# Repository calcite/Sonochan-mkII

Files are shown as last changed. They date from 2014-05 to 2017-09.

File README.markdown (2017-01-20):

# ==<| Sonochan mkII |>==
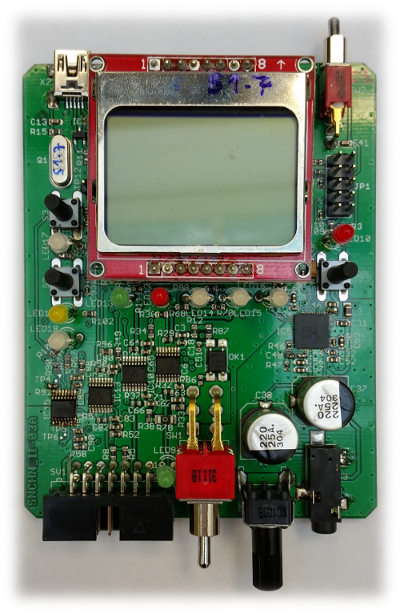
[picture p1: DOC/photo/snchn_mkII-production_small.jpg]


## Description
 * Polymorph usb soundcard (USB <--> [I2S/DSP/LJF/RJF]) based on "SDR Widget"
   project
 * On board is already codec which can sniff I2S/DSP/RJF/LJF bus
  (RX or TX data)
 * For normal operation no extra drivers needed. Using standard drivers
   included in nearly all operating systems
 * Development is also possible at Windows and Linux
 * Updating FW is possible directly through USB interface (drivers are part of
   programmer SW). No external tool needed.

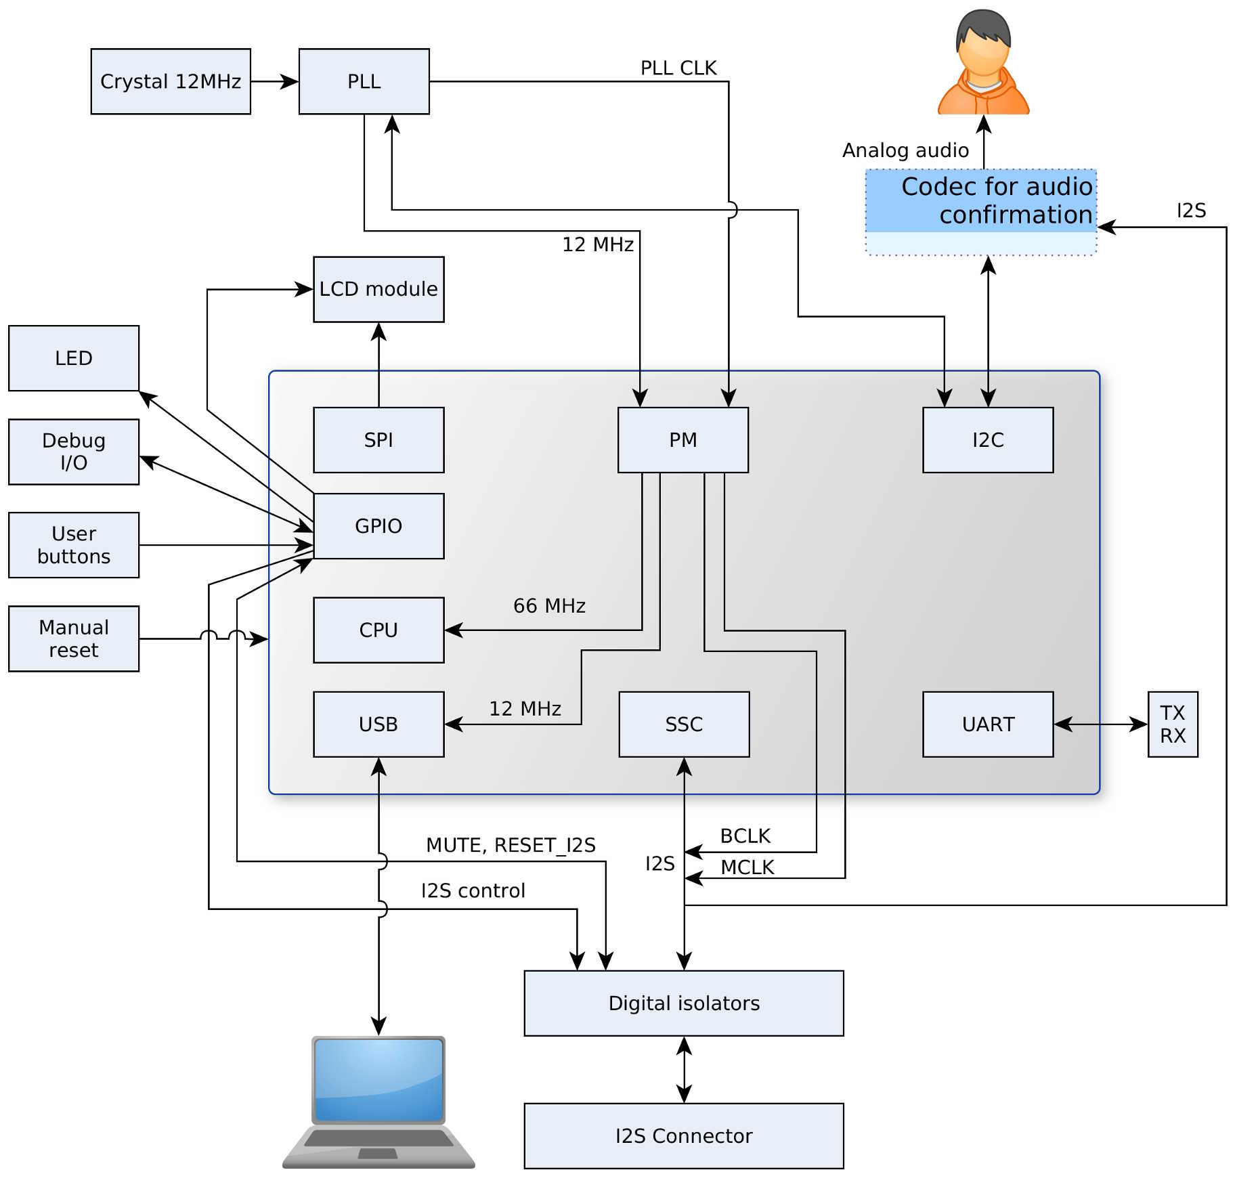
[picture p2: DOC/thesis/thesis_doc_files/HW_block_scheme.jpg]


## Parameters
 * CPU: AVR32 UC3A3256
 * As clock source generator is used CS2200
 * On board is DAC TLV320AIC33 
 * Supported sampling frequencies: 8000, 11025, 16000, 22050, 24000, 32000,
   44100 and 48000 Hz
 * Supported digital audio interfaces: I2S, DSP, Left justified,
   Right justified
 * Bit precision: up to 24 bit
 * Control thru USB HID (HW bridge uniprot)
 * Device is highly configurable (master/slave, BCLK oversampling, MCLK
   oversampling, MCLK offset, word offset, word precision...)
 * Debug messages can be sent through UART interface (115200-8-N-1). This pin
   is wired out to 2.54 pin header -> easy to connect

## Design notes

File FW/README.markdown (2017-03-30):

# Preamble
 * IF YOU WANT MODIFY FW, PLEASE READ THIS PARAGRAPH !!!
 * Please, please and once more please DO NOT USE "TABS"! I spend on this
   project more than 2 years and tabs do only problems. Just use SPACES
   instead (2 SPACES for offsets).
 * Why spaces instead of tabs? Because tab interpretation can be at every
   editor different. So when somebody change code and someone other want
   to read it, it can be very hard to read. And because tab length is not
   strictly defined, line length could be over 80 characters. Maybe you do not
   realize, but even nowadays 80 characters length have meaning (specially if
   you develop on laptop/netbook, which have small display).
 * Please also try to keep line length UP TO 80 CHARACTERS. Keep compassion
   with those they do not have large display.
 * When you use spaces, wide is strictly defined and it displays to all users
   same. No doubt about it. Also in Python is recommended to use spaces instead
   of tabs, so it is good habit for Pythonists.
 * Bottom line: USE SPACES (2 for offset) and DO NOT WRITE MORE THAN 80
   CHARACTERS AT ONE LINE.
 * Thanks                         Martin Stejskal

# Compilation

## Compilation under Linux
 * As first make sure, that you have installed `make` (Try type `make`to
   console). If appears something like `command not found`, then you
   need to install `make` (please use uncle Google)
 * Open file `compile_on_linux.sh` and edit line begun with
   `PATH=${AVR32BIN:=` . Just change path to `avr32-bin` command. Example:
`PATH=${AVR32BIN:=/opt/non-portage/avr32-tools/bin}:$PATH`
 * Make sure, that heareds were copied to `avr32-tools/avr32/include/`
   else compilation will fail.
 * If needed `chmod 755 compile_on_linux.sh` (script will be executable)
 * run `./compile_on_linux.sh` 

## Compilation under Windows
 Basicly project need only `make` (and basic programs like `rm`, `cp` and so
 on), `objcopy`, `avr32gcc` and standard AVR32 libraries.
 So easiest way is install Atmel Studio 6 and just set correct paths in file
 `compile_on_windows.bat`. Or you can install just basic programs
 (MinGW, avr32-gnu-toolchain) and set correct paths. It is up to you.

### With AVR Studio 6
 * Prepare yourself few coffees, get ready and install AVR Studio 6
 * If you using old WinXP, install Service Pack 3 first. It is required anyway
 * To make your journey easy, install it to default location
   (`C:\Program files\`)
 * Check paths in `compile_on_windows.bat`. Probably with new versions it will
   be changed. So for example if you use old Atmel Studio 6.0, you will need
   to change paths for sure.
 * Run `compile_on_windows.bat` in console. If fails, then open this file and
   edit variables `PATH_TO_MAKE` (where is `make.exe`) and `PATH_TO_GCC`
   (`avr32-gcc.exe`).
 
### MinGW and avr32-gnu-toolchain
 * Open `compile_on_windows.bat` in your favorite text editor
 * Edit variables `PATH_TO_MAKE` (where is `make.exe`), `PATH_TO_GCC`
   (`avr32-gcc.exe`) and `PATH_TO_OBJCOPY` (`objcopy.exe`)
 * Run `compile_on_windows.bat` in console

# Updating firmware
 * This process delete all user settings! So please backup your device settings
   if you need it.
 * Because this device is still under development and probably for a long time
   will be, it is good to know how to update firmware.

## Updating under Linux
 * Because avrdude does not support AVR32 (yet), it is not possible to update
   firmware through JTAG. However AVR32 chips are usually sold with
   bootloader, so you can update firmware without need HW AVR programmer.
   It is more safe and faster.
   
### Updating by DFU programmer
 * You will probably need `dfu-programmer`. It is usually part of package
   system, so there should not be problem. At Ubuntu like system just type:
   `sudo apt-get install dfu-programmer`
   If you really like compiling source codes and you are using Gentoo, then:
   `sudo emerge -v dfu-programmer`
 * Be sure, that dfu-programmer version is at least `0.7.2`! Old versions have
   some issues with programming user flash and unfortunately this function is
   needed.
 * Connect device to PC.
 * Then hold `DAI Reset` (`I2S Reset` at old versions) button and press for
   brief moment `Reset` button.
 * Release `DAI Reset` button. Screen back light should be off and your PC
   should recognize new device. This you can verify by using `lsusb` command.
   You should see something like this:
   `03eb:2ff1 Atmel Corp.`
   This indicate that bootloader is ready. 
 * Run script `./update_fw_linux.sh`
   Script should do everything automatically. If there is some problem,
   script will tell you (and then please check log).

## Updating under Windows
 * There are 2 options: JTAG and DFU. JTAG allow debug and do awesome stuff,
   but sometimes stepping cause side effects, so debugging is useless. Also
   some AVR programmer is needed. If you use DFU option, you just need usb
   cable, but debugging is quite hell. However for updating firmware it is
   enough.
 * And one more IMPORTANT thing about debugging: bootloader HAVE TO be ERASED!
   So in Atmel Studio you will need to erase whole chip before starting
   debugging. Keep this in mind.

### Updating by Flip
 * The "less evil way" is to get Flip application (hopefully still on Atmel
   site).
 * Now connect device through USB cable to PC.
 * Then hold `DAI Reset` (`I2S Reset` at old versions) button and press for
   brief moment `Reset` button.
 * Release `DAI Reset` button. Screen back light should be off and your PC
   should recognize new device.
 * Windows probably does not know device, so you have to install drivers
   manually. Luckily developers at Atmel think about this. Drivers are part of
   Flip application (usb folder).
 * Check path variable in `update_fw_windows.bat` file.
   Now you can run script `update_fw_windows.bat`. Script should do all
   annoying routines.

### Updating by DFU programmer
 * This tool is usually also available for Windows. Just use Google and be sure
   you are downloaded at least version `0.7.2`.
 * It is recommended to unpack DFU programmer to
   `C:\Program Files\dfu-programmer-win\`
   So you can use default script without modifying it. Anyway if you put it to
   different folder, just be sure you changed path in
   `update_fw_windows_dfu-programmer.bat`
 * Connect device to PC.
 * Then hold `DAI Reset` (`I2S Reset` at old versions) button and press for
   brief moment `Reset` button.
 * Release `DAI Reset` button. Screen back light should be off and your PC
   should recognize new device. 
 * For the first time Windows probably did not recognize bootloader. So you
   have to manually point to drivers. But do not be afraid. Drivers are part
   of DFU programmer package. So install these drivers if it is necessary.
 * Then just run `update_fw_windows_dfu-programmer.bat` script and if necessary
   change paths.

### Using JTAG programmer
 * Allow easy debugging, but reprogramming by JTAG can cause erasing whole
   flash memory (include bootloader!!!). In FW/Release there are .bat scripts
   for some most famous Atmel programmers, so you can use/modify them.
 * Anyway, this method is NOT RECOMMENDED for non-developers.
      
# Restoring bootloader
 * As mentioned above, if you use JTAG programmer, bootloader can be eased.
   Of course Atmel provide many documents about this, but they are very old
   and refer to old tools, which are not available. Furthermore their
   bootloader image files did not worked for me (for unknown reason).
   Long story short: there is prepared script which recover bootloader.
   Surprisingly it is located in "bootloader" folder.
 * So far is tested only AVR dragon, but feel free to modify script for other
   programmers. It is not so difficult :)
 * Just be sure, that paths in `dragon_upload_bootloader.bat` are correct.
 * Run `dragon_upload_bootloader.bat`

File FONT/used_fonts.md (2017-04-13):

# Used fonts
 * For desingning case stickers were used following fonts:
  `AGENCYB.TTF AGENCYR.TTF FuturaCE-BoldOblique.otf`

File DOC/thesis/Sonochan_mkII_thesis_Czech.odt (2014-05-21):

VYSOKÉ UČENÍ TECHNICKÉ V BRNĚ

BRNO UNIVERSITY OF TECHNOLOGY

FAKULTA ELEKTROTECHNIKY A KOMUNIKAČNÍCH TECHNOLOGIÍ

#### ÚSTAV RADIOELEKTRONIKY

FACULTY OF ELECTRICAL ENGINEERING AND COMMUNICATION

#### DEPARTMENT OF RADIO ELECTRONICS

POLYMORFNÍ USB – I²S ROZHRANÍ

POLYMORPHIC USB – I²S INTERFACE

DIPLOMOVÁ práce

MASTER´S thesis

AUTOR PRÁCE Bc. Martin stejskal

AUTHOR

VEDOUCÍ PRÁCE ing. Martin friedl

SUPERVISOR

BRNO 2014

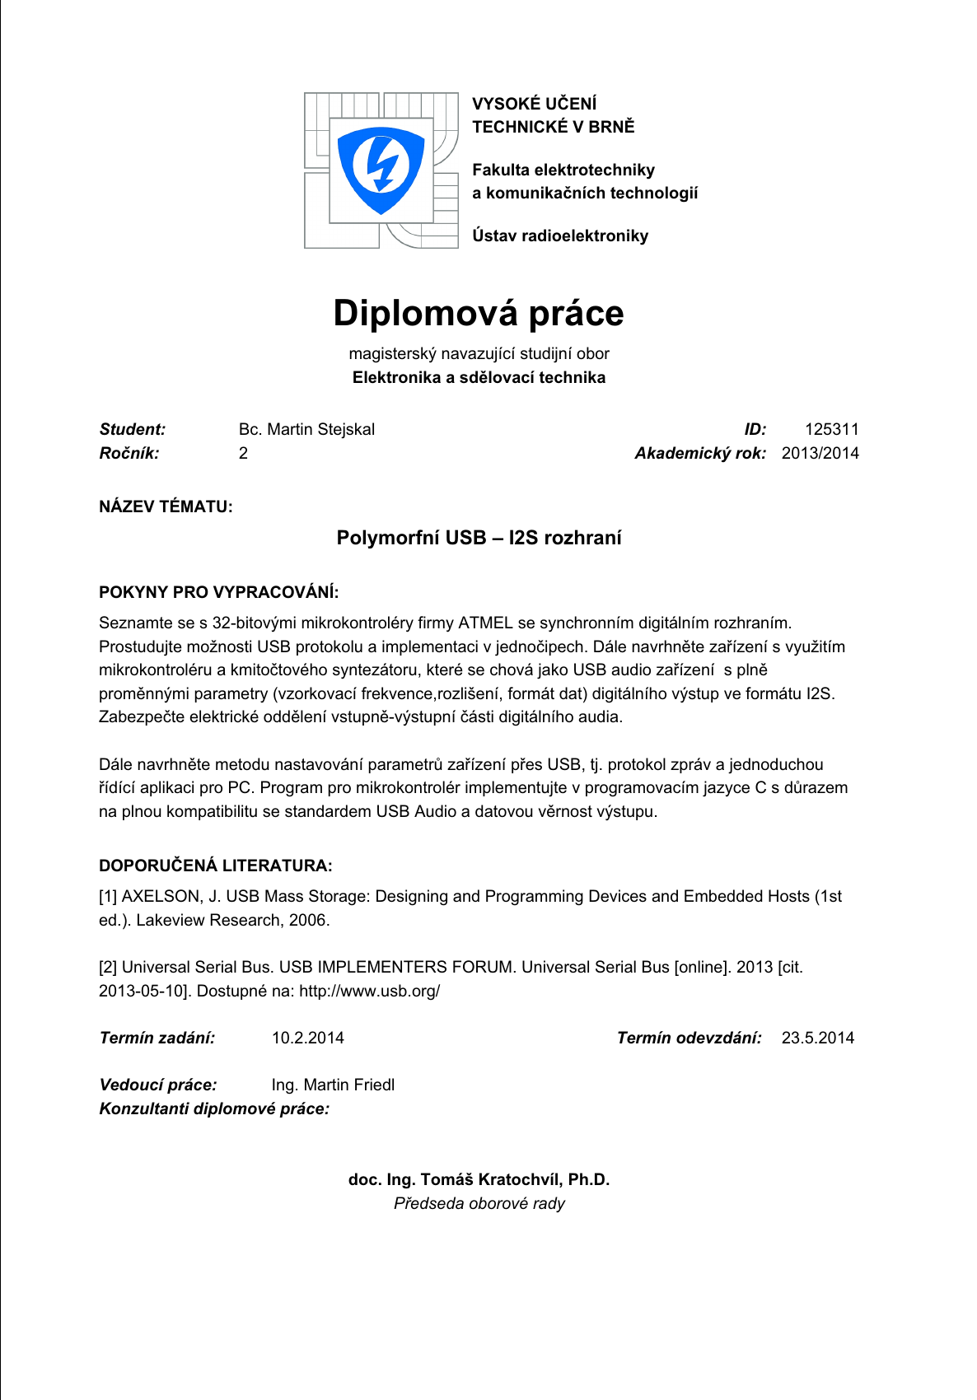
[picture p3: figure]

Abstrakt

Cílem práce bylo seznámit se s 32bitovými MCU od firmy ATMEL, synchronním digitálním rozhraním a implementaci USB protokolu v MCU. Na základě těchto poznatků navrhnout zařízení které se chová jako USB audio s plně proměnnými parametry s digitálním výstupem ve formátu I²S.

Klíčová slova

AVR32, UC3, USB, I²S, zpracování dat

Abstrakt

The thesis goal was introduce with 32-bit microcontrollers produced by ATMEL, synchronous digital interface and implementation USB protocol in MCU. On base of this informations design device which have behaviour as USB audio with fully variable parameters and digital output in I²S format.

Keywords

AVR32, UC3, USB, I²S, data processing

STEJSKAL, M. Polymorfní USB – I²S rozhraní. Brno: Vysoké učení technické v Brně, Fakulta elektrotechniky a komunikačních technologií, 2014. 81 s. Vedoucí diplomové práce: Ing. Martin Friedl.

Prohlášení

Prohlašuji, že svou diplomovou práci na téma Polymorfní USB – I²S rozhraní jsem vypracoval samostatně pod vedením vedoucího diplomové práce a s použitím odborné literatury a dalších informačních zdrojů, které jsou všechny citovány v práci a uvedeny v seznamu literatury na konci práce.

Jako autor uvedené diplomové práce dále prohlašuji, že v souvislosti s vytvořením této diplomové práce jsem neporušil autorská práva třetích osob, zejména jsem nezasáhl nedovoleným způsobem do cizích autorských práv osobnostních a nebo majetkových a jsem si plně vědom následků porušení ustanovení § 11 a následujících zákona č. 121/2000 Sb., o právu autorském, o právech souvisejících s právem autorským a o změně některých zákonů (autorský zákon), ve znění pozdějších předpisů, včetně možných trestněprávních důsledků vyplývajících z ustanovení části druhé, hlavy VI. díl 4 Trestního zákoníku č. 40/2009 Sb.

V Brně dne .............................. ....................................

(podpis autora)

Poděkování

Děkuji vedoucímu práce Ing. Martinu Friedlovi a Ing. Josefovi Nevrlému za účinnou metodickou, pedagogickou a odbornou pomoc a další cenné rady při zpracování mé diplomové práce.

V Brně dne .............................. ....................................

(podpis autora)

# Seznam obrázků

Obr. 1: Časový diagram I²S protokolu (převzato z [2]) 4

Obr. 2: Zjednodušené schéma USB protokolu 6

Obr. 3: Blokové schéma USB rozhraní (převzato z [1]) 7

Obr. 4: Doporučené zapojení USB modulu (převzato z [1]) 8

Obr. 5: Použitý algoritmus pro synchronizaci audio streamu 11

Obr. 6: Blokové schéma s externím PLL 12

Obr. 7: Blokové schéma SSC jednotky (převzato z [1]) 14

Obr. 8: SSC v zapojení pro kodek (převzato z [1]) 15

Obr. 9: Blokové schéma periferie pro přerušení (převzato z [1]) 16

Obr. 10: Blokový diagram PM (převzato z [1]) 18

Obr. 11: Blokový diagram ADC (převzato z [1]) 20

Obr. 12: Blokové schéma hardwarového návrhu 22

Obr. 13: Rozmístění uživatelských periferií na desce 24

Obr. 14: Nastavení vzorkovací frekvence 31

Obr. 15: Zjednodušený diagram pro výstupní audio stream 31

Obr. 16: Řešení synchronizace pro vstupní audio stream 32

Obr. 17: Řešení synchronizace pro výstupní audio stream 33

Obr. 18: Diagram pro přenos USB HID dat 36

Obr. 19: Vývojový diagram funkce device_generic_hid_task() 37

Obr. 20: Systém komunikace jednotlivých vrstev 38

Obr. 21: Úspěšný přenos dat 43

Obr. 22: Řešení poškození dat 43

Obr. 23: Resetování ovladačů a "universal protokolu" 44

Obr. 24: Signalizace přetečení vstupního bufferu 44

Obr. 25: Data paket 45

Obr. 26: Příkazový paket 45

Obr. 27: Formát příkazu "get setting" 47

Obr. 28: Formát odpovědi na "get setting" 47

Obr. 29: Get setting - vše v pořádku 47

Obr. 30: Get setting - neplatné CMD ID 48

Obr. 31: Get setting - neplatné DID 48

Obr. 32: Formát příkazu "set setting" 49

Obr. 33: Formát odpovědi na "set setting" 49

Obr. 34: Set setting - vše v pořádku 49

Obr. 35: Formát příkazu "get metadata" 49

Obr. 36: Formát odpovědi na "get metadata" 49

Obr. 37: Get metadata - vše v pořádku 50

Obr. 38: Formát příkazu "get number of devices" 50

Obr. 39: Formát odpovědi na "get number of devices" 50

Obr. 40: Get number of devices - průběh komunikace 50

Obr. 41: Rozvrstvení aplikace pro počítač 52

Obr. 42: Schématické zapojení pro ověřování funkčnosti 55

Obr. 43: Schématické zapojení pro měření vlastností sluchátkového výstupu 55

Obr. 44: Schématické propojení testovacího zařízení a Codec Kitu 56

# Seznam tabulek

Tab. 1: Možnosti nastavení endpointů (převzato z [1]) 9

Tab. 2: Přehled možností časování mezi hostem a zařízením (převzato z [22]) 9

Tab. 3: Přehled synchronizačních metod v třídě USB audio (převzato z [10]) 10

Tab. 4: Popis vybraných parametrů kodeku (převzato z [2]) 26

Tab. 5: Přehled pinů na LCD modulu (převzato z [9]) 28

Tab. 6: Stručný přehled deskriptorů zařízení 30

Tab. 7: Popis jednotlivých interface 30

Tab. 8: Možnosti nastavení směru signálů a jejich vlastnosti 34

Tab. 9: Přehled datových typů používaných "generic driverem" 40

Tab. 10: Seznam příkazových symbolů 46

Tab. 11: Popis příkazů 46

Tab. 12: Seznam zkratek pro vrstvu „bridge“ 46

Tab. 13: Přehled parametrů při ověřování funkčnosti 55

Tab. 14: Přehled parametrů při měření vlastností sluchátkového výstupu 56

Tab. 15: Naměřené hodnoty na výstupu 56

Tab. 16: Nastavení parametrů při propojení s Codec Kitem 57

# Úvod

Cílem práce je navrhnout a sestrojit zařízení pro testování a měření systémů používajících sériové sběrnice pro digitální audio (I²S, PCM). Typickými příklady použití jsou:

- analýza a záznam datového streamu mezi audio kodekem a mikrokontrolérem s I²S periferií,
- injekce testovacího datového streamu do audio kodeku/digitálního zesilovače,
- simultánní injekce a záznam datového streamu pro test integrovaných obvodů/modulů provádějících audio DSP operace.

V současné době jsou výše zmíněné scénáře plně uskutečnitelné jen pomocí sofistikovaných měřicích systémů, jako jsou audio analyzátory s digitálním modulem, částečně pak s digitálními (MSO) osciloskopy se speciálními dekodéry.

Zařízení má být univerzální, tj. podporující co nejvíce možných nastavení frekvence a formátu dat. Dále má být snadno použitelné s již existujícími PC programy a aplikacemi, tedy chovat se jako běžné USB audio rozhraní, jaké je standardně podporováno všemi běžnými operačními systémy.

U tohoto typu zařízení je vyžadována tzv. bitová věrnost. To znamená, že data na výstupu zařízení musí přesně odpovídat původním zvukovým datům produkovaným audio aplikací běžící na PC. U běžných USB audio rozhraní nastávají problémy v případech, kdy je vzorkovací frekvence záznamu rozdílná s vzorkovací frekvencí převodníku. V takovém případě se běžně aplikuje převzorkování a filtrace signálu. Takovéto transformace dat (změna, odstraňování, přidávání) jsou však z hlediska měření nepřijatelné. Řešením je použití vždy stejné vzorkovací frekvence a dalších parametrů datového audio streamu, jaké jsou nastaveny v použité audio aplikaci na PC. Důležitou částí projektu je proto metoda flexibilního nastavení všech parametrů zařízení přes USB.

Dalším kritickým bodem je schopnost zařízení zabránit „ztrátě“ sebemenšího počtu vzorků kvůli přetečení/podtečení audio bufferu. Vzhledem k charakteru přenosu dat po USB sběrnici je v případě běžných USB audio převodníků podobná ztráta statisticky možná, při malých množstvích vzorků je však různými metodami v digitální i analogové doméně kompenzovatelná. To však opět není akceptovatelné pro případ měřicího zařízení. Problém je řešen adaptivním řízením přenosu audio dat po USB v závislosti na stavu zaplnění bufferu.

Tento dokument je rozdělen do sedmi částí. V následující kapitole je teoretický rozbor I²S a zjednodušený popis implementace USB protokolu v MCU. V další kapitole je blokové schéma zařízení a popis funkcí jednotlivých komponent. Následuje HW a poté SW řešení celého zařízení. V další kapitole je rozebrán komunikační protokol s PC aplikací. Předposlední kapitola pojednává o naměřených hodnotách. V závěru je pak shrnuta dosavadní práce na tomto projektu a nastínění dalších možností.

## Motivace návrhu

Na trhu je dostupných několik typů zařízení, které by zdánlivě mohly splnit daný účel. Avšak u každého z nich existují nevýhody, které nasazení limitují.

### Osciloskop s podporou I²S

Na trhu jsou běžně dostupné osciloskopy, které umožňují analyzovat I²S. U většiny osciloskopů je to pouze otázkou volitelné (většinou za příplatek) funkce firmwaru. Jejich výhodou je, že umožňují velice detailně zobrazovat signálové průběhy. Ale už z principu je zde limit v počtu uložených vzorků (ač osciloskopy mívají až několik desítek MB paměti), a tím i oknu, po které je možné signál analyzovat. Vzorkovací frekvenci 48 kHz s rozlišením 16 bitů odpovídá čistý datový tok 1,536 Mbit/s. Z toho plyne, že lze analyzovat pouze krátké signály. Navíc osciloskopy neumí injektovat I²S stream, a mohou tak sloužit pouze k analýze. Proto je toto řešení nedostačující.

### Audio reference od XMOS

Jako další komerčně dostupný produkt existuje audio reference od firmy XMOS [18]. Zařízení disponuje plně duplexním stereo I²S rozhraním. Připojení k počítači je možné pomocí USB, takže zpracování dat je ponecháno na libovolné PC aplikaci.

Zařízení podporuje nejpoužívanější bitová rozlišení [17]: 16, 24 a 32 bitů. Podporované vzorkovací frekvence jsou: 44.1, 48, 88.2, 96, 176.4, 192, 358.2 a 384 kHz. Bohužel zařízení nepodporuje nižší vzorkovací frekvence. Konkrétně 8 a 16 kHz, které jsou běžně využívány v digitální telefonii. Jelikož z výše uvedených důvodů není akceptovatelné signál převzorkovat, je toto řešení opět nedostačující.

### Audio analyzátor s digitálním modulem

Jedním z méně rozšířených zařízení jsou audio analyzátory. Např. firma Audio Precision nabízí hned několik typů analyzátorů s digitálním modulem [19]. Z hlediska technických parametrů jsou vyhovující (vzorkovací frekvence, bitové rozlišení, bitová věrnost, možnost odposlouchávat a injektovat audio data). Zároveň s hardwarem je dodávána i aplikace pro PC, která umožňuje audio data vyhodnocovat.

Tato zařízení většinou vyžadují instalaci specifického ovladače, takže implementace do jiných aplikací a systémů než těch dodaných výrobcem bývá složitá. Pro množství analytických a dalších funkcí je také obsluha relativně složitá. Největší nevýhodou je však cena pohybující se okolo 20 000 USD za analyzátor s adekvátní konfigurací. Toto řešení je tedy z technického hlediska vyhovující, ale z ekonomického hlediska je problematické (zvláště v případě, kdy je potřeba několik těchto zařízení).

### Vývojový kit EVK1105

Společnost Atmel nabízí vývojový kit EVK1105 a příslušný framework se zdrojovými kódy a schématy [10]. Tento vývojový kit obsahuje MCU AT32UC3A0512, který disponuje USB a sériovým digitálním rozhraním (SSC). Při drobné hardwarové modifikaci umožňuje nastavit MCU tak, aby bylo detekováno jako USB zvuková karta, která dokáže přesně reprodukovat data z aplikace běžící na PC. Zpracování dat se opět provádí na straně PC aplikace.

Původní firmware podporoval vzorkovací frekvence 32, 44.1 a 48 kHz se stereo výstupem a mono vstupem. Protože jsou k dispozici zdrojové kódy a schémata, jevila se tato varianta jako vhodná pro modifikaci. Díky tomu, že byl vývojový kit k dispozici, se usnadnilo první testování aplikace. Rozšíření podpory vzorkovacích frekvencí se ukázalo jako možné a funkčnost byla ověřena.

Problém nastal při úpravě vstupu na stereo kanál. Při vzorkovacích frekvencích 44.1 a 48 kHz byl výstupní signál silně narušen. Problém se tedy zprvu jevil jako nedostatek výpočetního výkonu. Až náročná analýza odhalila, že pro přenos audio dat je zapotřebí, aby vyrovnávací USB audio buffery byly zdvojené. Zdvojenost bufferů je nutná u datových přenosů „Isochronous“ (viz. kapitola 2.2). Právě při vzorkovacích frekvencích 44.1 a 48 kHz bylo posíláno již takové množství dat, že hardwarové USB buffery nestačily, takže jejich obsah byl přepsán. To způsobovalo výpadky vzorků, a tudíž degradaci signálu. Kvůli degradaci signálu se toto řešení ukázalo jako nevhodné.

### Projekt SDR-Widget

Open source projekt SDR-Widget, který je licencován pod GPL-2.0, si dal za cíl vytvořit zvukovou kartu, která bude v mnohém podobná variantě od společnosti Atmel [13], ale s plnou podporou stereo kanálů v obou směrech. Oba projekty používají 32bitovou architekturu Atmel UC3, jsou bitově věrné, nabízí zdrojové kódy a schémata. Rozdíly jsou především v použitých variantách MCU, dalším použitém hardwaru, datové propustnosti (souvisí s USB periferií a její velikostí RAM), ovládacím softwaru a podpoře USB audio class 2 (viz. níže).

Díky tomu, že bylo použito MCU AT32UC3A3256, bylo možné vyřešit problém stereo kanálů i při vyšších vzorkovacích frekvencích. Tato karta může pracovat v několika módech, přičemž nejuniverzálnější je varianta s podporou USB audio class 1, která je kompatibilní s většinou operačních systémů. V této třídě zařízení (resp. firmware) podporuje pouze dvě vzorkovací frekvence: 44.1 a 48 kHz.

Limitující u USB audio class 1 je ve velikosti paketu odesílaného každou milisekundu [20]. Paket může maximálně obsahovat 1024 Bajtů. Například při vzorkovací frekvenci 176 kHz, bitovém rozlišení 24 bitů stereo vychází velikost paketu 1056 B (176*3*2). Velikost tohoto paketu přesahuje maximum a tuto kombinaci nelze v USB audio class 1 implementovat. Proto byla v roce 2009 [20] vydána nová verze (USB audio class 2), která umožňuje přenést větší objemy dat. Zde je problém s operačními systémy Windows. Nativně standard nepodporují ani nejnovější Windows 8.1 [21]. Projekt SDR-Widget podporuje oba standardy.

Vzhledem k zaměření projektu byla preferována univerzálnost USB audio class 1, i za cenu chybějící podpory dalších vzorkovacích frekvencí. Cenová bilance na výrobu jednoho kusu (DPS, součástky a krabička) se pohybuje okolo 220 USD. Při výrobě deseti kusů je cena jednoho kusu pouze 150 USD. Tento projekt byl proto zvolen jako základ, na kterém je vystavěna tato diplomová práce.

# Teoretický rozbor

Jak bylo uvedeno v úvodu, pro co nejvěrnější podání nahrávky je potřeba, aby zařízení mělo proměnné parametry jak časové základny (vzorkovací frekvence), tak bitového rozlišení (délka slova, formát). To však naráží na problém s různým časováním různých periferií. Například pro funkci USB je potřeba takt hodin 48 MHz [1], ale přitom potřebujeme, aby I²S rozhraní běželo na taktu 11,2896 MHz, 12,288 MHz, 8,192 MHz apod. To jsou neceločíselné násobky od 48 MHz, takže obyčejná dělička zde nestačí. Právě MCU UC3A umožňují dvojí hodiny [1], čímž se částečně řeší problém s dvojím taktováním. Takt pro USB je odvozen z 12 MHz krystalu a takt pro I²S rozhraní je řízen PLL, které je nastavováno přes I²C sběrnici.

## Protokol I²S

Přenášet zvuk v digitální formě po synchronní sběrnici jde několika způsoby. V průběhu času se rozšířily především následující standardy [2]:

- Right justified (zarovnání bitů vpravo),
- Left justified (zarovnání bitů vlevo),
- I²S,
- DSP.

Principiálně jsou si jednotlivé možnosti velice podobné, avšak liší se v detailech. Zařízení komunikující s počítačem často využívají právě I²S. Datový tok výstupních dat je synchronní se vstupním tokem dat (digitalizovaného zvuku). Časový diagram pro I²S je na Obr. 1.

Popis jednotlivých signálů:

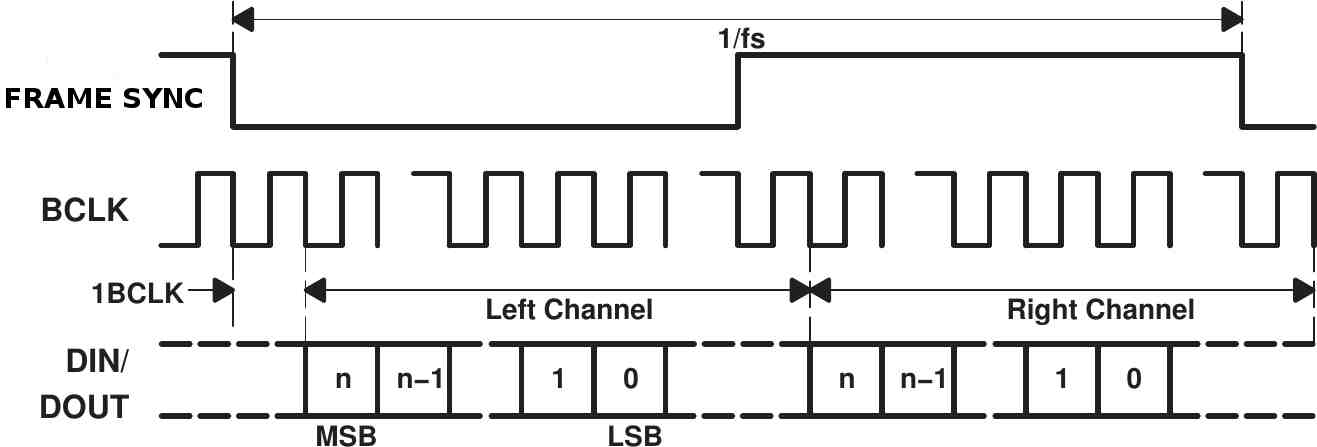
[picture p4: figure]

Obr. 1: Časový diagram I²S protokolu (převzato z [2])

- FRAME SYNC – synchronizace rámce. Také určuje, zda jsou data určena pro levý, nebo pravý kanál
- BCLK – bit clock. Pro synchronizaci jednotlivých datových bitů. Takt bit clocku se dá vypočítat následovně:

f sub BCLK = f sub SAMPLE cdot (sample precision) | (1.1)
kde fSAMPLE je vzorkovací frekvence, sample precision je typicky bitové rozlišení datového slova. Sample precision udává počet bitů (datové + nuly) v jedné periodě signálu FRAME SYNC.

- DIN/DOUT – vstupní/výstupní data (bráno z pohledu tohoto zařízení) – zvuk reprezentovaný ve vzorcích.

Teoreticky by tyto 4 signály stačily na plně duplexní stereo přenos. V praxi je ale často přidáván signál MCLK (master clock), který je určen pro kodek nebo další I²S zařízení. Bývá násobkem BCLK, v praxi jsou nejběžnější násobky 32, 64, 128 a 256 BCLK. Většina kodeků má již integrovanou děličku, takže při změně vzorkovací frekvence není potřeba měnit MCLK. Většinou stačí jen vhodně nastavit kodek. Bývá zvykem, že BCLK, FRAME SYNC a DOUT jsou pro master výstupní signály a DIN je vstupní (z pohledu master). Pokud bude zařízení ve slave módu, pak z jeho pohledu budou BCLK, FRAME SYNC a DIN brány jako vstupní. Naopak DOUT bude brán jako výstupní.

## Základy USB protokolu a jeho implementace v MCU

Protože USB protokol je komplexní a na implementaci náročný, některé mikrokontroléry už jej částečně podporují na hardwarové úrovni. Vzhledem k možnostem USB je nutné nejprve detailně nastavit USB rozhraní a pak provést inicializaci samotné USB sběrnice.

USB zařízení se může chovat jako USB Device, USB Host nebo jako On-The-Go (OTG) [3]. Mód USB Device je pro zařízení, která se připojují do USB sběrnice. Tedy například flash disk, myš, klávesnice apod. Mód USB Host je přesný opak. Jak už název napovídá, jedná se o zařízení, které „má na starost“ jednotlivé USB Device a řídí tok na sběrnici. Z pohledu uživatele se jako „USB Host“ jeví počítač. Poslední mód, „On-The-Go“, je kombinace předchozích dvou. Zařízení se může chovat jako „USB device“, ale i jako „USB Host“. Toho je využíváno například u tiskáren. Pokud je tiskárna připojena k počítači, pak vyžadujeme, aby se tvářila jako „USB device“, ale v případě, že potřebujeme vytisknout nějaký obrázek nebo dokument, například z flash paměti, pak se musí chovat jako „USB Host“. Právě mikrokontroléry UC3 podporují mód „On-The-Go“, takže z hardwarového hlediska není problém používat mikrokontrolér v obou módech. Komponenta zodpovědná za komunikaci v módu „USB Host“ se nazývá host controller, zkráceně host. V textu je použit kratší název: host.[^1].

Protokol USB umožňuje komunikovat v několika módech:

- Control,
- Interrupt,
- Bulk,
- Isochronous.

Mód „Control“ se používá především pro inicializaci. Nic ale nebrání tomu, aby zařízení komunikovalo právě přes tento mód. Velmi jednoduché USB zařízení využívají tento mód. Pro nenáročnou komunikaci se používá „Interrupt“ mód. Tento mód je vhodný pro aplikace, kdy vyžadujeme periodicky posílat malé množství dat. V tomto módu fungují například myši a klávesnice. Pokud je vyžadováno přenášet velké množství dat a kontrolovat při tom, zda všechna data byla úspěšně přenesena, pak je zde „Bulk“ mód. V tomto módu pracují typicky flash disky. Pro případy, kdy je potřeba přenášet data synchronně, ale nevadí větší BER (bitová chybovost), je zde mód „Isochronus“. Ten je často používán pro audio aplikace. Vzhledem k tomu, že u tohoto zařízení je vyžadováno, aby vzorky byly přijaty všechny a spolehlivě, byl by vhodnější „Bulk“ mód. Protože je však požadováno, aby zařízení bylo použitelné na většině operačních systémů bez nutnosti instalaci ovladačů, je nutné používat pro přenos audio dat mód „Isochronus“. Níže bude podrobněji vysvětleno proč.

Pro prvotní komunikaci s USB zařízením je použit mód „Control“. V tomto módu si host obvykle zažádá zařízení o tzv. „Device Descriptor“. Zde je uložena informace VID (Vendor ID) a PID (Product ID). Díky těmto ID je OS schopný nahrát správný driver pro zařízení v případě, že zařízení nepoužívá jeden ze standardních tříd zařízení. Jako další jsou zde „Configuration Descriptors“. Těch může být několik. Každý pak popisuje jednu konfiguraci zařízení. V každé konfiguraci může zařízení vykonávat stejné funkce, ale může se lišit v drobných detailech (např. použitý mód, velikost přenášených dat atd.). V praxi ale zařízení mívá jen jednu konfiguraci, která se nemění. Každá konfigurace obsahuje jeden nebo více interface. Každý interface popisuje, v jakém módu se data budou přenášet, zda se budou data přenášet v některém z předdefinovaných standardů (HID, audio, …), kam se v paměti budou ukládat (do jakého endpointu), jaké množství dat se bude přenášet atd.

Jako příklad si můžeme představit multifunkční tiskárnu, která obsahuje i scanner. Fyzicky se jedná o jedno zařízení s jedním USB portem, ale uživatel v OS vidí dvě zařízení. Tato jednotlivá zařízení OS rozpozná podle deskriptorů interface. Každé toto virtuální zařízení může obsahovat jedno, nebo více interface. Interface určuje svoje endpointy. Do těchto endpointů jsou ukládána surová data, případně se z těchto endpointů načítají data, která mají být odeslána. Endpointy existují jak na straně device (zařízení), tak na straně hosta (počítače). Jednotlivé endpointy jsou „propojeny“ pomocí tzv. „pipes“ (roury), což je abstrakce pro datový kanál. Zjednodušené obecné schéma je na Obr. 2.

Aby uživatel nemusel pro každé USB zařízení instalovat specifický ovladač (typu myš, klávesnice), byly v USB standardu definovány třídy zařízení („device classes“), které definují, jaké má mít interface nastavení, aby se k němu přistupovalo podle předdefinovaných konfigurací. Do těchto tříd spadají klávesnice, myši, flash disky, síťové karty, bluetooth moduly, zvukové karty, HID, tiskárny apod.

Obr. 2: Zjednodušené schéma USB protokolu

Směr všech USB dat je definován z pohledu hosta. To znamená, že pokud data proudí směrem od zařízení k hostu, vždy jsou označena jako vstupní, a to i na straně zařízení! A naopak. Pokud proudí data od hosta směrem k zařízení, jsou vždy označena jako výstupní.

Pro správnou funkci vyžaduje USB modul na UC3A3256 12 MHz zdroj hodin. Ten může být generován pomocí interních PLL (fázových závěsů) a například krystalu (viz. kapitola Power Management - PM). Tento takt je pak použit pro generování 480 MHz (v případě high-speed) bit clocku. Pro obnovu je použit DPLL (není na blokovém schématu). Blokové schéma je na Obr. 3.

Pro napájení USB modulu je zapotřebí pin USB_VBUS připojit na +5V. Pin USB_ID slouží pro identifikaci konektoru, resp. je možné detekovat, jestli se jedná o konektor pro „USB host“, nebo „USB device“. Vzhledem k tomu, že zařízení bude pracovat pouze jako „USB device“, nebude tato funkce rozebírána podrobněji. Diferenční páry pro USB jsou rozděleny na „full-speed“ a „high-speed“, ale podle doporučeného zapojení by měly být propojeny přes externí rezistory. Doporučené zapojení pro USB modul je na Obr. 4.

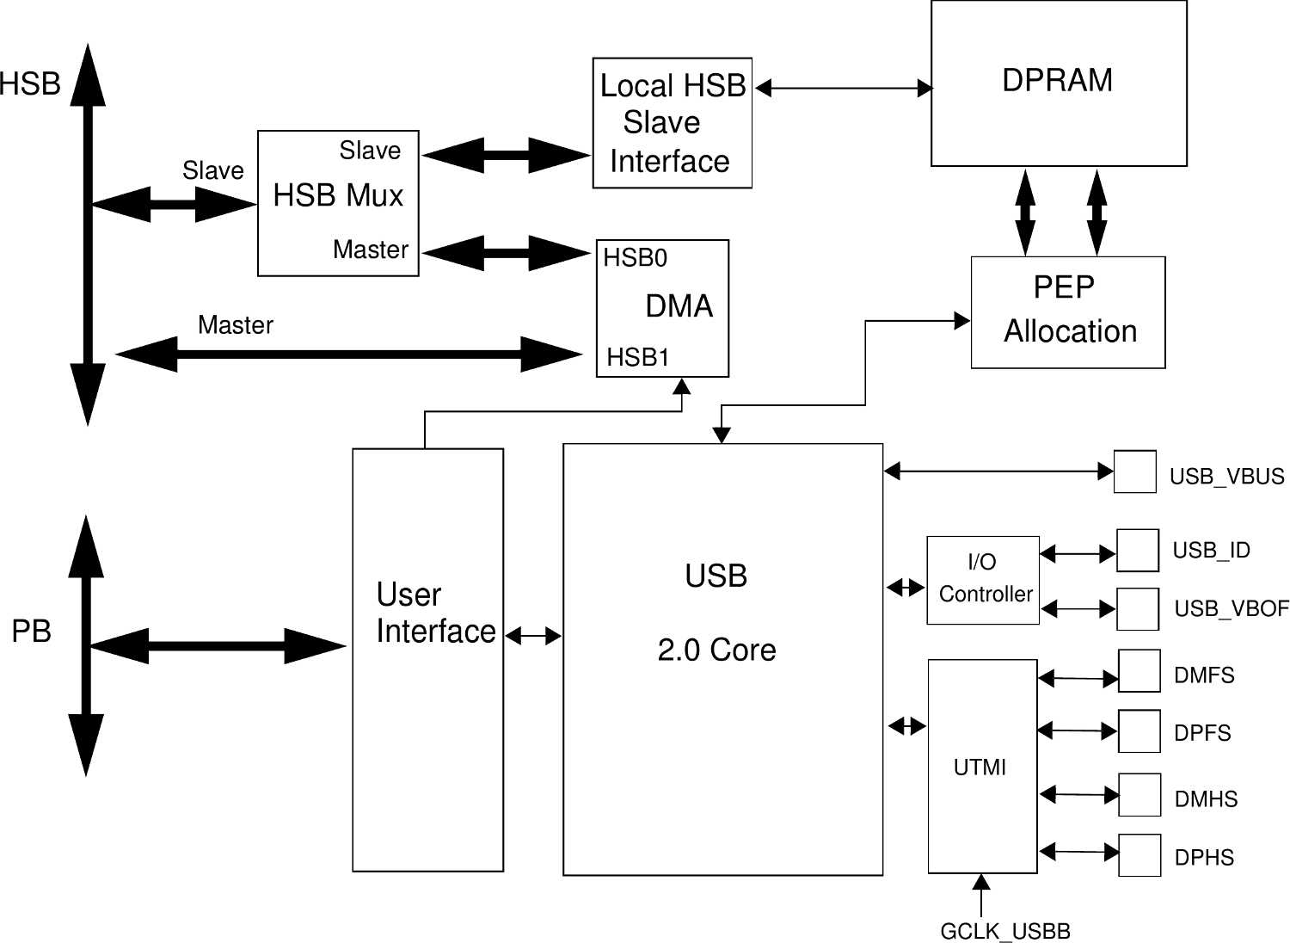
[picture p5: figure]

Obr. 3: Blokové schéma USB rozhraní (převzato z [1])

Celý modul disponuje velkým množstvím možných přerušení a to na několika úrovních. Počínaje přerušením na nejnižší úrovni (zařízení připojeno, odpojeno, počátek rámce, atd.) přes přerušení od pipe (data přijata, data odeslána) až po přerušení od DMA (přímý přístup do paměti).

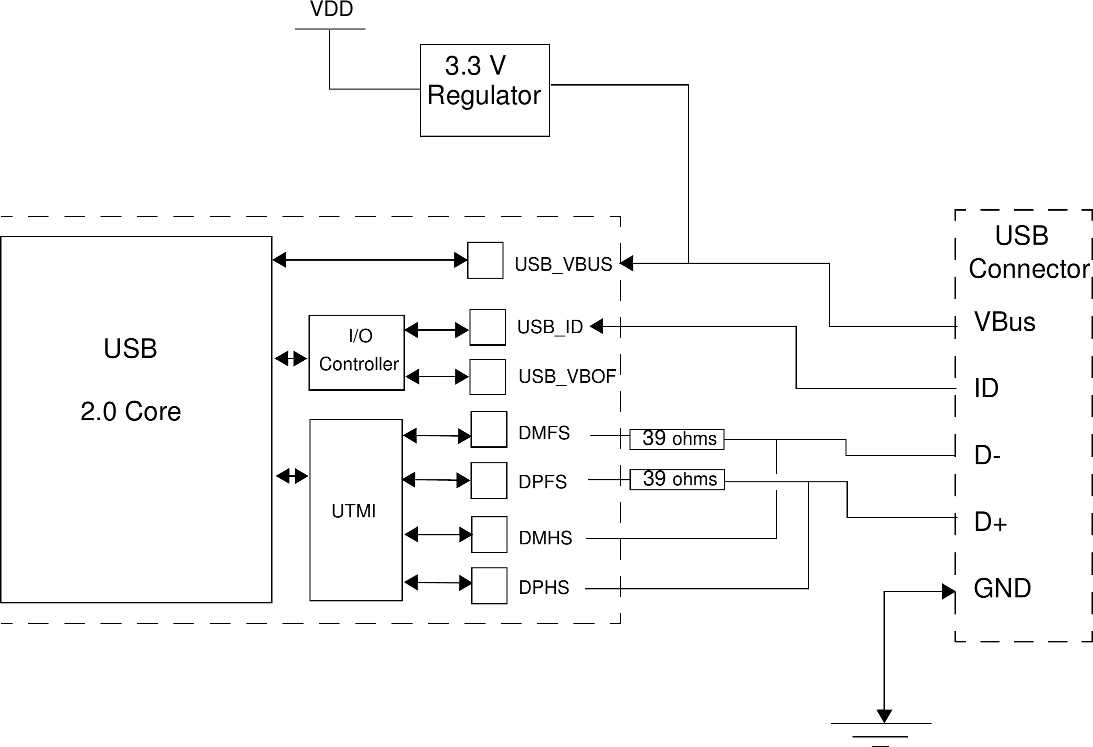
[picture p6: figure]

Obr. 4: Doporučené zapojení USB modulu (převzato z [1])

Dále je na čipu integrovaný obvod „plug-in detection“. Tento obvod sleduje napájecí napětí a napětí na diferenčním páru. Pokud jsou splněny podmínky, pak obvod generuje signál, který informuje vyšší vrstvy o tom, že je USB sběrnice připojena.

Hardwarově je modul připraven až pro 8 endpointů, včetně „control“ endpointu. Pro ukládání zpracovaných dat je zde připravena DPRAM (dvouportová RAM), která umožňuje uložit až 2368 B. Teoreticky však lze nakonfigurovat tak, aby celkový datový tok byl posílán po 3648 B. V takovém případě by obsah DPRAM byl přepsán. Proto je nutné napsat program tak, aby velikost endpointů (EP) nepřekročila danou mez. Ovšem ne každý EP může být konfigurovaný libovolně. Zjednodušený popis parametrů a omezení je v tabulce Tab.1.

Tab. 1: Možnosti nastavení endpointů (převzato z [1])

Endpoint | Podpora DMA | Podporované typy přenosu | Maximální velikost EP [B]
0 | Ne | Control | 64
1 | Ano | Isochronus/Bulk/Interrupt/Control | 512
2 | Ano | Isochronus/Bulk/Interrupt/Control | 512
3 | Ano | Isochronus/Bulk/Interrupt | 512
4 | Ano | Isochronus/Bulk/Interrupt/Control | 512
5 | Ano | Isochronus/Bulk/Interrupt/Control | 512
6 | Ano | Isochronus/Bulk/Interrupt/Control | 512
7 | Ano | Isochronus/Bulk/Interrupt/Control | 512

To, jestli bude USB rozhraní pracovat v tzv. „low-speed“, „full-speed“ nebo „high-speed“ módu, rozhoduje pull-up rezistor připojený na diferenční sběrnici. Tyto módy v podstatě určují maximální možnou přenosovou rychlost dat. Pokud bude pull-up připojen na D-, pak bude zařízení pracovat v „low-speed“ módu. Jestliže bude pull-up připojen na D+, pak bude zařízení pracovat v „full-speed“ módu. Pokud má zařízení pracovat jako „high-speed“, musí se nejprve inicializovat stejně jako „full-speed“ zařízení a poté přepne na vyšší přenosovou rychlost [12]. Tyto pull-up rezistory jsou již integrovány na čipu, takže pro jejich aktivaci stačí jen nastavit dané registry a není nutné osazovat DPS dalšími součástkami.

Jak již bylo naznačeno výše, existuje třída USB audio class 1, která definuje, jaký ovladač má být na straně PC použit. Výhodou tohoto standardu je, že je podporován většinou OS. Pokud bude použita tato třída, odpadá tím řešení ovladače na straně PC. Na druhou stranu odesílání a přijímání audio dat ve třídě USB audio je omezeno na mód „Isochronous“. Ten způsobí, že audio data nebudou zabezpečena (host se nestará o to, zda data byla úspěšně přijata). Výhodnější by tedy bylo použít mód „Bulk“. To by ale obnášelo vytvoření ovladačů pro PC. Vzhledem k časovým možnostem tak byla zvolena varianta, ve které je použita třída USB audio. Samotná třída USB audio class 1 pak nabízí tři možnosti nastavení, které definují časování mezi hostem a zařízením. Od toho se pak odvíjí hardwarové zapojení a možná řešení synchronizace. Stručný přehled poskytuje Tab. 2.

Tab. 2: Přehled možností časování mezi hostem a zařízením (převzato z [22])

Metoda | Popis
Synchonous | Periodu udává host. Zařízení musí být schopno zpracovávat data na periodě udávané hostem. Tato metoda není pro měřící účely příliš vhodná, protože počítače nemají příliš přesný a stabilní zdroj hodin.
Asynchonous | Periodu udává zařízení. Host přizpůsobuje množství dat podle zpětné vazby od zařízení. Ideální pro měřicí a Hi-Fi zařízení. Obecně mají zařízení mnohem stabilnější a přesnější zdroj hodin. Tato metoda je použita v navrhovaném zařízení.
Adaptive | Perioda je dána datovým tokem. Tato metoda není vhodná kvůli nestabilním a nepřesným zdrojům zdrojům hodin v počítačích.

## Řešení synchronizace audio streamu

Hodiny pro USB a SSC (sériové synchronní rozhraní) lze považovat za nezávislé už jen kvůli rozdílným časovým základnám. Lze tedy očekávat mezi jednotlivými časovými základnami drift. Ten musí být kompenzován, jinak se začne buffer pro audio vzorky buďto zaplňovat, nebo vyprazdňovat rychleji, než je potřeba. Aby nedošlo k přetečení nebo podtečení, je potřeba tento drift korigovat. V USB standardu jsou definovány 4 možnosti [10]. Shrnutí jejich výhod a nevýhod je v Tab. 3.

Tab. 3: Přehled synchronizačních metod v třídě USB audio (převzato z [10])

Synchronizační metoda | Výhody | Nevýhody
A) Vkládání/odstraňování vzorků | Velice jednoduché Minimální nároky na HW | Zkreslení signálu v závislosti na rozdílech vzorkovacích frekvencí
B) Použití přesné PLL | Jednoduchá implementace Minimální nároky na HW Bitově přesná kopie 1:1 | Nutnost externí přesné PLL Absolutní hodnota vzorkovací frekvence se mírně mění (v řádech 10 ppm)
C) Adaptivní převzorkování | Menší zkreslení než řešení A | Zkreslení signálu kvůli převzorkování Náročné na HW
D) Použití zpětnovazebního EP | Jednoduchá implementace Bitově přesná kopie 1:1 | Některé starší OS jej nemusí nativně podporovat (např. Windows XP)

U metody B je perioda dána hostem. Metoda B sice nabízí bitově věrný přenos, ale jak bylo vysvětleno v předchozí podkapitole, časování podle hosta není vhodné pro měřící účely. V důsledku přelaďování PLL se absolutní hodnota vzorkovací frekvence mírně mění. Zdroj hodin se pak pro ostatní zařízení jeví jako časově nestabilní (změny v desítkách ppm). Proto je o něco vhodnější metoda D. U metody D udává periodu zařízení, což je mnohem vhodnější. Při přehrávání program sleduje zaplnění výstupních bufferů a podle aktuálního vytížení pošle zpětnovazebním EP informaci o tom, kolik má host (PC) přenést dat. Naopak pokud zařízení odesílá audio data hostu, tak rozhoduje kolik dat pošle v závislosti na tom, kolik dat má k dispozici (jak je zaplněn vstupní buffer). Díky tomu není potřeba měnit frekvenci externího PLL (od které je odvozen MCLK, BCLK a FRAME_SYNC) a výstupní vzorkovací frekvence bude stabilní jako její zdroj.

Protože metoda D nemusí být podporována ve starších OS, zařízení využívá kombinaci metod D a B. Při inicializaci nahlásí OS používanou metodu D. Pokud je vše v pořádku, pak se tato metoda používá po celou dobu komunikace s hostem. V momentě, kdy metoda D není podporována, výstupní buffery se začnou plnit, nebo podtékat. V tento moment program přenastaví externí PLL podle aktuálních potřeb tak, aby nedošlo k podtečení nebo přetečení bufferu a zároveň aby změna byla co nejmenší. Host o této změně není a nemusí být informován a přesto nedojde (za normálních podmínek) k přetečení nebo podtečení bufferů. Protože digitální vstupní a výstupní audio moduly (SSC) jsou synchronní, neměly by přetéct/podtéct ani vstupní buffery. Zjednodušený vývojový diagram na Obr. 5 popisuje, jak funguje algoritmus.

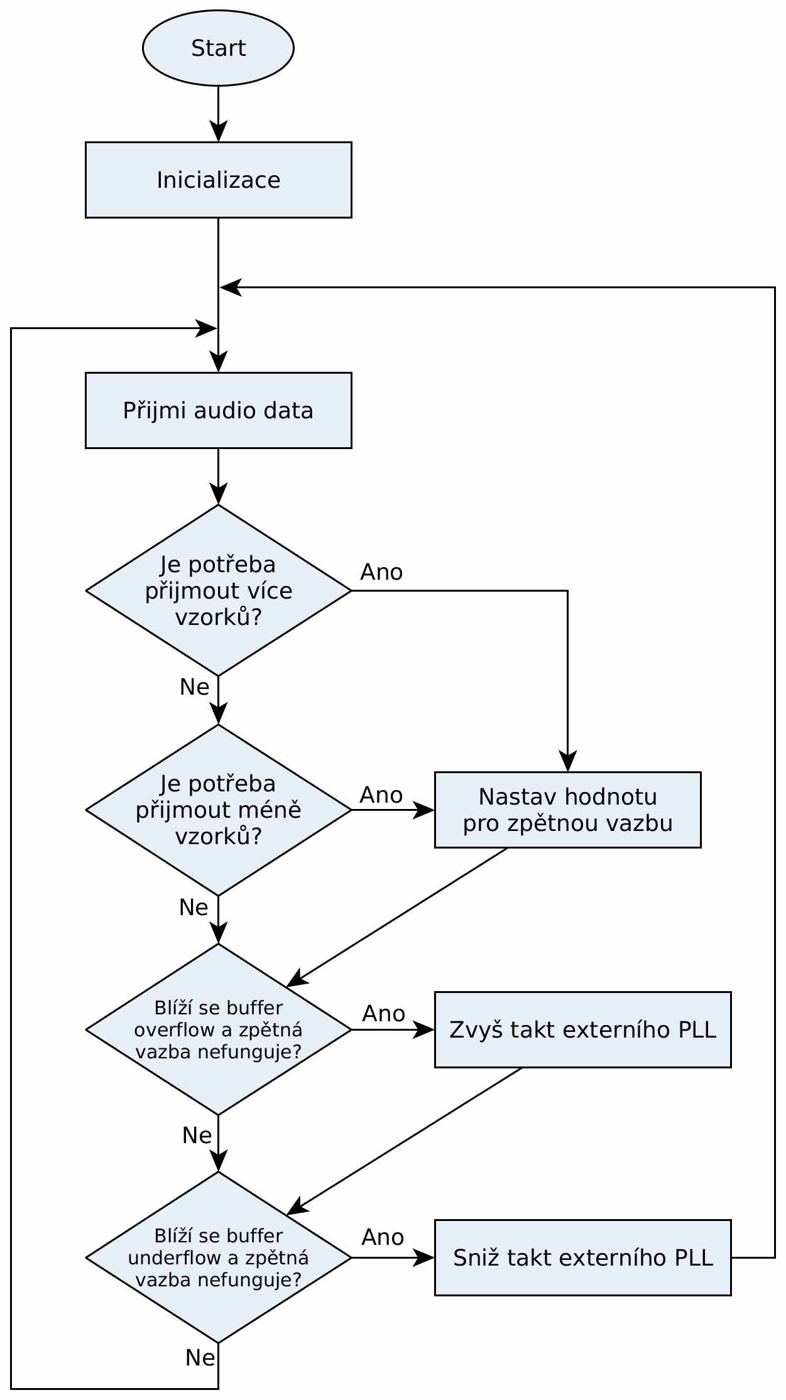
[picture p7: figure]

Obr. 5: Použitý algoritmus pro synchronizaci audio streamu

Do návrhu byl navíc přidán kodek pro kontrolní odposlech I²S sběrnice. Zjednodušené blokové schéma je na Obr. 6. Data z počítače proudípřes USB rozhraní. Jednotlivé vzorky jsou ukládány do RAM. Díky PDCA je možné nakonfigurovat SSC tak, že data z bufferu budou čtena do SSC bez nutnosti použití CPU. To sice musí průběžně nastavovat PDCA periferii, ale celková režie tohoto procesu je mnohem menší, než kdyby mělo CPU kopírovat data do SSC vzorek po vzorku. Data z SSC pak proudí do konektoru a kodeku pro kontrolní poslech. Mezitím CPU jednou za 1 ms zkontroluje stav bufferu a podle algoritmu na Obr. 5 provede potřebné operace. Kvůli jistým omezením externí PLL nemůže generovat hodiny o nižším taktu než 6 MHz, takže hodiny z externího PLL jsou přivedeny do interních děliček GCLK[0] a GCLK[1] (součást PM), kde můžou být podle potřeby poděleny celým číslem. To umožňuje generovat MCLK a BCLK přímo. V takovéto konfiguraci modul SSC pro svůj běh nepotřebuje přímo MCLK, ale stačí mu jen BCLK jako zdroj referenčních hodin. Tím se dá dosáhnout vysoké flexibility při nastavování parametrů.

Obr. 6: Blokové schéma s externím PLL

# Popis použitého mikrokontroléru

## Výběr mikrokontroléru

Jak už bylo naznačeno v úvodu, původní návrh vycházel z řešení přímo od společnosti Atmel. Ten používal MCU AT32UC3A0512. Kvůli hardwarovým omezením bylo nutné použít jiné MCU. Jelikož projekt SDR-Widget využívá MCU, které je už po hardwarové stránce dostačující, bylo pro další verzi použito MCU AT32UC3A3256.

## Základní parametry

UC3A3256 obsahuje 256 kB flash a 64 kB SRAM. Tato velikost je pro požadavky projektu dostatečná. Celé MCU je 32bitové, což je ideální pro přenos audio dat (šířka slova audio vzorku bývá od 16 B do 32 B, ale lze se setkat s 8bitovým rozlišením). Účinnost vykonávání instrukcí je 1,51 DMIPS / MHz [1]. Maximální takt je 84 MHz. Dále obsahuje množství dalších funkčních bloků, které umožní využít hardware na čipu s minimálními nároky na CPU. Dále obsahuje ADC, který je využit pro nastavení hlasitosti kodeku a sledování napětí na straně konektoru s I²S signály. Užitečné jsou i I²C a SPI moduly, které usnadňují implementaci ovladačů pro další komponenty, které jsou externě připojeny k MCU.

## Další funkční bloky na čipu

Softwarová emulace komponent je jednak pomalá a jednak značně zatěžuje CPU. Proto výrobci často implementují na čipu i další hardwarové komponenty, které se pak jen řídí zapsáním správné hodnoty do daného registru. Příkladem může být PWM. Pokud ji chceme implementovat softwarově, bude nutné v určitých časových intervalech přecházet do přerušení, kde se bude nastavovat logická úroveň na výstupu. Pokud ale použijeme již implementovaný PWM modul, pak stačí jednou nahrát požadovanou hodnotu do registru a dále již není nutné generování PWM řídit programem. Nejen že uspoříme výpočetní výkon, ale i program může být jednodušší a menší. Navíc většina komponent umožňuje skočit na vektor přerušení při určité události (například pokud jsou všechna data přenesena, nebo pokud nastane chyba během přenosu atd.). Na druhou stranu kód již není 100% přenositelný, protože je více vázán na hardware, který daný čip nabízí. Tento problém se dá částečně řešit abstrakcí hardware v kódu a využíváním preprocesoru v jazyce C. To ale přináší další negativní jev: kód programu je mnohem větší a především přestává být přehledný a dobře čitelný. Proto je důležité zvolit dobrý kompromis mezi přenositelností kódu a přehledností. Zároveň je vhodné oddělit jednotlivé vrstvy tak, aby nebyly vázány na hardware.

UC3 nabízí spoustu komponent, ale ne všechny bude aplikace vyžadovat. Proto v následujících odstavcích budou popsány pouze periferie, které budou nebo by mohly být v budoucnu použity. USB periferie již zde není uváděna, protože je podrobně probrána v předchozí kapitole.

Poznámka: U většiny blokových schémat je blok, který je nazván PM. Jedná se o Power Manager, který je zodpovědný za hodiny směřující do daného modulu. Zároveň je zodpovědný za správné resetování MCU, uspání MCU a nastavení zdrojů hodin.

### Synchronous Serial (SSC)

Jednotka, která zpracovává tok digitálního audia ve formátu I²S. Zařízení je propojené s PDCA, takže výpočetní náročnost na zpracování dat klesne (viz. kapitola 3.3.2). SSC může pracovat jako master, ale i jako slave, což z něj dělá z pohledu I²S protokolu univerzální zařízení.

Modul má nezávislé RX a TX jednotky. Díky tomu je možné, aby každá pracovala na úplně odlišném taktu a s úplně jiným nastavením. Na druhou stranu by se tím celkové zapojení velice zkomplikovalo, takže v aktuální verzi pracují obě jednotky synchronně. Blokové schéma SSC jednotky je na Obr. 7. Šedě jsou popsány piny korespondující s I²S protokolem.

V této konfiguraci může být zdroj hodin pro každou jednotku pin TX/RX_CLOCK (BCLK) nebo interní hodiny, které mohou být děleny 12bitovou předděličkou. To samé platí pro TX/RX_FRAME_SYNC (FRAME_SYNC). Buď může být použit jako zdroj signálu, nebo může na tento pin signál generovat. Piny TX/RX_CLOCK a TX/RX_FRAME_SYNC jsou záměrně propojeny. V momentě, kdy je RX jednotka nastavena na čistě jako vstupní, změny provedené na TX jednotce se úplně stejně projeví i na RX jednotce. To výrazně zjednodušuje rekonfiguraci na straně driveru. Modul umí mimo jiné „loop mode“, což znamená, že přijímaná data jsou okamžitě vysílána zpět. To je užitečné například při ladění aplikace. Výsledné zapojení je na Obr. 8.

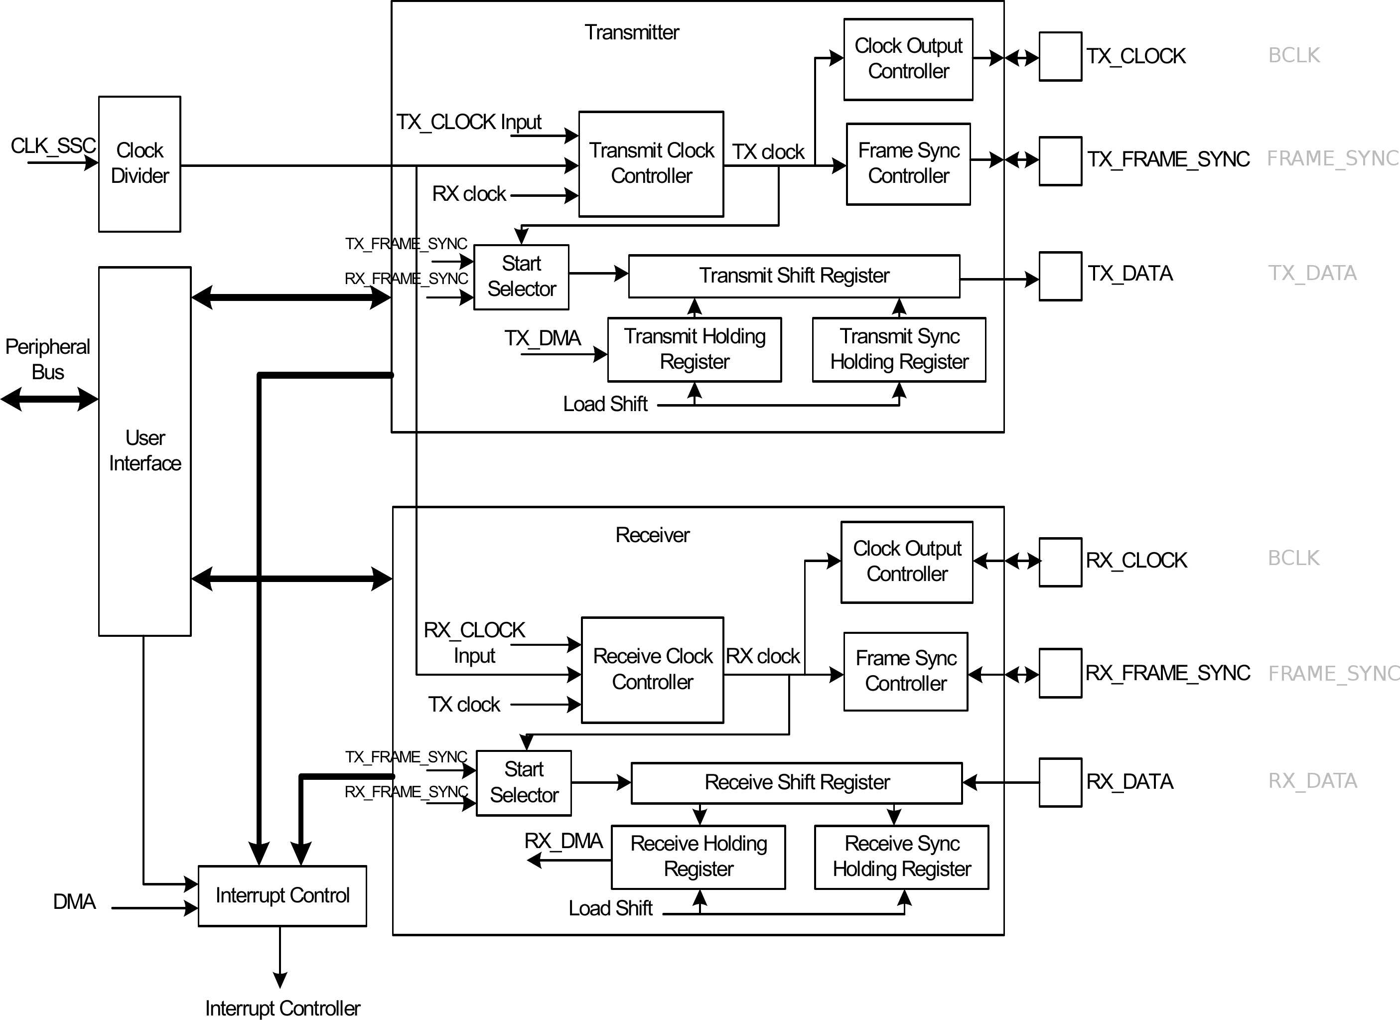
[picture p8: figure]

Obr. 7: Blokové schéma SSC jednotky (převzato z [1])

Pokud bude přenos audio dat bez problémů (podtečení, přetečení bufferů, výpadek synchronizace atd.), pak kvalita analogového signálu závisí pouze na použitém kodeku, který může být až na úplném konci řetězce (i fyzicky). Periferie má opět konfigurační registry, díky kterým je možné jemně nastavit potřebné parametry.

### Peripheral DMA Controller (PDCA)

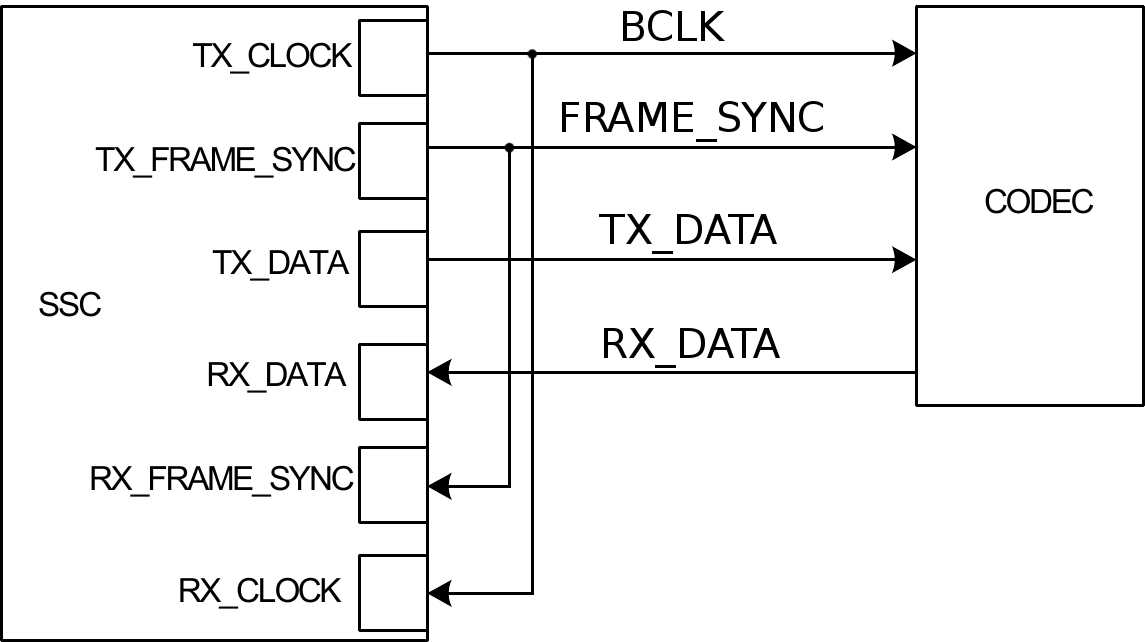
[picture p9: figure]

Obr. 8: SSC v zapojení pro kodek (převzato z [1])

Pro komunikaci s hardwarem je zde PDCA (Peripheral DMA Controller). PDCA umožňuje, aby data z hardwaru byla nahrávána na předem definovaná místa v SRAM. Tím jednak můžeme odlehčit CPU a jednak se tím vyhneme přeskupování dat z jednoho bufferu do druhého. V podstatě je to jen pole ukazatelů, které ukazují na proměnné, do kterých budou data přijatá hardwarem zapsána, případně čtena. Aby se minimalizovalo zpoždění mezi vysíláním/přijímáním dat z periferií, jsou zde tzv. reload ukazatele. Program tedy definuje dva ukazatele. Poté co např. hardware odešle data, načte následující data z reload ukazatele. Mezitím může být spuštěna nějaká rutina v přerušení, která nastaví nové ukazatele. Samozřejmě, že takto je možné přistupovat hned k několika hardwarovým modulům. Pro každý modul je pak možné nastavit individuálně konfigurační registry.

### Periferní sběrnice

Protože ověřit I²S je pomocí klasických měřicích přístrojů vcelku složité, je efektivnější přidat na DPS kodek, který je paralelně připojen na I²S sběrnici. Po správném nastavení kodeku dostaneme na výstupu analogovou formu signálu, která se dá jednoduše změřit, případně si lze signál přímo poslechnout. Lidský sluch je velice citlivý na výpadky a degradaci signálu (vlivem přetečení/podtečení bufferů). Poslechem se tak dá provádět velmi efektivní analýza. Pokud do cesty přidáme přepínač, bude možné poslouchat buď DOUT, nebo DIN a ne pouze jeden směr. Právě pro nastavení kodeku je využívána I²C (nazývaná též TWI) sběrnice.

Nejen kodek, ale i PLL se nastavuje přes I²C sběrnici. Díky vlastnostem I²C lze na jednu sběrnici připojit více zařízení, což usnadňuje celkový návrh. Právě externí PLL je potřeba pro generování dvojích hodin pro MCU a jemné donastavení taktu pro SSC modul. Toto zařízení využívá I²C periferii v master režimu přímo pro ovládání kodeku a externí PLL.

Další, velice rozšířeným rozhraním, je SPI. Často toto rozhraní využívají ADC, DAC, ale i LCD. A právě podpora LCD je v tomto případě klíčová. Celé zařízení totiž obsahuje jednoduchý display, který v konečné verzi informuje uživatele o stavu zařízení. Zároveň během vývoje je možné posílat si na display ladící informace. Modul SPI pracuje také v master módu.

### General-Purpose Input/Output Controller (GPIO)

Tato komponenta má na starost veškerou správu vstupně/výstupních pinů. Na rozdíl od 8bitových MCU, kde po povolení dané komponenty hardware sám přepnul funkci pinu, UC3 jsou více univerzálnější. Například nastavení určitého přerušení může být na 1 z N vstupně/výstupním pinu. Dále je možné, aby dvě různé periferie přistupovaly ke stejným pinům (piny se samozřejmě musí multiplexovat), nastavit na vstupu tzv. glitch filter, který odfiltruje pulzy, které mají délku trvání menší jak jeden hodinový takt. Ale po aplikování filtru mají vstupy zpoždění dva takty a navíc se uplatní pouze pro piny, které jsou využity pro přerušení. Periferie umožňuje pokročilé funkce jako je nastavení pull-up rezistoru nebo výstupu s otevřeným kolektorem..

Přístup k vstupně/výstupním pinům může být prováděn čtyřmi různými způsoby. První je přímý přístup k registrům (paměti). Tento způsob je prakticky stejný, jaký se používá u 8bitových AVR. Další přístup je pomocí „set“. Prakticky to znamená, že je jen nastavována maska, která definuje, které bity budou nastaveny. Jako další je zde „clear“ přístup. Opět se v podstatě jedná o masku, která definuje, které bity budou nastaveny na log. 0. Poslední je „toogle“ přístup. Opět jde o masku, která invertuje jen nastavené bity. Díky těmto metodám je možné efektivněji přistupovat k pinům, protože v praxi je často prováděno maskování softwarově, což stojí čas procesoru, a tím se i snižuje výpočetní výkon.

### Interrupt Controller (INTC)

Periferie, která má na starost přerušení. Zatímco např. u populárních 8bitových AVR mikrokontroléů je vektor přerušení dán hardwarově, UC3 umožňuje si tento vektor nadefinovat. Konkrétně UC3A3256 umožňuje přerušení rozdělit do 64 skupin po 32 přerušeních. Prakticky to znamená, že priority jednotlivých přerušení lze definovat v podstatě libovolně. Tato flexibilita je ale vykoupena větší náročností na nastavení vektoru přerušení. Blokové schéma je na Obr. 9.

Jednotlivé vektory přerušení jsou označeny IREQn, kde „n“ je číslo vektoru. Jednotlivé vektory přerušení jsou vzorkovány do IRR (Interrupt Request register) příslušných skupin. Poté se provede maskování a výsledný signál přerušení jde do CPU jednotky. Té jsou předány nezbytné informace pro provedení přerušení.

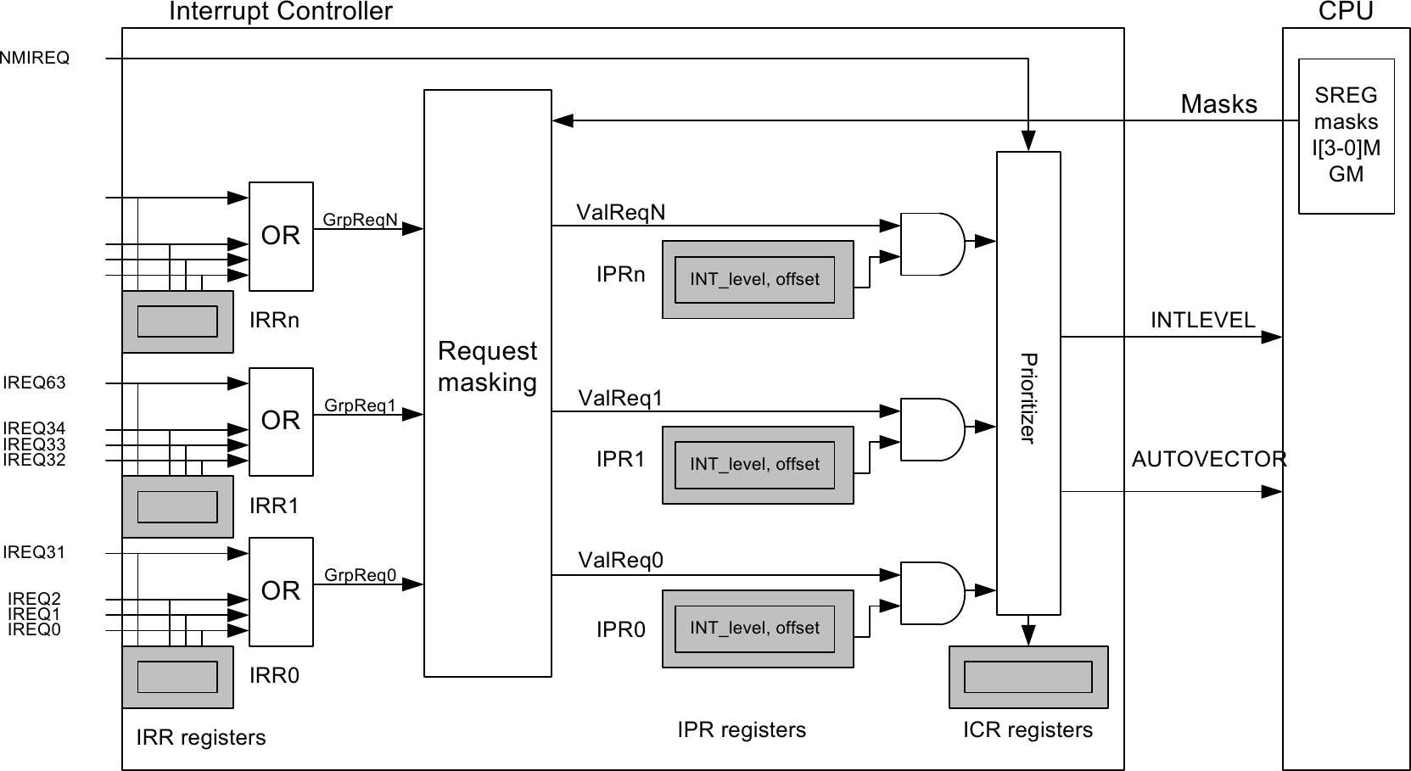
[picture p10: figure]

Obr. 9: Blokové schéma periferie pro přerušení (převzato z [1])

### Power Manager (PM)

Power manager má za úkol nastavovat tzv. sleep režimy, takt jednotlivých sběrnic, obsluhovat wake-up eventy ze zdrojů přerušení a resetovat MCU. Obsahuje mj. i PLL a integrovaný RC oscilátor. Další vlastností je generování tzv. hard a soft reset. Blokový diagram je na Obr. 10.

PM má možnost vyvést hodiny „ven“ pomocí GPIO. To je užitečné, když je zapotřebí mít třístavový výstup. Díky tomu je možné jednoduše nastavovat směr hodin (master/slave).

U 8bitových AVR se zdroj hodin nastavoval pomocí pojistek (fuses), což mohlo při špatné konfiguraci způsobit, že AVR již nebylo možné přeprogramovat (protože nastavený zdroj hodin nebyl k dispozici). Tento problém je elegantně vyřešen u UC3. Ihned po restartu UC3 je použit integrovaný oscilátor. Je pak na aplikačním firmwaru, aby správně přenastavil registry, které definují zdroj hodin. Takže i když bude špatně napsaný firmware, bude stále možné UC3 přeprogramovat, protože při restartu (součást programovacího procesu) bude nastaven jako zdroj hodin integrovaný pomalý RC oscilátor.

Na piny „Oscillator 0“ a „Oscillator 1“ může být připojený externí zdroj hodin nebo krystal. Tento hodinový takt může být pak zvýšen, nebo snížen pomocí integrovaných PLL. V případě, že je zapotřebí tyto piny použít jako vstupně/výstupní, tak je to možné. Samozřejmě tím přijdeme o jeden možný zdroj taktu. Ihned po restartu jsou tyto piny nastaveny jako vstupně/výstupní a až aplikační firmware musí nastavit piny jako zdroj hodin. Aktuální program využívá oba piny pro hodiny.

Obr. 10: Blokový diagram PM (převzato z [1])

Jako další periferie je zde zdroj taktu 32 kHz. Zdroje o této frekvenci se často používají pro aplikace RTC (Real Time Clock). Ihned po zapnutí je periferie vypnutá a její použití je volitelné nastavením registrů. Tento zdroj hodin po zapnutí běží i během resetu (výjimkou je reset, který probíhá při připojení napájení), což je výhodné, pokud je takt vyveden externě z MCU do nějakého dalšího obvodu (hodiny běží stále).

UC3A3256 nabízí hned dvě nezávislé PLL. Díky tomu je možné jako zdroj hodin použít například 12 MHz krystal, a přesto je možné, aby CPU pracovalo například na 66 MHz (12 MHz x11/2). Dále umožňuje, aby CPU spolu s HSB běželo na jiném taktu než PBA a PBB. CPU pak může fungovat na relativně vysokém taktu a přitom vstupně/výstupní piny mohou běžet na mnohem menším taktu. To umožňuje efektivně řídit spotřebu a zároveň je možné v případě potřeby změnit hodiny bez nutnosti pozastavení jakékoliv komponenty.

PM má také na starost tzv. „sleep módy“. Podle toho, jak potřebujeme využívat jednotlivé periferie, je možné nastavit jeden ze sleep módů. Nejméně výrazný sleep mód je „Idle“. Takt do CPU je vypnut, ale veškeré ostatní periferie běží. Naopak nejvíce úsporný sleep mód je „static“, ve kterém jsou veškeré hodiny zastaveny. Jediné možné „probuzení“ je externím přerušením nebo resetem (což je ve své podstatě také externí přerušení).

Jak bylo naznačeno výše, je několik „úrovní“ resetu. Nejvyšší je „Power-on reset“. Ten provede reset všech periferií a pamětí. Další je „External reset“. To je reset, který je proveden pomocí externího pinu. Při tomto resetu se již neresetuje 32 kHz oscilátor, vybrané registry (RTC, kalibrační pro oscilátory). Dále je zde například reset od Watchdogu, BOD atd. Podrobný popis lze vyhledat v datasheetu. Důležité je si uvědomit, že zde existují různé úrovně resetu, a tedy „není reset jako reset“.

### Analog-to-Digital Converter (ADC)

Pro jednodušší ladění I²S sběrnice je na DPS použit kodek. Je vhodné nějakým způsobem umožnit řízení výstupní hlasitosti na kodeku (pro případ, že signál nepůjde na osciloskop, ale do sluchátek). Na to je vhodný obyčejný potenciometr. Jeho analogová hodnota se převádí na číslo a to pak určí hlasitost na kodeku.

Během testování se ukázalo, že je vhodné detekovat, zda je na straně konektoru napájecí napětí (pro kontrolu validity signálů). Detekce je prováděna pomocí optočlenu s fototranzistorem, takže výstup není čistě digitální. Proto je vhodné tento signál měřit pomocí ADC. Navíc lze (s určitou přesností) odhadovat skutečné napětí na straně konektoru.

Na takový nenáročný úkol zcela postačí integrovaný převodník, který je standardem v každém MCU.

ADC na UC3A3256 podporuje 8bitové a 10bitové rozlišení, PDCA, sleep mód, hardwarový a softwarový trigger. Pro správnou funkci je potřeba nejprve piny namapovat pomocí GPIO a pokud chce programátor využít i přerušení, musí nejprve nastavit komponentu INTC. Samotný ADC má integrovanou děličku, takže pokud je potřeba, tak lze snížit spotřebu tak, že bude snížen taktovací kmitočet. Blokový diagram je na Obr. 11.

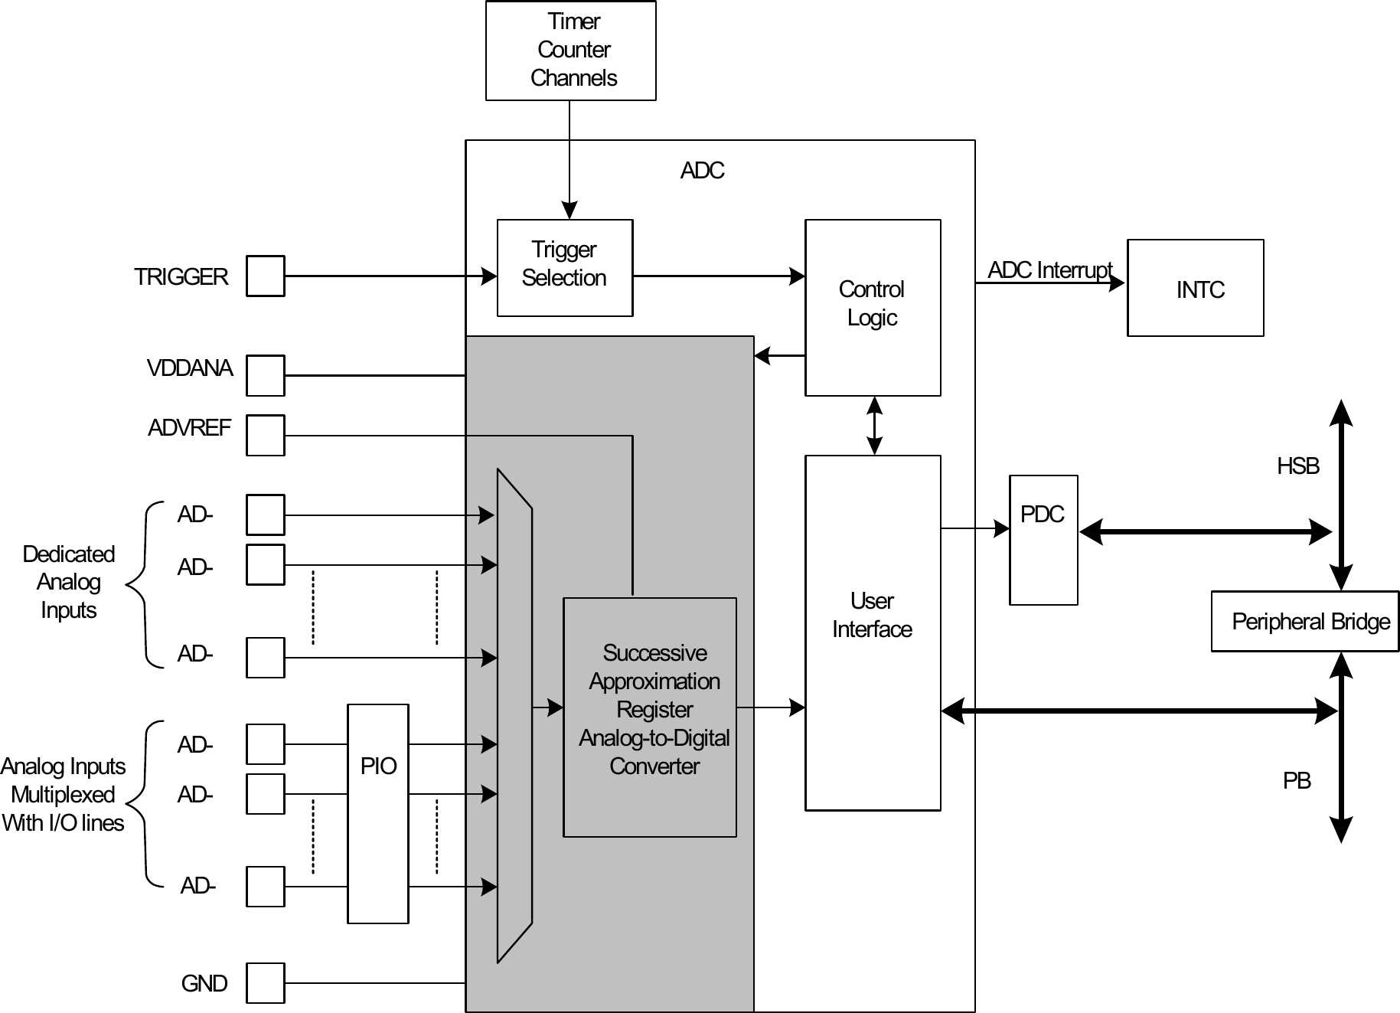
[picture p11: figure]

Obr. 11: Blokový diagram ADC (převzato z [1])

# HW řešení

Základní schéma zapojení vychází z projektu SDR-Widget, který je volně dostupný [13] a implementuje USB audio zařízení na shodném mikrokontroléru, avšak s odlišným cílem. Vyžití již existujícího HW základu bylo motivováno následujícími faktory:

- na trhu existuje jen velmi málo vhodných typů MCU pro daný účel, dostupných pro malosériové ruční prototypování, takže překryv s projektem SDR widget byl prakticky nevyhnutelný,
- existující funkční koncept umožnil rychlejší postup do další fáze implementace.

Z původního zapojení SDR Widget projektu nakonec zbyl v podstatě jen UC3A3256 a čtyři informační LED. Všechny ostatní komponenty byly zaměněny, nebo úplně vynechány.

Celkový odběr zařízení v provozu se pohybuje okolo 230 mA, takže zařízení lze napájet přímo z USB 2.0 sběrnice (limit USB 2.0 je 500 mA). Podle standardu USB je host povinen zařízení dodat proud alespoň 100 mA. Pokud má zařízení větší nároky na napájení, musí hostu tuto skutečnost nahlásit. To umožňuje jeden z deskriptorů, které popisují zařízení jako celek. Vzhledem k relativně malým proudovým odběrům samotných integrovaných obvodů byly při návrhu použity obyčejné lineární stabilizátory. Jejich nevýhodou je sice nižší účinnost než u spínaných zdrojů, ale na druhou stranu jsou mnohem jednodušší, méně náročné na komponenty, a na jejich výstupu je mnohem menší vysokofrekvenční šum, který má negativní dopady na analogové obvody pro kontrolní poslech. Zejména na SNR u kodeku, který je na desce spolu s UC3A3256.

## Blokové schéma hardwaru

Propojení jednotlivých funkčních bloků s MCU je popsáno na Obr. 12.

Externí PLL má dva výstupy. Jeden je fixní a jeho takt je dán přímo zdrojem hodin pro PLL (ve výchozím nastavení). Tento fixní výstup je pak použit jako zdroj hodin pro CPU nebo USB. Druhý výstup je již variabilní (PLL CLK) a takt je dán nastavením registrů v PLL.


Obr. 12: Blokové schéma hardwarového návrhu

SSC potřebuje pro správnou funkci referenční BCLK. Ten může být generován z modulu PM, nebo jako zdroj může posloužit I²S sběrnice. Přepínání zdroje hodin lze provádět pouze softwarově. V případě, že BCLK má být generován, pak v modulu PM musí být nastaven jeho zdroj (PLL CLK), dělící poměr a přiřazen patřičný výstupní pin. Signál je tedy vyveden „ven“ z pouzdra. To umožňuje jednoduše a rychle změřit jeho frekvenci, takže ladění aplikace se stává jednodušším. Pokud má být zdrojem BLCK I²S sběrnice, pak stačí pouze nastavit patřičný pin do Hi-Z. Tím dojde k odpojení od PM bloku. Signál MCLK není pro SSC nijak potřebný. Přesto může být nastaven stejně jako BCLK (tzn. může být vstupní i výstupní). Kodek je pak přímo napojen na I²S sběrnici tak, aby ze sběrnice pouze data přijímal. To znamená že umožňuje sběrnici pouze odposlouchávat.

Zařízení má mít možnost pracovat jako I²S master, i jako I²S slave. Je proto nutné, aby digitální izolátory umožňovaly přenos dat oběma směry. Resp. digitální izolátory umožňují nastavit nezávisle směr pro MCLK, BCLK, FRAME_SYNC, MUTE a RESET_I2S, takže zařízení nemusí být čistě master nebo slave. To je opět výhodné při ladění, nebo použití zařízení v nestandardních situacích. Pro řízení směru toku dat jsou použity piny z GPIO modulu. Samotný I²S konektor obsahuje standardní I²S signály plus další pomocné pro jednodušší řízení celé aplikace (MUTE, RESET_I2S, MCLK, napájení).

Pro korektní funkčnost LCD modulu je zapotřebí nejen SPI signálů, ale jsou použity další piny z GPIO modulu. LCD modul má za úkol informovat uživatele o stavu zařízení a o výskytu případných chyb.

Pro ladění je na desce ještě vyveden UART, který je na výpis ladících informací mnohem vhodnější než LCD display. UART umožňuje posílat ladící informace pomocí převodníku do počítače, kde je na vývojáři, aby si potřebné informace zpracoval či zobrazil. Signály RX a TX jsou vyvedeny na desku, ale nejsou vyvedeny z krabičky. Běžný uživatel je totiž nebude potřebovat.

Signály MUTE, RESET_I2S a NSRST je možné ovládat tlačítky. Signál NSRST je spojen přímo s MCU a kodekem, takže při jeho stisku se okamžitě vyvolá reset na obou zařízeních. Tlačítka pro MUTE a RESET_I2S nejsou zapojena na I²S sběrnici, ale na piny MCU. To je pro případ, že by tyto signály byly nastaveny jako výstupní a v případě stisku tlačítka (které by bylo připojeno přímo) by byl výstup na MCU přetěžován. Aktuální zapojení řeší tento problém. Pokud bude pin na MCU nastaven jako výstupní, pak software bude vzorkovat hodnotu na tlačítku a tuto hodnotu nastaví i na daný signál (MUTE/RESET_I2S). V případě, že signálový pin bude nastaven jako vstupní, pak MCU nebude nastavovat úroveň signálu, ale pouze provede dané operace. To znamená že buď ztiší výstup pro kontrolní poslech, nebo resetuje I²S sběrnici (výchozí nastavení).

Pro rychlý přehled byly na desku přidány signalizační LED, které mají uživateli zpřehlednit aktuální nastavení a stav na některých pinech.

Pro debug byly rezervováno osm vstupně výstupních pinů a 9 LED. Indikační SMD LED nemusí být ve finální podobě osazovány. Jedná se pouze o LED, které mají za úkol usnadnit vývoj (signalizace stavů, přetečení bufferu atd). Vyhrazené vstupně výstupní piny je ale možné v konečné fázi využít libovolně. Například zde budou připojena tlačítka pro uživatele, nebo další signalizační prvky. Rozmístění uživatelských periferií je na Obr. 13.

## MCU AT32UC3A3256

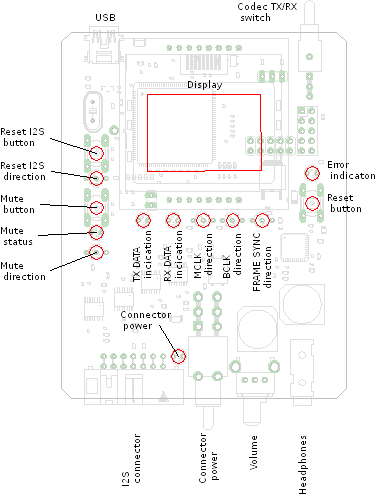
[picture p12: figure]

Obr. 13: Rozmístění uživatelských periferií na desce

Protože vstupně/výstupní piny jsou stavěny na rozmezí 3 až 3,6 V [1], je zapotřebí, aby napětí na VDDIO, VDDIN a VDDANA bylo v tomto rozsahu. Proto bylo zvoleno jako napájecí napětí pro MCU a další komponenty 3,3 V. Většina moderních obvodů je schopna pracovat spolehlivě při takto nízkém napětí. Navíc se sníží i proudový odběr ostatních integrovaných obvodů. Pro napájení jádra MCU a interní PLL je sice zapotřebí 1,8 V, ale MCU již má integrovaný stabilizátor, takže není potřeba dalších komponent (vyjma blokovacích kondenzátorů).

Pro naprogramování MCU je zde JTAG rozhraní. Díky JTAG je teoreticky možné ladit program, sledovat obsah registrů, ale problém nastává při komunikaci s periferiemi, které trvale vyžadují odpověď od MCU. Typicky jde o USB rozhraní v Isochronním módu. Pokud se program zastaví na breakpointu, pak USB má za úkol periodicky odesílat a přijímat data, ale MCU nebude odpovídat, což může vyústit v neočekávané chování programu. To samé platí při použití RTOS, kde je ladění celé aplikace velmi problematické.

U každého tlačítka je již připravený RC článek, který sníží počet zákmitů na tlačítku a zjednoduší se i obslužný software.

Jak bylo uvedeno výše, při debugování skrze JTAG není zcela vyloučeno, že nenastane nějaký nečekaný problém. Proto speciálně pro debug bylo vyhrazeno osm vstupně/výstupních pinů. Na tyto piny mohou být připojené například další LED indikující různé stavy, nebo tlačítka, pomocí kterých bude možné řídit běh programu v reálném čase. Tyto signály jsou na schématu označeny jako GPIO_x, kde „x“ značí číslo signálu. Pro debug zprávy lze využít i UART nebo LCD, ale zde je limit v počtu zobrazených znaků.

U většiny výstupních pinů jsou sériově přidány ochranné odpory. Tyto odpory limitují maximální proud jednotlivých výstupů a tím chrání výstupní obvody při zkratu nebo jiném problému. Zároveň je na nich možné měřit úbytek napětí. Tam kde je vysoký úbytek lze očekávat větší proud a tím pádem i nějaký problém. To opět usnadňuje ladění a zvyšuje robustnost celé aplikace.

## Externí PLL

Kvůli potřebě generovat necelistvé násobky vzorkovacích frekvencí byl vybrán programovatelný obvod CS2200-CP od Cirrus Logic. Tento obvod umožňuje nastavit výstupní frekvenci v rozsahu 6 až 75 MHz. Výstupní frekvence se nastavuje především poměrem ve formátu 12.20b. To znamená, že horních 12 bitů je před desetinnou čárkou a dalších 20 bitů je za desetinnou čárkou. Díky tomuto poměru je možné nastavovat výstup s krokem 10 ppm (bráno ze vstupního zdroje hodin). Vstupní rozsah frekvencí pro krystal je od 8 do 50 MHz.

Protože obvod má dva výstupy (AUX_OUT a CLK_OUT), je vhodné je efektivně využít. Jako zdroj signálu je použit 12 MHz krystal (především kvůli USB periferii – viz. předchozí kapitola). To znamená, že na výstupu AUX_OUT je po přivedení napájení takt o 12 MHz. Tento takt je přiveden přímo do MCU, kde je vynásoben pro USB modul, CPU a další periferie. Druhý výstup (CLK_OUT) je po přivedení napájení ve stavu vysoké impedance a je na MCU, aby tento obvod přes I²C sběrnici správně nakonfigurovalo. Tento výstup je použit pro generování MCLK a BCLK pomocí děliček integrovaných v MCU.

## Galvanické oddělení pro I²S konektor

Galvanické oddělení je možné několika způsoby. Nejčastěji se používají transformátory, optočleny a vazba RF signálem. Transformátory nejsou pro tuto aplikaci vhodné, protože nemohou přenášet stejnosměrnou složku. To je diskvalifikuje pro signál, který nastavuje mute. Velice často se používají optočleny. Jejich nevýhodou je vyšší napájecí napětí (okolo 5 V) a velice špatná dostupnost pro vysoké přenosové rychlosti. Většinou lze sehnat optočleny pracující do 1 MHz, ale vzhledem k tomu, že MCLK se pohybuje kolem 12 MHz je 1 MHz naprosto nevyhovující. Na druhou stranu umožňují přenášet i stejnosměrnou složku. Spíše neobvyklou metodou oddělování jsou tzv. digitální izolátory. V podstatě jde o podobný princip jako u optočlenů, ale rozdíl je ve frekvenci, na které je přenášena informace. U optočlenů je informace přenášena na několika THz. K příjmu je pak použita fotodioda, nebo fototranzistor a signál je dále zpracován (například hradlem). U digitálních izolátorů je namísto světla použito RF pásmo (stovky MHz až jednotky GHz).

Firma Silicon Labs nabízí právě digitální izolátory, které zvládají přenést až 150 Mbit/s při napájecím napětí od 2,7 V do 5,5 V [7]. Jak už název napovídá, obvody jsou určené čistě pro přenos digitální informace (na rozdíl od optočlenů, které umožňují přenášet i analogový signál). Navíc digitální izolátory od Silicon Labs nabízí třístavový výstup, což je vhodné pro signály, u nichž se může měnit směr (např. MCLK). Dostupnost těchto komponent na maloobchodním trhu je o něco horší než u optočlenů, ale jejich parametry jsou pro danou aplikaci ideální.

Kvůli tomu, že jsou použity aktivní součástky pro galvanické oddělení, je zapotřebí napájet zvlášť i stranu s konektorem. Napájení může být přímo na konektoru. Není to však nezbytnost. Pokud totiž není vyžadováno galvanické oddělení, pak je možné stranu s konektorem napájet přímo ze stabilizátoru, který napájí MCU. To je vhodné například při vývoji, kdy veškerá zařízení jsou připojena k jednomu počítači, a tedy není nutné galvanické oddělení.

## Kodek pro kontrolní poslech I²S signálu

Jako kodek byl zvolen obvod TLV320AIC33. Tento obvod je vyráběn v pouzdru 48-QFN, takže jeho rozměry jsou velmi kompaktní (7x7 mm) [2]. Jeho hlavní výhodou je možnost velmi jemného nastavení jak analogové, tak digitální části.

Obvod má integrované analogové vstupy: 2x stereo a 1x mono. Každý může pracovat jako diferenční i jako jednoduchý. Analogové výstupy jsou zde 3x stereo a 1x mono. Opět je možné nastavit, zda bude výstup diferenční, nebo ne. Jeden stereo výstup je navržen pro přímé připojení sluchátek, čili odpadá stavba koncového stupně. Vstupy nebudou použity, takže kvůli úspoře místa na DPS nejsou na vstupy připojeny žádné odpory, díky kterým by šly vstupy v budoucnu použít. Výstup bude použit jeden: sluchátkový. Ostatní výstupy nebudou použity a jejich piny nebudou vyvedeny ven. Opět kvůli úspoře místa na DPS.

Obvod potřebuje ke své funkci tři zdroje napětí. Jeden zdroj pro analogovou část kodeku (3,3 V), další pro digitální jádro (1,8 V) a poslední pro digitální vstupně/výstupní piny (3,3 V). Právě kvůli snížení šumu na analogové části je napájení pro analogovou a digitální část odděleno už samotnými regulátory. Pozice kodeku a regulátoru pro analogové obvody je záměrně zvolena co nejdále od ostatních obvodů, aby bylo zamezeno indukci nechtěného rušení od dalších obvodů a sběrnic.

Kodek umožňuje mixování vstupních signálů s výstupními. Vzhledem k tomu, že v tomto případě bude kodek využit pouze jako výstup, nebudou tyto možnosti dále probírány.

Výběr a popis některých parametrů je v Tab. 4.

Tab. 4: Popis vybraných parametrů kodeku (převzato z [2])

Parametr | Hodnota | Popis
DAC SNR | 100 dB | Pro ověření signálu na I²S sběrnici naprosto dostačující parametr. Vhodné i pro méně náročné měření. Zde již záleží na designu DPS a kvalitě jednotlivých komponent (regulátory, blokovací kondenzátory atd.)
Napájení analogové části | 2,7 V- 3,6 V | Napájecí napětí bylo zvoleno 3,3 V. Jedná se o standard a je to i doporučeno v datasheetu. Přestože pro napájení analogové části je zde zvlášť stabilizátor, byl na desku ke kodeku přidán LC filtr.
Napájení digitálního jádra | 1,65 V – 1,95 V | Toto je jediný pin na desce, který vyžaduje takovéto napětí. Proto je zde další stabilizátor na 1,8 V. Napětí 1,8 V je doporučeno výrobcem.
Napájení digitálních vstupů/výstupů | 1,42 V – 3,6 V | Vzhledem k tomu, že použité napětí pro MCU je 3,3 V, tak je výhodné použít toto napětí i pro napájení vstupů/výstupů kodeku. Tím pádem nejsou potřeba žádné konvertory mezi MCU a digitálním rozhraním kodeku.
Rozsah vzorkovacích frekvencí | 8 kHz, 11.025 kHz, 12 kHz, 16 kHz, 22.05 kHz, 24 kHz, 32 kHz, 44.1 kHz, 48 kHz, 88.2 kHz, 96 kHz | Protože jednotlivé vzorkovací frekvence si navzájem nejsou celými násobky, je nutné nejen správně nastavit kodek, ale zvolit i správný takt pro MCLK, BCLK a FRAME_SYNC. Z toho plyne přímá návaznosti na externí PLL, SSC a děličku v MCU.
Šířka slova | 16,20,24,32 bitů | Nejnižší rozlišení (16 bitů) odpovídá CD standardu [6], Další podporované možnosti jen přidávají kodeku na univerzálnosti a věrnosti původnímu záznamu.
Podporované standardy pro digitální rozhraní | I²S, MSB justified, LSB justified, DSP, TDM | Mimo požadovaný standard I²S podporuje i standardy využívané především DSP procesory. Vhodné pro budoucí rozšíření, kdy výstup MCU nebude jen I²S.
Nastavení rozhraní | I²C, SPI | Samotný kodek je možné nastavovat skrze I²C nebo SPI. Vzhledem k tomu, že I²C kontroluje odeslaná data už na nejnižší úrovni (příjemce musí odpovědět), je jednodušší ovládat kodek právě pomocí I²C.
Analogový výstup | Line out, headphones | Na čipu je již integrovaný zesilovač pro sluchátka. Díky tomu je možné přímo na piny připojit sluchátka (32 Ω) bez dalších obvodů navíc. Kodek umožňuje softwarové ovládání hlasitosti, takže pokud je potřeba, může být původní signál zeslaben v rozsahu od 0 do -78 dB. Dále je zde line out výstup, který ale není v této situaci zapotřebí a není nikam připojen.

## LCD modul

Jako display byl vybrán grafický modul původně určený pro telefony Nokia 5110. Tento produkt je v současnosti populární volbou v prototypových zapojeních kvůli svým parametrům a dostupnosti. Rozlišení je 84x48 px, což je postačující pro zobrazení základních informací. Display v podstatě používá SPI rozhraní rozšířené o signál, který přepíná mezi datovým slovem, příkazem a resetem. Modul dokáže komunikovat až rychlostí 4 Mbit/s [9], což je na display dostačující. Díky popularitě tohoto modulu existuje několik volně dostupných knihoven s předdefinovanými písmy. Experimentálně bylo vyzkoušeno, že modul funguje i při taktu 12 MHz, takže v případě potřeby je možné modul „přetaktovat“ bez větších potíží, a tím urychlit chod programu. Popis pinů je v Tab 5.

Tab. 5: Přehled pinů na LCD modulu (převzato z [9])

Pin | Popis
1 - RST | Reset. Aktivní v nízké úrovni. Nutný před inicializací.
2 - CE | Chip enable. Povoluje SPI rozhraní. To je užitečné v případě, že SPI sběrnici využívá několik zařízení současně.
3 - DC | Data/command. Přepíná mezi surovými daty pro displej a příkazy pro řadič displeje.
4 - DIN | Data in. Sériová reprezentace dat. Data musí být platná při náběžné hraně signálu CLK.
5 - CLK | Clock. Takt pro řadič. Podle datasheetu může dosahovat až 4 MHz.
6 - VCC | Napájení pro modul. Doporučené napětí je 3,3 V.
7 - LIGHT | Podsvětlení. Aktivní v nízké úrovni, takže vhodné spínat NPN tranzisotrem.
8 - GND | Zem

Inicializace a další komunikace s modulem je podrobně popsaná v datasheetu [9], takže zde nebude dále rozebírána.

# SW řešení

Vzhledem k tomu, že hardware vychází z projektu SDR-Widget, je výhodné použít již napsaný a vyzkoušený software jako základ a ten dále rozšiřovat a modifikovat. Protože kromě MCU jsou prakticky všechny komponenty na DPS jiné a architektura UC3 není příliš rozšířená, bylo potřeba napsat ovladač pro každou komponentu (PLL, kodek, řídící piny). Zároveň bylo nutné odstranit z původního kódu vazby na komponenty, které ve skutečnosti nebyly připojeny.

Řešení využívá FreeRTOS. Jedné se o volně dostupnou implementaci „real time operating system“ - RTOS [15]. V praxi to znamená, že na MCU běží zdánlivě paralelně několik vzájemně nezávislých úloh (tasků). Je zvykem, že každý task je napsán jako funkce, která běží v nekonečné smyčce. Uvnitř této smyčky se provádí samotné zpracování dat. Díky použití RTOS je možné nastavit priority jednotlivých tasků, a tím jednodušeji implementovat úkoly, které má MCU plnit. Například task pro zpracování audio dat bude mít vysokou prioritu a bude volán mnohem častěji než task, který má na starost tlačítka, které je potřeba zkontrolovat jednou za několik desítek ms. Na druhou stranu RTOS přináší i některé nevýhody:

- režie při přepínání jednotlivých tasků,
- nutná definice stacku (v některých případech je složité správně odhadnout využití RAM),
- nutná signalizace při používání společného hardwaru (používají se tzv. mutexy),
- nutnost vyhradit alespoň jeden hardwarový časovač pro RTOS.

I přes výčet nevýhod je pro tento projekt zdánlivě paralelní zpracování zvláště vhodné a umožňuje efektivní a přehlednou implementaci v kódu.

## USB Deskriptory

Deskriptory jsou souborem konstant, které popisují jednotlivé vrstvy USB zařízení (zařízení jako celek, jednotlivá interface, endpointy atd.). Díky deskriptorům je host schopný detekovat, o jaké zařízení se jedná, jakým způsobem komunikuje a jaké jsou jeho možnosti. Umožňují definovat povahu přenášené informace (surová data, zpětná vazba, atd.). Zároveň jsou některé deskriptory prezentované jako textová pole, takže i uživatel může snadno zjistit název zařízení, výrobce a nebo sériové číslo. Ve zdrojových kódech jsou deskriptory definovány v souborech, které mají v názvu „usb_descriptors“. Stručný přehled vybraných deskriptorů pro celé zařízení je v Tab. 6.

Tab. 6: Stručný přehled deskriptorů zařízení

Deskriptor | Hodnota | Popis
bcdUSB | 2.00 | Verze USB, kterou zařízení využívá. V tomto případě nepodporuje starší USB 1.1
idVendor | 0x16D0 | Složené audio zařízení [8]
idProduct | 0x0763 | Product ID. Pouze číslo pro odlišení od SDR-Widget, který používá 0x0761 a 0x0762. Nemá vliv na instalaci ovladače v OS.
iManufacturer | ALCZ | Výrobce
iProduct | Sonochan mkII | Jméno produktu
iSerial | 0.0.0.0.0.0.1 | Sériové číslo
bNumConfigurations | 1 | Počet konfigurací
bNumInterfaces | 4 | Počet interface
bmAttributes | 0xC0 | Napájeno z USB
MaxPower | 130 | Maximální proudový odběr v mA podělený dvěma. Zařízení hlásí, že požaduje zdroj, který dodá alespoň 260 mA.

Každý interface pak obsahuje další deskriptory, které jej popisují. Vlastnosti jednotlivých interface jsou shrnuty v Tab. 7. Vzhledem ke komplexnosti USB protokolu jsou shrnuty vlastnosti jen některých deskriptorů.

Tab. 7: Popis jednotlivých interface

Interface 0 | HID – pro konfiguraci zařízení pomocí počítače. Obsahuje dva EP: vstupní a výstupní pro plně duplexní komunikaci. Pakety mají velikost 8 B a mohou být odesílány v intervalu 5 ms (mód „Interrupt“).
Interface 1 | Popisuje ovládací prvky (mute, volume), počet kanálů na interface 2 a 3.
Interface 2 | Výstupní audio stream ve formátu PCM s rozlišením 24 bitů. Mód přenosu: „Isochronous“. Synchronizace: „Asynchonous“. Maximální velikost paketu: 308 B. Podporované vzorkovací frekvence: 8000, 11025, 16000, 22050, 24000, 32000, 44100 a 48000 Hz.
Interface 3 | Vstupní audio stream ve formátu PCM s rozlišením 24 bitů. Mód přenosu: „Isochronous“. Synchronizace pomocí zpětné vazby. Maximální velikost paketu: 308 B. Podporované vzorkovací frekvence: 8000, 11025, 16000, 22050, 24000, 32000, 44100 a 48000 Hz.

## Princip nastavení vzorkovací frekvence

Při USB inicializaci host získá všechny potřebné parametry, včetně seznamu podporovaných frekvencí. Před samotným přehráváním (resp. odesíláním audio dat) odešle host požadavek, ve kterém je zahrnuta informace o vzorkovací frekvenci. V tomto momentě je na zařízení, aby zvolilo platnou konfiguraci. Host poté začne odesílat audio data. Celá komunikace je zjednodušeně znázorněna na Obr. 14.

Funkce audio_set_cur() má za úkol nastavit externí PLL a děličky GCLK[0] a GCLK[1] tak, aby FRAME_SYNC, BCLK a MCLK odpovídaly požadavkům uživatele. V případě ladění aplikace může rozsvítit danou kombinaci LED, poslat zprávu přes UART nebo LCD.

Obr. 14: Nastavení vzorkovací frekvence

## Tok audio dat z počítače do sériového synchronního rozhraní

Už z principu je velikost hardwarových USB bufferů menší než velikost bufferů pro audio stream. Proto je nutné řešit způsob ukládání dat. Na Obr. 15 je znázorněný výstupní audio stream. Diagram pro vstupní audio stream by byl prakticky stejný, ale směr šipek pro audio data by byl opačný. Plné čáry reprezentují audio stream, přerušované pak řídící signály.

Funkce uac1_device_audio_task() běží jako nezávislý proces a v případě příchozích dat z USB modulu kopíruje audio data do patřičných audio bufferů. Zároveň sleduje zaplnění bufferů a provádí patřičné kroky, aby nedošlo k podtečení, nebo přetečení bufferů (problematika synchronizace je probrána podrobněji v kapitole 5.4). Při příjmu dat se vyvolá přerušení (blok INTC) a rutina nastaví PDCA periferii. Ta nastaví virtuální přepínač (switch). Respektive PDCA nastaví ukazatel na audio data, který pak využívá SSC jednotka. Z programátorského pohledu pracují periferie INTC a PDCA na pozadí.

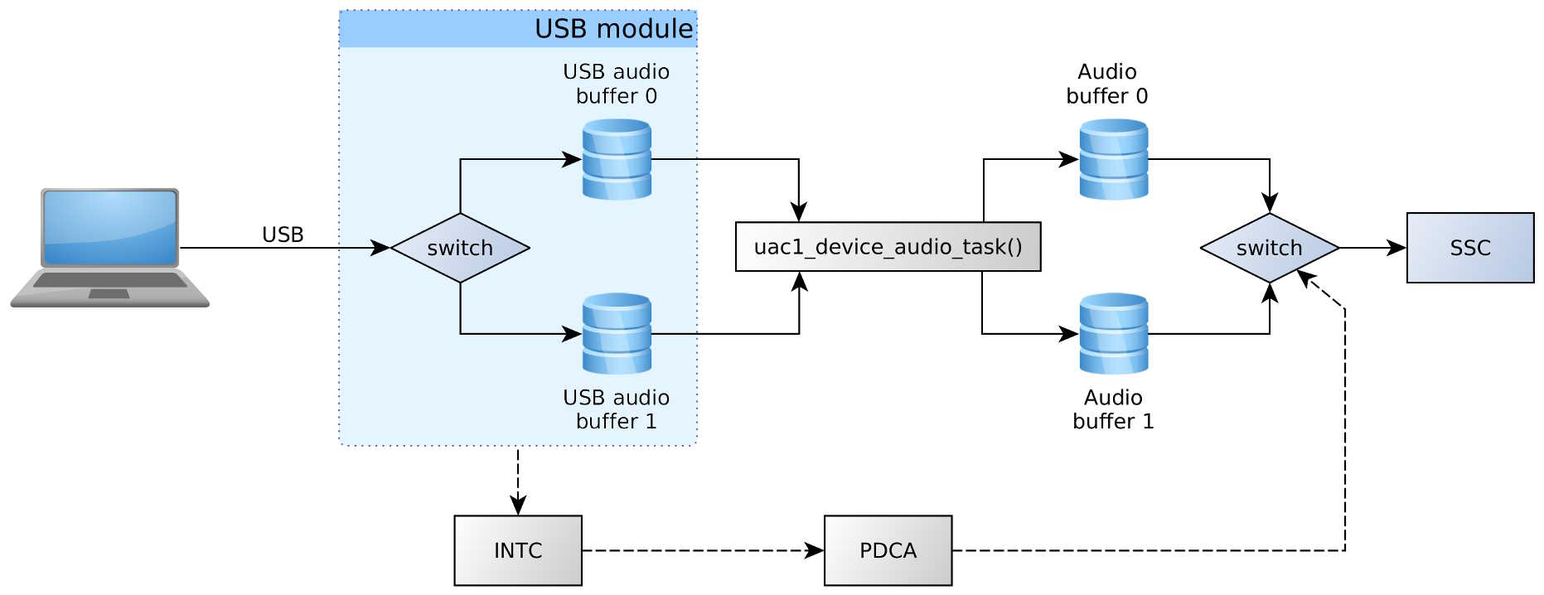
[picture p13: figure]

Obr. 15: Zjednodušený diagram pro výstupní audio stream

## Řešení synchronizace audio dat

Synchronizace audio dat je klíčová vlastnost požadovaného zařízení. Metody synchronizace jsou podrobně popsány v kapitole 2.3. Tato kapitola se zabývá konkrétním softwarovým řešením. Synchronizaci obou audio streamů (jak vstupních, tak výstupních) provádí funkce uac1_devaice_audio_task(). Pro přehlednost jsou zde dva vývojové diagramy: jeden pro vstupní data (Obr. 16) a druhý pro výstupní data (Obr. 17). Princip nastavení vzorkovací frekvence a dalších hodin je popsán v kapitole 5.3.

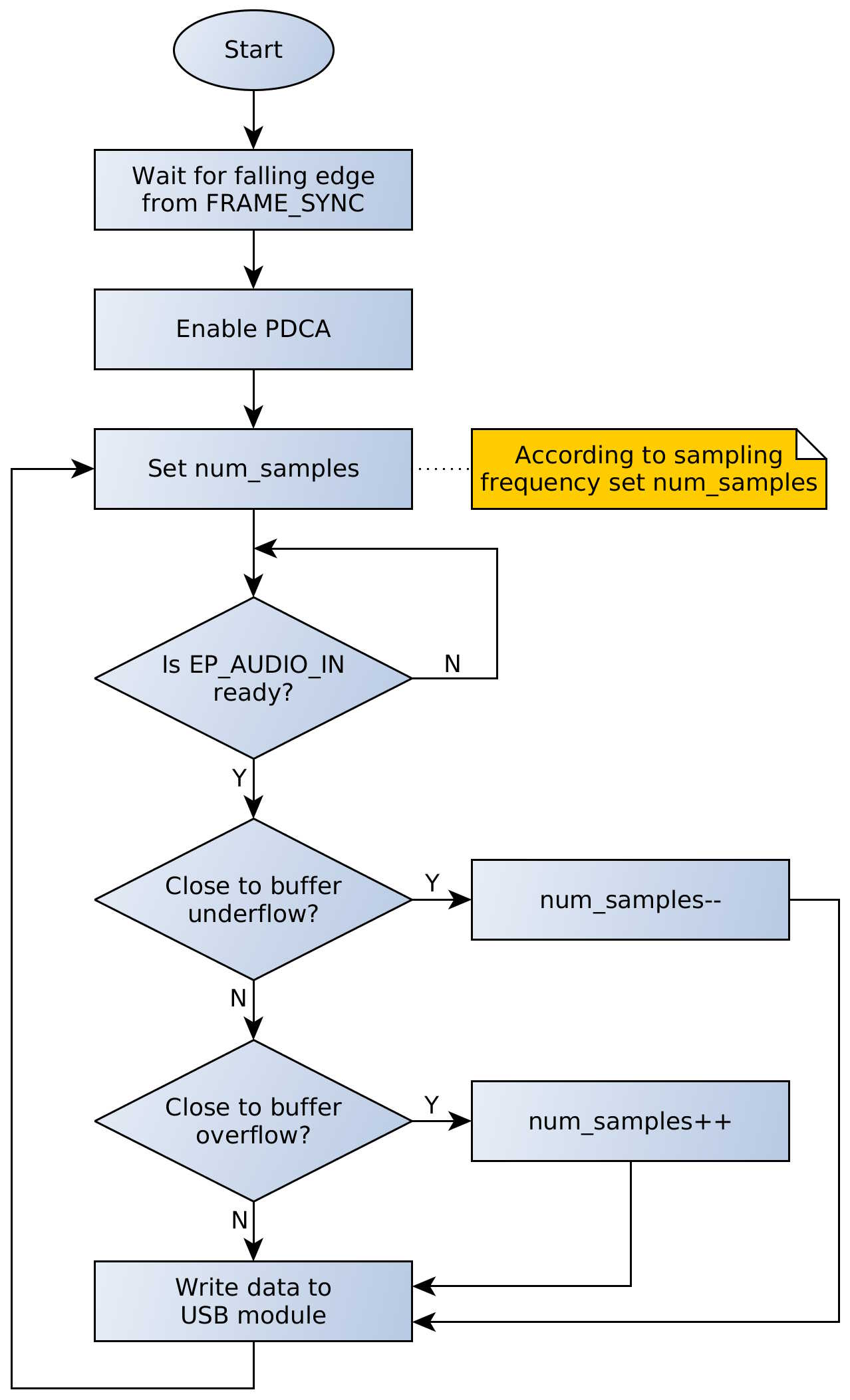
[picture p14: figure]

Obr. 16: Řešení synchronizace pro vstupní audio stream

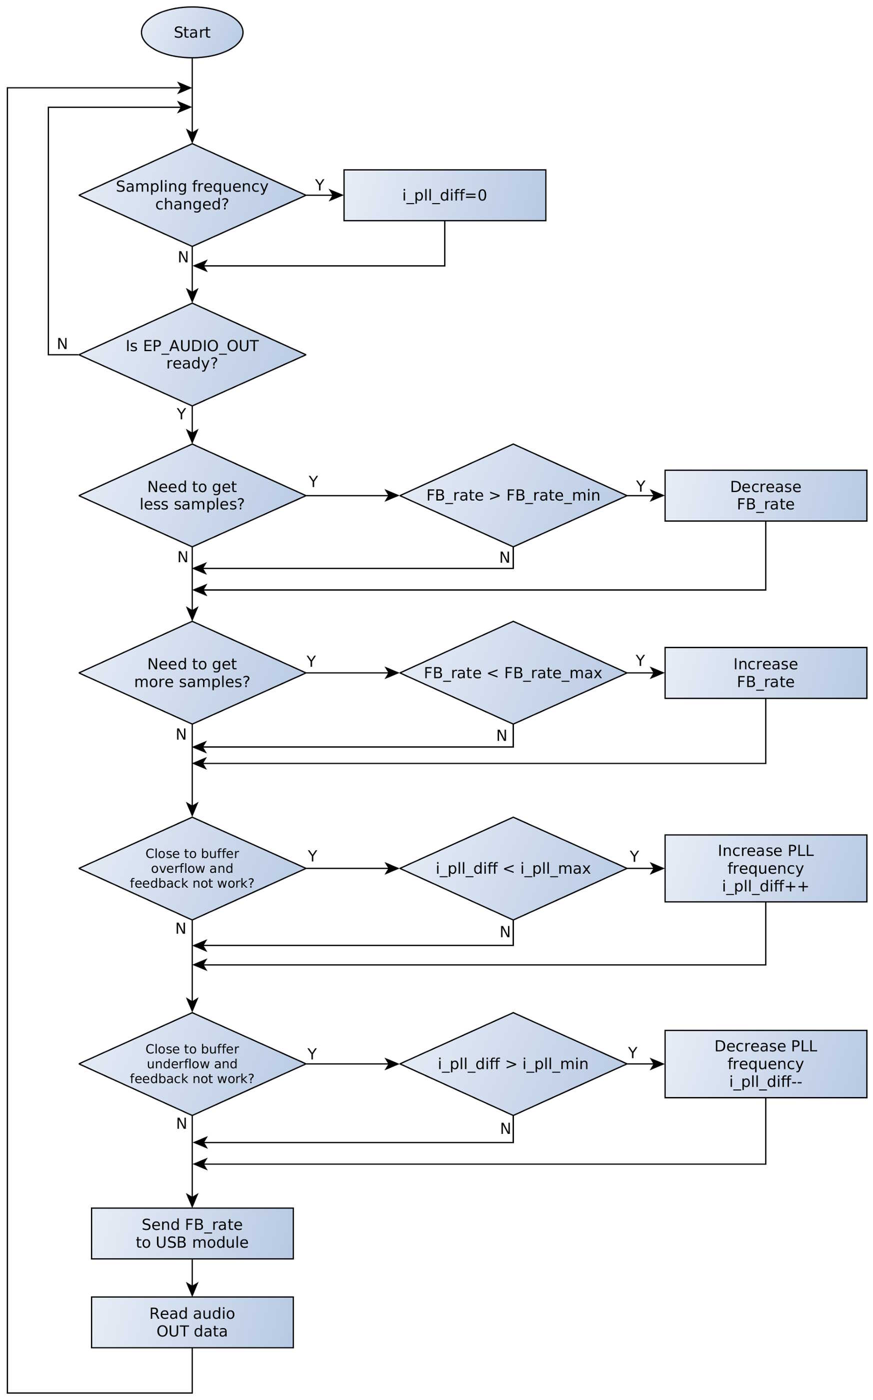
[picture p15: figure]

Obr. 17: Řešení synchronizace pro výstupní audio stream

Synchronizace vstupních dat je jednodušší než u výstupních. Podle aktuální vzorkovací frekvence je nastaven odhad počtu vzorků a čeká se, dokud není endpoint EP_AUDIO_IN připraven. V momentě, kdy je EP připraven, se zkontroluje stav bufferů, zda se neblíží podtečení, nebo přetečení. Pokud ano, pak je upraven počet vzorků, který se bude odesílat. Samozřejmě že program může být rozšířen o sadu podmínek, které mohou počet vzorků měnit více dle potřeby, ale princip zůstává stejný.

Synchronizace výstupních dat byla v rámci vývoje prioritizována, a proto je její implementace komplexnější. Prvně se testuje, zda byla změněna vzorkovací frekvence. Následuje kontrola dostupnosti endpointu EP_AUDIO_OUT. Pokud je EP připraven, pak se testuje zaplnění bufferů a funkčnost zpětné vazby. Pokud zpětná vazba funguje, pak se pouze upraví hodnota, která říká, kolik dat má host příště přenést. Pokud je detekována nefunkčnost zpětné vazby (například kvůli špatné podpoře v OS), pak je v určitých limitech měněna frekvence PLL, od které se odvíjí MCLK, BCLK a FRAME_SYNC. Krok je přibližně 10 ppm.

Modul SSC potřebuje ke své funkci v podstatě jen BCLK. Signál FRAME_SYNC si je schopen generovat podle nastavení v registrech a MCLK nepotřebuje vůbec. Protože SSC jednotka se skládá z RX a TX modulu, bylo zapotřebí některé piny hardwarově spojit. To se týká RX_FRAME_SYNC, TX_FRAME_SYNC (společný FRAME_SYNC) a dvojice RX_CLOCK a TX_CLOCK (společný BCLK). Softwarově je TX modul SSC nastaven tak, že přijímá BCLK. Pokud je v roli master, tak generuje FRAME_SYNC, jinak signál přijímá a odesílá data na pin TX_DATA. Modul RX pouze přijímá BCLK, FRAME_SYNC a RX_DATA. Kvůli flexibilnosti celé aplikace bylo zařízení navrženo tak, že směr (I²S konektor → MCU ; MCU → I²S konektor ; Hi-Z) signálů MCLK, BCLK, FRAME_SYNC, MUTE, RESET_I2S může být nastaven na libovolnou kombinaci. To je opět výhodné pro různé případy, kdy zařízení nepracuje čistě jako master, nebo slave.

Přehled jednotlivých scénářů je v Tab. 8. Pro větší přehlednost byl vstupní směr označen jako „I²S konektor → MCU“ a výstupní pak „MCU → I²S konektor“. Kvůli možné kombinaci jsou v popisu vždy všechny situace, které mohou nastat a případně uvedeny reference na dané signály. Signály MUTE a RESET_I2S slouží především pro ovládání připojených I²S zařízení a jsou volitelné.

Tab. 8: Možnosti nastavení směru signálů a jejich vlastnosti

Signál | Směr | Popis
MCLK | I²S konektor → MCU | Pouze kodek pro kontrolní odposlech vyžaduje korektní MCLK. Pokud MCLK není k dispozici, nebo nebude korektní, pak to neovlivní komunikaci mezi počítačem a zařízením.
| MCU → I²S konektor | Signál je generován pomocí externí PLL a děličky GCLK[0]. V případě, že nefunguje zpětná vazba pro nastavení počtu vzorků pro hosta, je frekvence automaticky měněna.
| Hi-Z | Signál je generován, takže kodek pro kontrolní odposlech funguje, ale na straně I²S konektoru je nastavena vysoká impedance. V případě, že nefunguje zpětná vazba pro nastavení počtu vzorků pro hosta, je frekvence automaticky měněna.
BCLK | I²S konektor → MCU | Signál z konektoru musí mít správnou frekvenci. Pokud je TX modul v SSC nastaven jako master, pak generuje FRAME_SYNC z BCLK. Zařízení je schopné v určitých mezích řešit nepřesnost tohoto signálu. U vstupního audio streamu zařízení provádí korekce tak, že mění počet vzorků, které budou odeslány hostu. Pokud u výstupního streamu nefunguje zpětná vazba, pak jediná možná korekce od zařízení je změna MCLK za předpokladu, že MCLK je nastaven jako výstupní. Pokud MCLK není nastaven jako výstupní a zpětná vazba není funkční, může po určitém časovém intervalu dojít k podtečení, nebo přetečení bufferů.
| MCU → I²S konektor | Signál je generován pomocí externí PLL a děličky GCLK[1]. V případě, že nefunguje zpětná vazba pro nastavení počtu vzorků pro hosta, je frekvence automaticky měněna.
| Hi-Z | Signál je generován, takže kodek pro kontrolní odposlech funguje, ale na straně I²S konektoru je nastavena vysoká impedance. V případě, že nefunguje zpětná vazba pro nastavení počtu vzorků pro hosta, je frekvence automaticky měněna.
FRAME_SYNC | I²S konektor → MCU | Signál z konektoru musí mít správnou frekvenci. Zařízení je schopné v určitých mezích řešit nepřesnost tohoto signálu. U vstupního audio streamu zařízení dle potřeby upraví počet odesílaných vzorků směrem k hostu. Pokud u výstupního streamu nefunguje zpětná vazba, pak jediná možná korekce od zařízení je změna MCLK a BCLK za předpokladu, že MCLK, nebo BCLK je nastaven jako výstupní. Pokud MCLK nebo BCLK není nastaven jako výstupní a zpětná vazba není funkční, může po určitém časovém intervalu dojít k podtečení, nebo přetečení bufferů.
| MCU → I²S konektor | Signál je generován z BCLK.
| Hi-Z | Signál je generován z BCLK, takže kodek pro kontrolní odposlech funguje (za předpokladu že BCLK a MCLK je korektní), ale na straně I²S konektoru je nastavena vysoká impedance.
MUTE | I²S konektor → MCU | Pokud je v nízké úrovni, funkce mute je vypnuta, jinak je funkce mute zapnuta. Čtení z pinu MUTE je aktivní pouze v případě, že I²S konektor je napájen. V případě, že je stisknuto tlačítko MUTE, funkce mute je zapnuta.
| MCU → I²S konektor | Signál je řízen úrovní z tlačítka MUTE.
| Hi-Z | Signál MUTE je na straně I²S konektoru ve vysoké impedanci. V případě, že je stisknuto tlačítko MUTE, funkce mute je zapnuta.
RESET_I2S | I²S konektor → MCU | Pokud je ve vysoké úrovni, provede se restart I²S konektoru (tzn. výchozí nastavení).
| MCU → I²S konektor | Signál je řízen úrovní z tlačítka RESET_I2S.
| Hi-Z | Signál RESET_I2S je na straně I²S konektoru ve vysoké impedanci. V případě, že je dlouze stisknuto tlačítko RESET_I2S, provede se restart I²S konektoru (tzn. výchozí nastavení).

## Tok HID dat

Třída HID je relativně jednoduchá jak na implementaci, tak na obsluhu a zároveň je standardem prakticky ve všech OS. Objemy přenesených dat jsou mnohem menší ve srovnání s audio daty, takže i samotné zpracování může být čistě na softwarové úrovni. Zjednodušený diagram je na Obr. 18.

Samotná funkce device_generic_hid_task() je velmi jednoduchá. Vývojový diagram je uveden na Obr. 19.

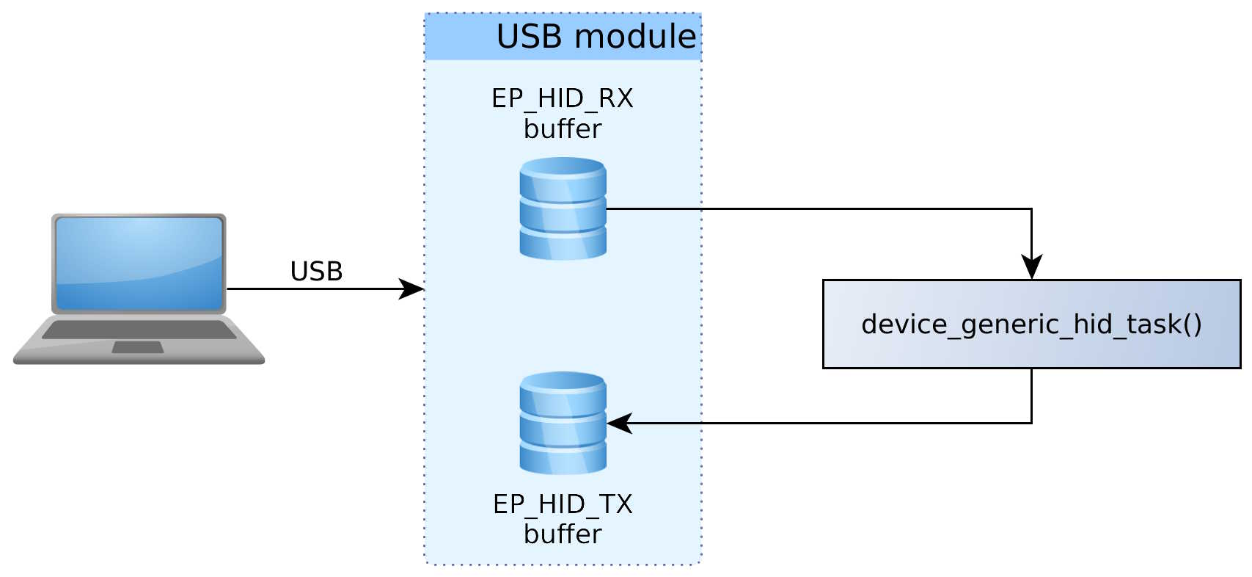
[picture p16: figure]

Obr. 18: Diagram pro přenos USB HID dat

Nejprve se kontroluje, zda je zařízení, resp. USB modul, enumerován. Pokud ano, testuje se, zda nebyla přenesena nějaká data od hosta. Pokud ano, pak jsou vyčteny a předány funkci Uniprot_rx_data(), která data zpracuje. Následuje získání hodnoty i_tx_enable, která poté rozhoduje, zda se budou odesílat data směrem k hostu, nebo ne. Pokud se mají odeslat data, musí se zkontrolovat, zda je EP připraven. Pokud je i tato podmínka splněna, pak je volána funkce Uniprot_tx_data(), které má za úkol připravit data k odeslání. Následně jsou data zapsána do EP. Funkce Uniprot_rx_data() a Uniprot_tx_data() jsou součástí jedné z vrstev komunikačního protokolu, který je popsán v kapitole 6.2.

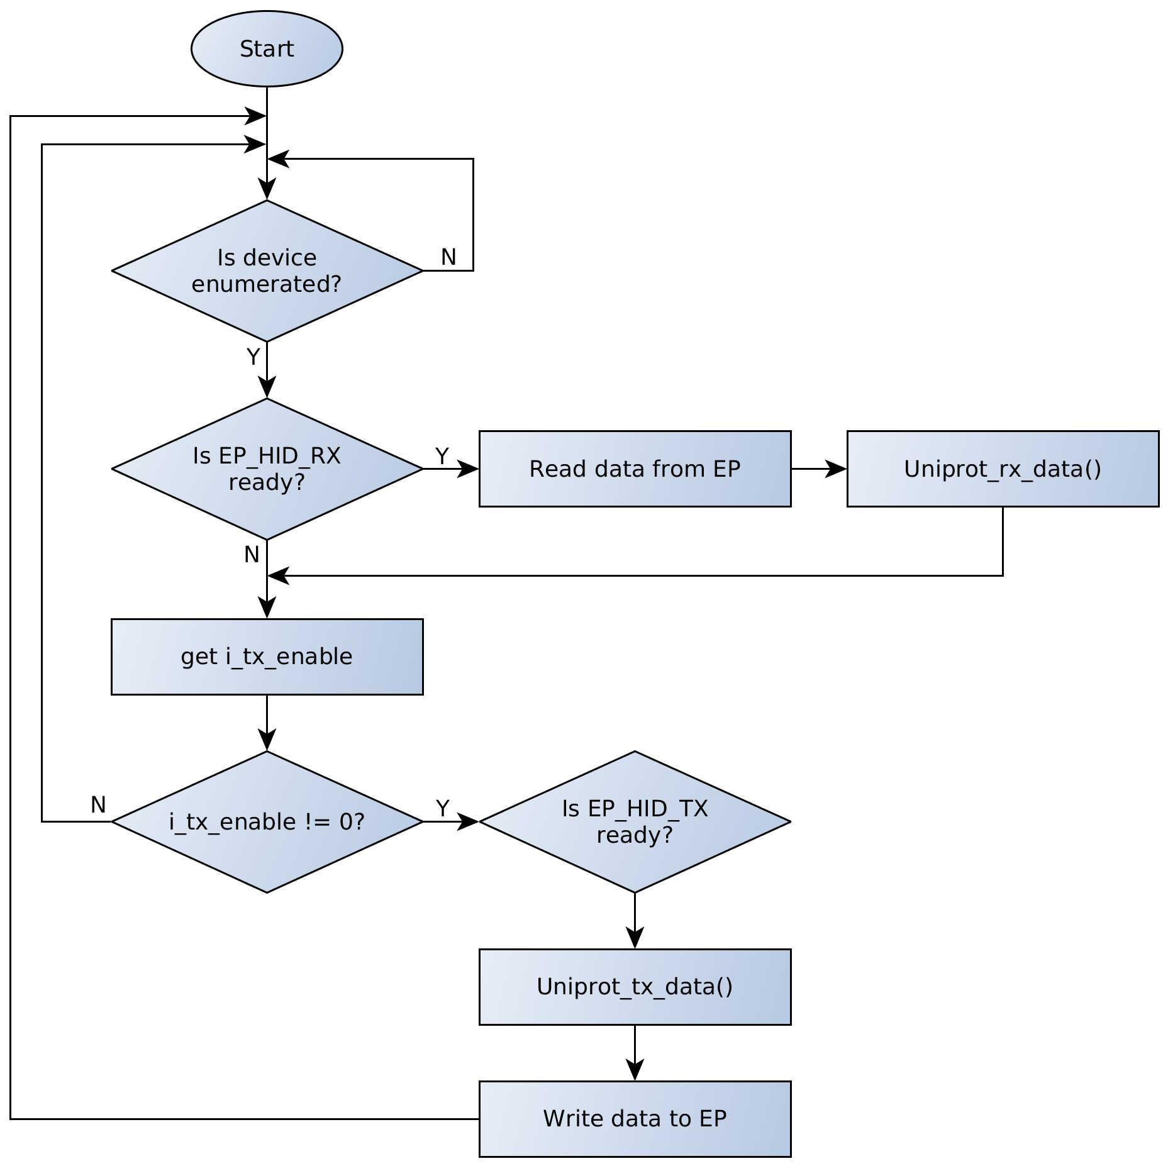
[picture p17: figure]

Obr. 19: Vývojový diagram funkce device_generic_hid_task()

# Vrstvy protokolu pro nastavení zařízení

Řídící a konfigurační protokol pro tento projekt byl navržen a z velké části implementován zcela obecně. Cílem bylo vytvořit opakovatelně použitelný systém, tj. protokol a knihovny pro zařízení s MCU a pro PC aplikaci. Tento systém má sloužit pro nastavování jakýchkoliv zařízení přes běžně používaná rozhraní. Tedy nejenom přes logické spojení v rámci USB HID, ale i např. přes UART apod.

Obecné řešení je inspirováno ISO/OSI komunikačním modelem a realizováno pomocí vrstev. Výsledkem je flexibilní software, který umožňuje velmi rychlé přidávání nových konfiguračních možností do zařízení s MCU, aniž by bylo potřeba jakkoliv modifikovat konfigurační PC aplikaci.

Praktičnost konceptu byla ověřena portací protokolu do jiného projektu mimo rámec této práce, kdy se s minimální námahou podařilo implementovat konfigurační rozhraní pro jiný projekt s jinými parametry a na jiné MCU architektuře. Pro konfiguraci bylo přitom možno používat stejnou PC aplikaci.

Samozřejmě toto řešení má i své nevýhody. Mezi největší nevýhody patří zejména potřeba vyšších výpočetního výkonu. Jak bylo naznačeno v předchozí kapitole, tento problém může efektivně řešit RTOS kvůli vhodnému nastavení priorit. Schématické rozvrstvení celého systému je na Obr. 20.

Nejnižší vrstva jsou ovladače k samotnému hardwaru, který má MCU řídit. Jako příklad jsou zde ovladače k PLL cs2200, kodeku TLV320AIC33 a ovladač pro desku jako takovou (LED, tlačítka atd.). Každý ovladač, který má využívat vrstva „generic driver“, musí tuto vrstvu podporovat.

Obr. 20: Systém komunikace jednotlivých vrstev

Samotná vrstva „generic driver“ umí kvůli metadatům uložených v ovladači poskytnout vyšším vrstvám potřebné informace o funkcích, které ovladač nabízí. Tato vrstva však požaduje jako jeden z argumentů ukazatel na adresu, kde se metadata daného ovladače nacházejí.

To řeší vrstva „HW“, která je jakýsi virtuální správce hardwaru. Tato vrstva zná adresy k metadatům jednotlivých ovladačů a umožňuje vyšším vrstvám přistupovat k jednotlivým ovladačům pomocí indexu. To je výhodné, pokud je zapotřebí využívat více zařízení, která jsou připojena k MCU.

Vrstva „uniprot“ má za úkol bezpečně přijímat a odesílat data. Tato vrstva umožňuje pracovat s několika datovými toky, ale v této aplikaci je využit pouze jeden a to USB HID. V principu je jedno, jestli jsou data přenášena přes USB, UART, I²C nebo SPI. Vrstva „uniprot“ předává vrstvám již celé pakety dat.

Propojení mezi vrstvami „HW“ a „uniprot“ řeší vrstva „bridge“. Tato vrstva udává, jak budou datové pakety vypadat. Je totiž potřeba definovat, jakým způsobem bude identifikován konkrétní požadavek a konkrétní odpověď. Tato vrstva abstrahuje „HW“ a posílá surová data pomocí vrstvy „uniprot“.

Všechny vrstvy byly napsány tak, aby podporovaly jak architekturu AVR8, tak AVR32. Teoreticky by kód měl být funkční i na dalších architekturách, ale z časových důvodů nebylo možné vyzkoušet další architektury.

## Generic driver a HW

Soubor metod, které umožňují přistupovat k libovolnému ovladači (který podporuje „generic driver“) předdefinovaným způsobem. Výhodou je, že ačkoliv ovladač může obsluhovat různá zařízení, přístup k nim je vždy stejný.

Každý ovladač, který má podporovat „generic driver“, musí obsahovat tabulku podporovaných příkazů a metadata k této tabulce. Tabulka podporovaných příkazů je jen pole struktur. Jako příklad je zde část kódu z ovladače pro externí PLL:

const gd_config_struct CS2200_config_table[]

{

{

0, // Command ID

"Initialize CS2200 hardware", // Name

"Initialize I/O and TWI module (if used)", // Descriptor

void_type, // Input data type

{.data_uint32 = 0}, // Minimum input value

{.data_uint32 = 0}, // Maximum input value

void_type, // Output data type

{.data_uint32 = 0}, // Minimum output value

{.data_uint32 = 0}, // Maximum output value

(GD_DATA_VALUE*)&gd_void_value, // Output value

cs2200_init // Function, that should be called

},

{

1,

"Set PLL frequency",

"Frequency format: unsigned 32 bit in Hz",

uint32_type,

{.data_uint32 = 6000000}, // Min 6 MHz

{.data_uint32 = 75000000}, // Max 75 MHz

uint32_type,

{.data_uint32 = 6000000},

{.data_uint32 = 75000000},

(GD_DATA_VALUE*)&s_virtual_reg_img.i_real_freq.i_32bit,

cs2200_set_PLL_freq

},

První položka je číslo příkazu. Ve své podstatě je to zároveň i index v poli, takže se jeho informace může jevit jako redundantní. Pokud je vše v pořádku, pak se jedná skutečně o redundantní informaci. Ale v momentě, kdy je některý ukazatel špatně nastaven, za pomocí této informaci je možné velice rychle najít chybu. Je to obdoba CRC součtu. Jedná se o redundantní informaci, dokud je vše v pořádku.

Následuje název funkce. Jedná se pole znaků, jehož maximální délka je definována v souboru generic_driver.h jako GD_MAX_STRING_SIZE. Jeho hodnotu lze měnit v závislostech na požadavcích aplikace, ale doporučená hodnota je 80. To znamená 79 viditelných znaků a znak null. To je pro většinu případů dostatečná rezerva a zároveň je to dobrý kompromis mezi popisem funkce a náročnosti na RAM MCU.

Třetí položka je popis funkce. Délka popisu je opět definována jako GD_MAX_STRING_SIZE. Zde je vhodné popsat, co funkce dělá, v jakých jednotkách jsou vstupní hodnoty, nebo jakých hodnot může nabývat (např: „0 – input ; 1 – output“).

Jako další v pořadí je datový typ pro vstupní parametr funkce. Přehled datových typů je v Tab. 9.

Tab. 9: Přehled datových typů používaných "generic driverem"

Datový typ | Popis
void_type | Prázdný datový typ. Volaná funkce nezpracovává žádný vstupní argument.
char_type | Jeden 8bitový ASCII znak.
int_type | Znaménkové celé číslo. U většiny architektur definováno jako 32bitové, ale například u AVR8 je 16bitové. Z tohoto důvodu není doporučeno tento datový typ používat. Na straně počítače jej aplikace zpracovává vždy jako 32bitové!
int8_type | Znaménkové 8bitové číslo.
int16_type | Znaménkové 16bitové číslo.
int32_type | Znaménkové 32bitové číslo.
uint_type | Neznaménkové celé číslo. U většiny architektur definováno jako 32bitové, ale opět není podmínkou. Proto není doporučeno tento datový typ používat. Na straně počítače jej aplikace zpracovává vždy jako 32bitové.
uint8_type | Neznaménkové 8bitové číslo.
uint16_type | Neznaménkové 16bitové číslo.
uint32_type | Neznaménkové 32bitové číslo.
float_type | Třiceti dvou bitové číslo s plovoucí desetinnou čárkou.
group_type | Definuje zvláštní příkaz, který je množinou několika funkcí, a uživatel pak vybírá jednou z nich.

Následuje minimální a maximální hodnota pro argument funkce. Pokud funkce nepotřebuje žádný argument, je vhodné nastavit obě hodnoty jako 32bitové nuly.

Jako další je zde datový typ pro výstupní hodnotu. Zde jsou možnosti stejné jako pro argument funkce – viz. Tab. 9.

I výstupní hodnota by měla mít definované své limity, takže další dvě hodnoty udávají minimální a maximální přípustnou hodnotu výstupní proměnné. Pokud funkce neposkytuje žádnou výstupní hodnotu, je vhodné nastavit oba limity jako 32bitové nuly.

Jako předposlední je zde ukazatel (adresa) na proměnnou, kam je uložena výsledná výstupní hodnota funkce. Ukazatel proto, aby celá tabulka mohla být jen výčet konstant, a tím pádem mohla být uložená v paměti programu a ne v RAM, které bývá v MCU nedostatek.

Poslední hodnota je ukazatel na funkci, která má být volána.

Každá tabulka musí mít definovaná metadata, prostřednictvím nich je možné tabulku jednoznačně identifikovat. Metadata nejsou nic jiného než struktura, která obsahuje následující konstanty:

- počet příkazů v tabulce,
- textový popis ovladače (maximální délka definována GD_MAX_STRING_SIZE),
- ukazatel na první prvek tabulky,
- sériové číslo (8bitové).

Díky znalosti celkovému počtu příkazů v tabulce je možné provádět scan zařízení (tzn. získat seznam funkcí, které nabízí). Textový popis je pro uživatele, aby věděl, který ovladač právě používá. Protože struktura tabulky je předem daná a její délka je také známa (je definován celkový počet příkazů), stačí znát adresu prvního prvku v tabulce a další se dají velice jednoduše dopočítat. Sériové číslo je tu například pro rozeznání dvou hardwarově stejných desek, nebo pro odlišení jednotlivých hardwarových revizí. Příklad metadat je na následujících řádcích:

const gd_metadata CS2200_metadata =

{

CS2200_MAX_CMD_ID, // Max CMD ID

"Fractional PLL CS2200-CP v0.7", // Description

(gd_config_struct*)&CS2200_config_table[0], // Pointer to table

0x21 // Serial number (0~255)

};

Samotný „generic driver“ nabízí pouze dvě funkce: gd_get_setting() a gd_set_setting(). Funkce gd_get_setting() zjistí veškeré parametry funkce (datové typy, rozsah hodnot, ukazatel na výstupní hodnotu, ukazatel na funkci) na základě ukazatele na metadata a ID příkazu. Funkce gd_set_setting() zavolá funkci. K tomu potřebuje platný ukazatel na metadata, ID příkazu a hodnotu argumentu.

Jak bylo popsáno výše, vrstva „HW“ je jen abstrakcí vrstvy „generic driver“. Zároveň je jakýmsi virtuálním správcem zařízení, resp. jejich ovladačů. Protože ne každé zařízení musí být nutně přístupné z pohledu konfigurace (některé zařízení je vhodné zpřístupnit např. jen pro debug fázi projektu), je na uživateli, aby v souboru HW.h definoval, které ovladače bude tato vrstva spravovat. Definice je velmi snadná:

/// \brief Board driver

#define DEVICE0 BRD_DRV_metadata

#include "brd_driver_hw_03.h"

/// \brief TLV320AIC33 codec

#include "tlv320aic33.h"

#define DEVICE1 TLV320AIC33_metadata

/// \brief Fractional PLL CS2200

#include "cs2200.h"

#define DEVICE2 CS2200_metadata

Nejprve musí být definováno symbolické jméno pro zařízení. Je nutné, aby symbolické jméno bylo ve formátu „DEVICEx“, kde „x“ je index použitého ovladače, které pak používá tato a všechny vyšší vrstvy. Následuje jméno proměnné, ve které jsou uložena metadata. Pak už jen zbývá přidat include s patřičným souborem.. Analogicky se definují další zařízení. Aktuální verze umožňuje takto „připojit“ až deset zařízení a rozšíření je jen otázkou drobné modifikace v hlavičkovém souboru.

Aby byl celkový koncept dostatečně flexibilní, byla vytvořena funkce, která vrátí index posledního zařízení – hw_get_max_device_index(). To umožní aplikaci na počítači proskenovat všechna zařízení obsažená v „HW“. Protože jednotlivá zařízení jsou rozlišována indexem, je vhodné dát vyšším vrstvám možnost získat metadata. To je možné pomocí funkce hw_get_device_metadata(), která jako argument používá index zařízení. Funkce hw_get_setting() a hw_set_setting() jsou obdobou gd_get_setting() a gd_set_setting(), které jsou vysvětleny výše. Jediný rozdíl je ve vstupních parametrech. Funkce z vrstvy „HW“ používají pro identifikování zařízení indexy, zatímco funkce z „generic driver“ používají přímo metadata.

## Universal protocol

Tato vrstva má za úkol zabezpečit a přenést data pro vyšší vrstvu. Aktuální verze umožňuje, aby „universal protocol“ obsluhoval až 7 nezávislých datových streamů z různých periferií. Rozšíření počtu je jen otázkou několika drobných modifikací v kódu a hlavičkovém souboru. Každý datový stream používá virtuální kanál, který je pak značen PIPE0 až PIPE6 (pro 7 zařízení). V rámci vrstveného modelu tento protokol sám o sobě neobsahuje žádné ovladače k periferiím pro datovou komunikaci, pouze nabízí obslužné funkce. Ostatně ani není cílem, aby podporoval různé periferie nativně, protože tím by se kód stal nepřehledným a zároveň by byl těžko přenositelný. Namísto toho musí být upraven ovladač pro konkrétní periferii, ale modifikace je jednoduchá, takže ve většině případů to neznamená, že by ovladač musel být přepsán od začátku. Níže je naznačen postup s příkladem pro PIPE0 (tzn. je použit pouze jeden kanál):

1. Úprava hlavičkového souboru uniprot.h. Je nutné includovat hlavičkový soubor ovladače.
  #include „device_generic_hid.h“
2. Pokud ovladač nepodporuje „universal protocol“, pak v místě, kde ovladač přijímá data, je potřeba vložit funkci Uniprot_rx_data(), které jsou data předána. V místě, kde dochází k odesílání dat, je situace komplikovanější. Nejprve musí být volána funkce Uniprot_Is_TX_transmission_enable(). Pokud tato funkce vrátí 1, pak je možné zavolat Uniprot_tx_data(), která naplní požadovaný buffer daty. Poté může ovladač začít vysílat.
3. Pokud ovladač podporuje „universal protocol“, tak v jeho hlavičkovém souboru by měly být definovány UNI_PIPE0_FRAME_SIZE (udává kolik Bajtů ovladač přenese najednou), UNI_PIPE0_FUNC_INIT (definuje jméno inicializační funkci pro ovladač) a UNI_PIPE0_FUNC_TASK (definuje jméno tasku pro ovladač). Pokud v jeho hlavičkovém souboru nejsou, pak je možné je dodefinovat v souboru uniprot.h.
  /// Define frame size (number of bytes per one transmission)
  #define UNI_PIPE0_FRAME_SIZE 8
  /// Initialize function which will be called in initialization process
  #define UNI_PIPE0_FUNC_INIT \
  device_generic_HID_init(UAC1_EP_HID_RX, UAC1_EP_HID_TX)
  /// Driver task
  #define UNI_PIPE0_FUNC_TASK \
  device_gneric_hid_task()

V případě čtení vyšší vrstva musí nejprve nakonfigurovat příchozí paket. To se provede pomocí Uniprot_config_RX_packet(). Pak jen čeká až funkce Uniprot_Is_RX_pipe_ready() vrátí 1. V ten moment jsou data v bufferu platná.

Odesílání dat je velice podobné. Nejprve se musí naplnit buffer daty a nakonfigurovat odchozí paket pomocí Uniprot_config_TX_packet(). Pak už jen zbývá čekat, až funkce Uniprot_Is_TX_pipe_ready() vrátí 1.

### Základní scénáře při komunikaci

Za ideálních podmínek by se žádná data neztrácela a celý „universal protokol“ by pouze parsoval data. V reálném prostředí je ale ztráta dat vždy možná. Ať už je to hardwarem (špatný kontakt), nebo na straně OS (přetečení bufferu kvůli pomalému multitaskingu apod. ). Proto se musí řešit různé výjimky, které mohou nastat. Na Obr. 21 je zobrazen přenos dat bez potíží. Veškeré další diagramy platí pro obecné zařízení DEV1 a DEV2. Není tedy pevně dáno, které zařízení je master a které slave. Tato vrstva řeší pouze přenos dat.

DEV1 odešle datový paket (o určité struktuře) a DEV2 přijme data. Proběhne kontrola data (CRC). V tomto případě je vše v pořádku a DEV2 odešle příkaz „ACK“ a informuje vyšší vrstvu o úspěšném přijetí dat. Poté co DEV1 přijme „ACK“ je vyšší vrstva informována o úspěšné přenosu dat.

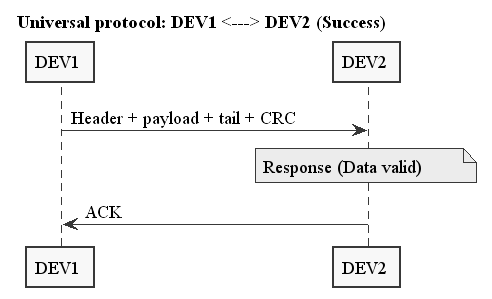
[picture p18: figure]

Obr. 21: Úspěšný přenos dat

Na Obr. 22 je případ, kdy jsou data nějakým způsobem poškozena.

Po příjmu dat bylo pomocí CRC detekováno jejich poškození. DEV2 vyšle příkaz „NACK“. DEV1 přijme příkaz a vyšle stejná data znovu. Podruhé jsou již data v pořádku a DEV1 odesílá „ACK“. Vyšší vrstvy na obou stranách jsou informovány o úspěšné operaci. V případě, že ani podruhé se data nepřenesou v pořádku, opakuje se celý proces, dokud se nedosáhne definovaného počtu pokusů. Tento počet pokusů není pevně nastavený a je na programátorovi, aby zvolil vhodné číslo v závislost na tom, po jaké sběrnici jsou data odesílána. Pokud je tento počet překročen, vyvolá se interní chyba, která způsobí reinicializaci ovladačů a vrstvy „universal protokolu“. Tento proces je na Obr. 23.

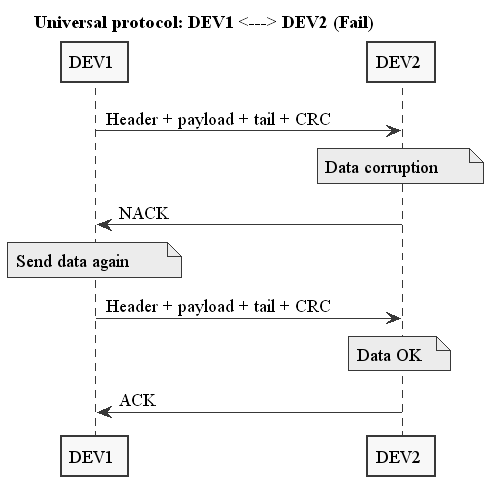
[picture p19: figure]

Obr. 22: Řešení poškození dat

Pokud nastane tato situace, pak to značí, že chybovost přenosového kanálu je vysoká. Jako poslední možnost zotavení se pak jeví reinicializovat ovladače a „universal protokol“ samotný. Pokud je indikována interní chyba, pak zařízení, které chybu detekuje, odešle příkaz „RESET“. Poté se obě zařízení reinicializují. Pokud by příkaz „RESET“ nebyl doručen DEV1, pak by při další komunikaci nastala chyba na straně DEV1 a to by odeslalo příkaz „RESET“ a samo by se reinicializovalo. Poté by měly být obě strany připraveny pro další komunikaci.

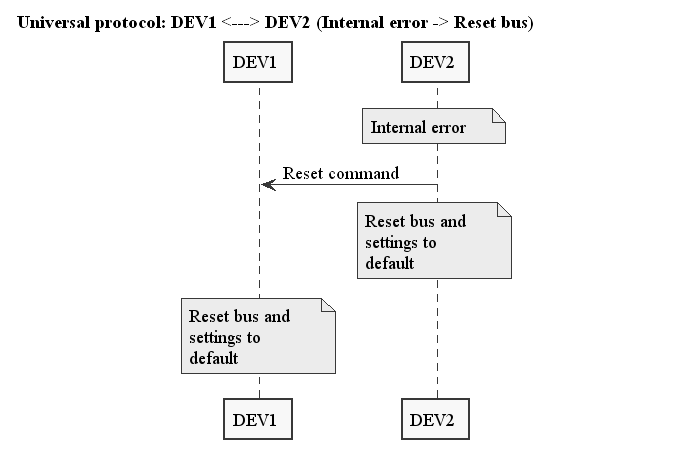
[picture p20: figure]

Obr. 23: Resetování ovladačů a "universal protokolu"

Dále se může objevit problém s příchozími daty. Problém je nastíněn na Obr. 24.

V tomto scénáři poslal DEV1 více dat, než na kolik byl DEV2 připraven. Aby nedošlo k přetečení vstupních bufferů (a přepisu náhodných dat v RAM), jsou veškerá nadbytečná data ihned zahazována. Poté DEV2 odešle odpověď „BUFFER OVERFLOW“. Co se týče protokolu, tak zde žádná chyba není. Chyba je na straně vyšší vrstvy, která buďto špatně nakonfigurovala vstupní paket (DEV2), nebo nerespektuje hardwarová omezení druhé strany (v tom případě je chyba na vyšší vrstvě u DEV1).

Obr. 24: Signalizace přetečení vstupního bufferu

Chyb může v reálné situaci nastat více. Většinu z nich je výhodné řešit na úrovni aplikace pro PC, kde lze pracovat ve vyšším programovacím jazyce a kde se prakticky nemusí řešit nároky na paměť, nebo výpočetní výkon. Zde uvedené případy ale pokrývají drtivou většinu všech v praxi se vyskytujících problémů.
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

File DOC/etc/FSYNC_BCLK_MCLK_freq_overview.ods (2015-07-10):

 | FSYNC frequency [Hz]
BCLK/MCLK Oversampling | 8 000 | 11 025 | 16 000 | 22 050 | 24 000 | 32 000 | 44 100 | 48 000
16 | 128 000 | 176 400 | 256 000 | 352 800 | 384 000 | 512 000 | 705 600 | 768 000
32 | 256 000 | 352 800 | 512 000 | 705 600 | 768 000 | 1 024 000 | 1 411 200 | 1 536 000
64 | 512 000 | 705 600 | 1 024 000 | 1 411 200 | 1 536 000 | 2 048 000 | 2 822 400 | 3 072 000
128 | 1 024 000 | 1 411 200 | 2 048 000 | 2 822 400 | 3 072 000 | 4 096 000 | 5 644 800 | 6 144 000
256 | 2 048 000 | 2 822 400 | 4 096 000 | 5 644 800 | 6 144 000 | 8 192 000 | 11 289 600 | 12 288 000
512 | 4 096 000 | 5 644 800 | 8 192 000 | 11 289 600 | 12 288 000 | 16 384 000 | 22 579 200 | 24 576 000
 | FSYNC frequency [Hz]
BCLK/MCLK Oversampling | 8 000 | 11 025 | 16 000 | 22 050 | 24 000 | 32 000 | 44 100 | 48 000
16 | 128 000 | 176 400 | 256 000 | 352 800 | 384 000 | 512 000 | 705 600 | 768 000
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

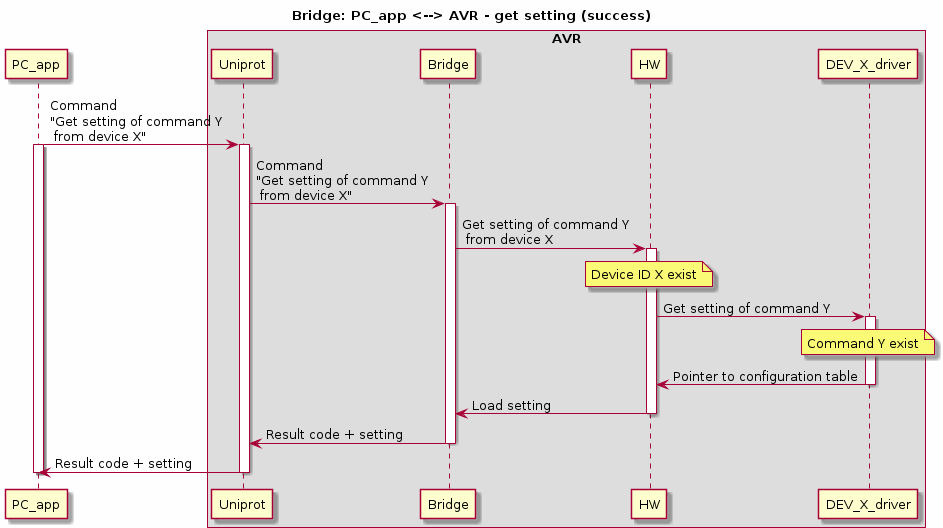
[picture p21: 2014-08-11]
DOC/thesis/thesis_doc_files/bridge_get_setting_all_OK.gif

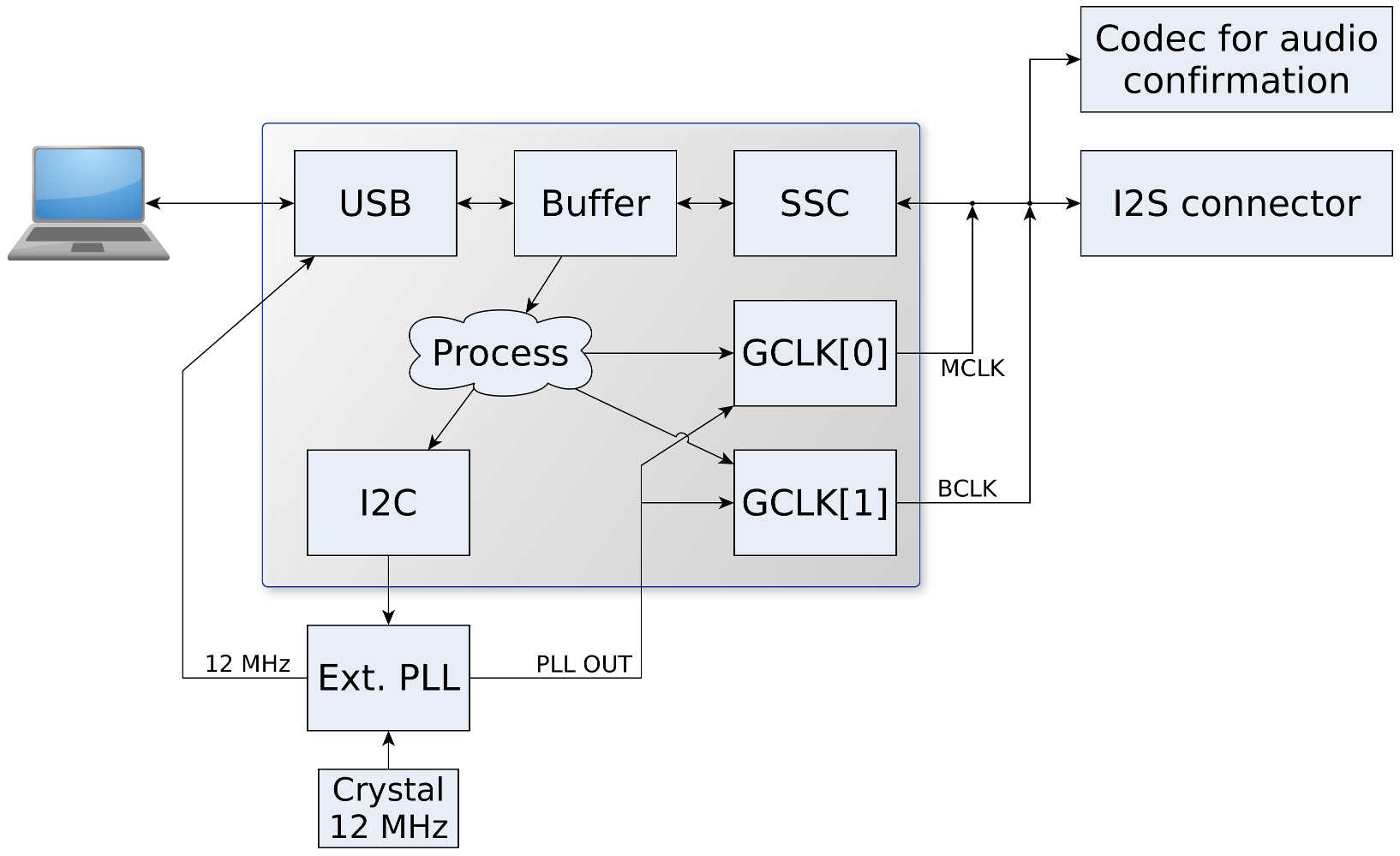
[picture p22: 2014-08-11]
DOC/thesis/thesis_doc_files/external_PLL_block_scheme.jpg

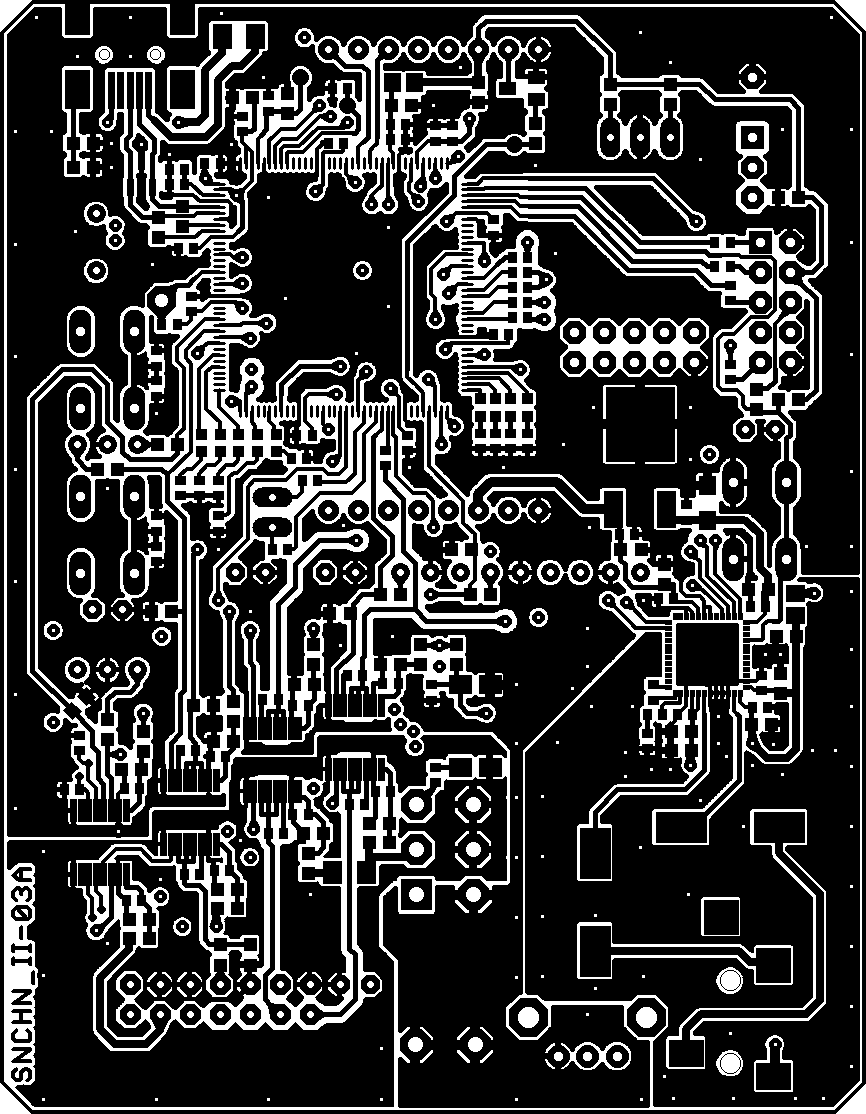
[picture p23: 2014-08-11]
DOC/thesis/thesis_doc_files/SNCHN_II-03A-brd_1_top.png

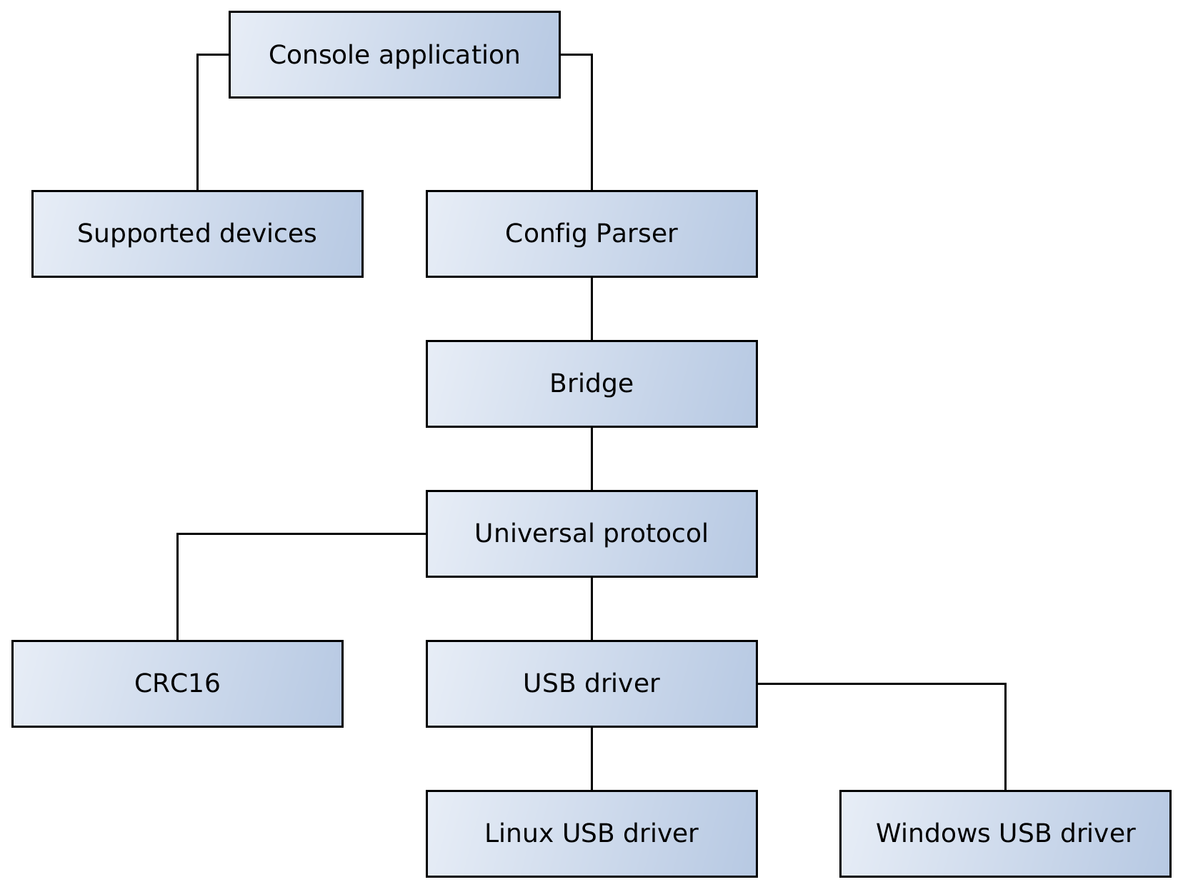
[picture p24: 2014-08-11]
DOC/thesis/thesis_doc_files/pc_application_layers.png

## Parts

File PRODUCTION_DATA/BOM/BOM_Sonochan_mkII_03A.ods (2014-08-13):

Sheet: GME
Objednávka GME |  |  |  |  |  | * Cena bez DPH
Kód | GME Kód | Ks | Cena za 1 ks | Cena za 10 ks | Popis | Cena pro 1 ks | Cena pro 10 ks
Konektor XINYA MLW14A | 800-045 | 1 | 7.3339 | 7.3339 | Konektor pro ploché kabely do DPS 90°, rozteč 2,54mm, 2x7 kontaktů.
Oboustranný kolík XINYA S1G20 2,54mm | 832-017 | 1 | 4.0744 | 4.0774 | Oboustranný kolík přímý, 1 řady, rozteč 2,54mm, 20 pinů.
Oboustranný kolík XINYA S2G20 2,54mm | 832-023 | 1 | 4.44 | 4.44 | Oboustranný kolík přímý, 2 řady, rozteč 2,54mm, 2x10 pinů.
Dutinková lišta XINYA BL25G | 832-074 | 1 | 13.0496 | 13.0496 | Dutinková lišta rovná, 1 řady, rozteč 2,54mm, 25 pinů.
GFA5 | 623-146 | 4 | 2.24 | 2.09 | přístr.nožička samolep. 7,9x2,2 Transparentní
Distanční sloupek plastový M3 M/F KSS KDA6M3X10 W | 623-105 | 3 | 3.7025 | 3.3322 | Distanční sloupek, délka sloupku bez závitu 10mm, délka závitu 6mm, závit M3, na koncích šroub a závit
Suma
Suma

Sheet: Farnell
Farnell |  |  |  |  |  | * Cena bez DPH
Typové označení | Objednací kód | Ks | Cena za 1 kus | Cena za 10 ks | Popis | Cena pro 1 kus | Cena pro 10 ks
7201MD9AV2BE | 9575529 | 1 | 117.03 | 117.03 | C & K COMPONENTS - 7201MD9AV2BE - SWITCH, PCB, DPDT
2AS1T2A1M7RE | 9473165 | 1 | 68.15 | 68.15 | MULTICOMP - 2AS1T2A1M7RE - SWITCH, PCB, SPDT, HORIZ
VOM617A-7X001T | 2251588 | 1 | 4.99 | 4.99 | VISHAY - VOM617A-7X001T - OPTOCOUPLER, TRANS., 80-160%, 5MA, VDE
MCL039PURGW | 1581194 | 5 | 7.71 | 4.71 | MULTICOMP - MCL039PURGW - LED, 3MM, HI-RED/GRN, 30MCD/10MCD
TLHY4401 | 2251300 | 1 | 3.48 | 3.48 | VISHAY - TLHY4401 - LED, 3MM, YELLOW, TINTED DIFFUSED
MC20451 | 1249911 | 2 | 3.24 | 3.24 | MULTICOMP - MC20451 - LED, GREEN, T-1 3/4 (5MM), 20MCD, 565NM
TLHK46Q1R2 | 2251295 | 1 | 3.79 | 3.79 | VISHAY - TLHK46Q1R2 - LED, 3MM, RED, TINTED DIFFUSED
Suma

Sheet: Digikey
Digikey
Produkt | Part number | Počet ks. | Cena pro 1 ks | Cena pro 10 ks | Popis | Cena pro 1 ks | Cena pro 10 ks
LW Q38G-Q1S1-3K6L-1 | 475-2832-1-ND | 9 | 0.28 | 0.229 | LED CHIPLED WHT 8200K 0603 SMD
RMCF0603ZT0R00 | RMCF0603ZT0R00CT-ND | 1 | 0.02 | 0.017 | RES 0.0 OHM 1/10W JUMP 0603
RMCF1206ZT0R00 | RMCF1206ZT0R00CT-ND | 2 | 0.05 | 0.034 | RES 0.0 OHM 1/4W JUMP 1206
C1S 1 | 507-1186-1-ND | 1 | 0.35 | 0.329 | FUSE 1A 63V 1206 SLOW C1S
RMCF0603JT1M00 | RMCF0603JT1M00CT-ND | 1 | 0.02 | 0.017 | RES 1M OHM 1/10W 5% 0603
RMCF0603JT1K00 | RMCF0603JT1K00CT-ND | 1 | 0.02 | 0.017 | RES 1K OHM 1/10W 5% 0603
ECH-U1C102JX5 | PCF1471CT-ND | 1 | 0.61 | 0.513 | CAP FILM 1000PF 16VDC 0603
C0402C121J5GACTU | 399-7769-1-ND | 3 | 0.1 | 0.0216 | CAP CER 120PF 50V 5% NP0 0402
CL10F105ZP8NNNC | 1276-1041-1-ND | 30 | 0.0288 | 0.0152 | CAP CER 1UF 10V Y5V 0603
RMCF0402FT2K20 | RMCF0402FT2K20CT-ND | 1 | 0.04 | 0.025 | RES 2.2K OHM 1/16W 1% 0402
T491A475M010AT | 399-3698-1-ND | 4 | 0.34 | 0.294 | CAP TANT 4.7UF 10V 20% 1206
RMCF0603JT4K70 | RMCF0603JT4K70CT-ND | 2 | 0.02 | 0.017 | RES 4.7K OHM 1/10W 5% 0603
RMCF0402JT6K80 | RMCF0402JT6K80CT-ND | 1 | 0.02 | 0.017 | RES 6.8K OHM 1/16W 5% 0402
MCR03ERTF10R0 | RHM10.0CFCT-ND | 16 | 0.011 | 0.0047 | RES 10 OHM 1/10W 1% 0603 SMD
RMCF0402JT10K0 | MCF0402JT10K0CT-ND | 6 | 0.02 | 0.0092 | RES 10K OHM 1/16W 5% 0402
RMCF0603JT10K0 | RMCF0603JT10K0CT-ND | 3 | 0.02 | 0.017 | RES 10K OHM 1/10W 5% 0603
CC0402KRX7R9BB102 | 311-1036-1-ND | 3 | 0.1 | 0.0088 | CAP CER 1000PF 50V 10% X7R 0402
C0603C102K5RACTU | 399-1082-1-ND | 3 | 0.1 | 0.0172 | CAP CER 1000PF 50V 10% X7R 0603
C0402C100J5GACTU | 399-1011-1-ND | 1 | 0.1 | 0.027 | CAP CER 10PF 50V 5% NP0 0402
9B-12.000MEEJ-B | 887-1238-ND | 1 | 0.48 | 0.4 | CRYSTAL 12MHZ 18PF THRU
RMCF0603JT22R0 | RMCF0603JT22R0CT-ND | 1 | 0.02 | 0.017 | RES 22 OHM 1/10W 5% 0603
C1608C0G1H220J080AA | 445-1273-1-ND | 2 | 0.1 | 0.03 | CAP CER 22PF 50V 5% NP0 0603
RC0402JR-0733RL | 311-33JRCT-ND | 23 | 0.013 | 0.0053 | RES 33 OHM 1/16W 5% 0402 SMD
RMCF0603FT33R0 | RMCF0603FT33R0CT-ND | 2 | 0.04 | 0.025 | RES 33 OHM 1/10W 1% 0603
MLZ2012M330WT000 | 445-6399-1-ND | 4 | 0.14 | 0.125 | INDUCTOR MULTILAYER 33UH 0805
RMCF0603JT39R0 | RMCF0603JT39R0CT-ND | 2 | 0.02 | 0.017 | RES 39 OHM 1/10W 5% 0603
RMCF0402JT47R0 | RMCF0402JT47R0CT-ND | 4 | 0.02 | 0.017 | RES 47 OHM 1/16W 5% 0402
RMCF0603JT47R0 | RMCF0603JT47R0CT-ND | 1 | 0.02 | 0.017 | RES 47 OHM 1/10W 5% 0603
RMCF0402FT47K0 | RMCF0402FT47K0CT-ND | 5 | 0.04 | 0.0138 | RES 47K OHM 1/16W 1% 0402
MCR03ERTJ473 | RHM47KCGCT-ND | 12 | 0.01 | 0.0042 | RES 47K OHM 1/10W 5% 0603 SMD
RMCF0402JT100R | RMCF0402JT100RCT-ND | 2 | 0.02 | 0.017 | RES 100 OHM 1/16W 5% 0402
CL05A104MP5NNNC | 1276-1443-1-ND | 46 | 0.0084 | 0.00452 | CAP CER 0.1UF 10V 20% X5R 0402
RMCF0603JT220R | RMCF0603JT220RCT-ND | 1 | 0.02 | 0.017 | RES 220 OHM 1/10W 5% 0603
CL05F224ZO5NNNC | 1276-1060-1-ND | 2 | 0.1 | 0.041 | CAP CER 0.22UF 16V Y5V 0402
UUQ1E221MCL1GS | 493-3204-1-ND | 2 | 1.54 | 1.262 | CAP ALUM 220UF 25V 20% SMD
RMCF0603JT270R | RMCF0603JT270RCT-ND | 6 | 0.02 | 0.0092 | RES 270 OHM 1/10W 5% 0603
RMCF0603FT330R | RMCF0603FT330RCT-ND | 6 | 0.04 | 0.025 | RES 330 OHM 1/10W 1% 0603
RMCF0603JT390R | RMCF0603JT390RCT-ND | 2 | 0.02 | 0.017 | RES 390 OHM 1/10W 5% 0603
RC0402JR-07470RL | 311-470JRCT-ND | 10 | 0.013 | 0.0053 | RES 470 OHM 1/16W 5% 0402 SMD
AT32UC3A3256-ALUT | AT32UC3A3256-ALUT-ND | 1 | 16.5 | 15.002 | IC MCU 32BIT 256KB FLASH 144LQFP
CS2200CP-CZZ | 598-1752-ND | 1 | 6.46 | 5.771 | IC CLK MULT FRACTIONAL N 10MSOP
LD39300DT18-R | 497-6873-1-ND | 1 | 1.57 | 1.388 | IC REG LDO 1.8V 3A DPAK
LF33ABDT-TR | 497-5225-1-ND | 2 | 0.95 | 0.83 | IC REG LDO 3.3V 0.5A DPAK
LTV-816S | 160-1361-5-ND | 1 | 0.39 | 0.278 | OPTOISOLATR 5KV TRANSISTOR 4-SMD
690-005-299-043 | 151-1206-1-ND | 1 | 0.41 | 0.385 | CONN MINI USB RCPT RA TYPE B SMD
SI8642BA-B-IU | 336-2091-5-ND | 6 | 2.41 | 2.3168 | IC ISOLATOR 4CH 1KV 16QSOP
SI8645BA-B-IU | 336-2096-5-ND | 2 | 2.41 | 2.41 | IC ISOLATOR 4CH 1KV 16QSOP
TLV320AIC33IRGZR | 296-19789-1-ND | 1 | 8.01 | 7.204 | IC STEREO AUDIO CODEC 48-VQFN
TPD2E009DBZR | 296-24657-1-ND | 1 | 0.63 | 0.527 | TVS DIODE 5.5VWM 8VC SOT23-3
SJ-3523-SMT-TR | CP-3523SJCT-ND | 1 | 1.34 | 1.043 | CONN AUDIO JACK 3.5MM STEREO SMD

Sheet: ebay
 |  |  | Měna | USD
Item | Cena za 1 ks | Cena za 10 ks
Nokia 5110 LCD | 3 | 30
Tact switch | 2 | 2

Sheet: SUM
 |  | kč/€ | kč/USD
 | Kurz | 24.63 | 20
 |  | Cena pro 1 kus |  |  | Cena pro 10 kusů
 | kč | € | USD | kč | € | USD
GME
Farnell
Digikey
ebay
ALPS pot. | 40 |  |  | 400
PCB | 2000 |  |  | 10000
Case | 300 |  |  | 3000
SUMA

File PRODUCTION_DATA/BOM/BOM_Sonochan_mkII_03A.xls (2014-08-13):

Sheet: GME
Objednávka GME |  |  |  |  |  | * Cena bez DPH
Kód | GME Kód | Ks | Cena za 1 ks | Cena za 10 ks | Popis | Cena pro 1 ks | Cena pro 10 ks
Konektor XINYA MLW14A | 800-045 | 1 | 7.3339 | 7.3339 | Konektor pro ploché kabely do DPS 90°, rozteč 2,54mm, 2x7 kontaktů. | 7.3339 | 73.339
Oboustranný kolík XINYA S1G20 2,54mm | 832-017 | 1 | 4.0744 | 4.0774 | Oboustranný kolík přímý, 1 řady, rozteč 2,54mm, 20 pinů. | 4.0744 | 40.774
Oboustranný kolík XINYA S2G20 2,54mm | 832-023 | 1 | 4.44 | 4.44 | Oboustranný kolík přímý, 2 řady, rozteč 2,54mm, 2x10 pinů. | 4.44 | 44.4
Dutinková lišta XINYA BL25G | 832-074 | 1 | 13.0496 | 13.0496 | Dutinková lišta rovná, 1 řady, rozteč 2,54mm, 25 pinů. | 13.0496 | 130.496
GFA5 | 623-146 | 4 | 2.24 | 2.09 | přístr.nožička samolep. 7,9x2,2 Transparentní | 8.96 | 83.6
Distanční sloupek plastový M3 M/F KSS KDA6M3X10 W | 623-105 | 3 | 3.7025 | 3.3322 | Distanční sloupek, délka sloupku bez závitu 10mm, délka závitu 6mm, závit M3, na koncích šroub a závit | 11.1075 | 99.966
 |  |  |  |  |  | 0 | 0
 |  |  |  |  |  | 0 | 0
 |  |  |  |  |  | 0 | 0
 |  |  |  |  |  | 0 | 0
 |  |  |  |  |  | 0 | 0
 |  |  |  |  |  | 0 | 0
 |  |  |  |  |  | 0 | 0
 |  |  |  |  |  | 0 | 0
 |  |  |  |  |  | 0 | 0
 |  |  |  |  |  | 0 | 0
 |  |  |  |  |  | 0 | 0
 |  |  |  |  |  | 0 | 0
 |  |  |  |  |  | 0 | 0
 |  |  |  |  |  | 0 | 0
 |  |  |  |  |  | 0 | 0
 |  |  |  |  |  | 0 | 0
 |  |  |  |  |  | 0 | 0
 |  |  |  |  |  | 0 | 0
 |  |  |  |  |  | 0 | 0
Suma |  |  |  |  |  | 48.97 Kč | 472.58 Kč
Suma |  |  |  |  | 0.00 Kč

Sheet: Farnell
Farnell |  |  |  |  |  | * Cena bez DPH
Typové označení | Objednací kód | Ks | Cena za 1 kus | Cena za 10 ks | Popis | Cena pro 1 kus | Cena pro 10 ks
7201MD9AV2BE | 9575529 | 1 | 117.03 | 117.03 | C & K COMPONENTS - 7201MD9AV2BE - SWITCH, PCB, DPDT | 117.03 | 1170.3
2AS1T2A1M7RE | 9473165 | 1 | 68.15 | 68.15 | MULTICOMP - 2AS1T2A1M7RE - SWITCH, PCB, SPDT, HORIZ | 68.15 | 681.5
VOM617A-7X001T | 2251588 | 1 | 4.99 | 4.99 | VISHAY - VOM617A-7X001T - OPTOCOUPLER, TRANS., 80-160%, 5MA, VDE | 4.99 | 49.9
MCL039PURGW | 1581194 | 5 | 7.71 | 4.71 | MULTICOMP - MCL039PURGW - LED, 3MM, HI-RED/GRN, 30MCD/10MCD | 38.55 | 385.5
TLHY4401 | 2251300 | 1 | 3.48 | 3.48 | VISHAY - TLHY4401 - LED, 3MM, YELLOW, TINTED DIFFUSED | 3.48 | 34.8
MC20451 | 1249911 | 2 | 3.24 | 3.24 | MULTICOMP - MC20451 - LED, GREEN, T-1 3/4 (5MM), 20MCD, 565NM | 6.48 | 64.8
TLHK46Q1R2 | 2251295 | 1 | 3.79 | 3.79 | VISHAY - TLHK46Q1R2 - LED, 3MM, RED, TINTED DIFFUSED | 3.79 | 37.9
 |  |  |  |  |  | 0 | 0
 |  |  |  |  |  | 0 | 0
 |  |  |  |  |  | 0 | 0
 |  |  |  |  |  | 0 | 0
 |  |  |  |  |  | 0 | 0
 |  |  |  |  |  | 0 | 0
 |  |  |  |  |  | 0 | 0
 |  |  |  |  |  | 0 | 0
 |  |  |  |  |  | 0 | 0
 |  |  |  |  |  | 0 | 0
 |  |  |  |  |  | 0 | 0
 |  |  |  |  |  | 0 | 0
 |  |  |  |  |  | 0 | 0
Suma |  |  |  |  |  | 242.47 Kč | 2424.7

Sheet: Digikey
Digikey
Produkt | Part number | Počet ks. | Cena pro 1 ks | Cena pro 10 ks | Popis | Cena pro 1 ks | Cena pro 10 ks
LW Q38G-Q1S1-3K6L-1 | 475-2832-1-ND | 9 | 0.28 | 0.229 | LED CHIPLED WHT 8200K 0603 SMD | 2.52 | 20.61
RMCF0603ZT0R00 | RMCF0603ZT0R00CT-ND | 1 | 0.02 | 0.017 | RES 0.0 OHM 1/10W JUMP 0603 | 0.02 | 0.17
RMCF1206ZT0R00 | RMCF1206ZT0R00CT-ND | 2 | 0.05 | 0.034 | RES 0.0 OHM 1/4W JUMP 1206 | 0.1 | 0.68
C1S 1 | 507-1186-1-ND | 1 | 0.35 | 0.329 | FUSE 1A 63V 1206 SLOW C1S | 0.35 | 3.29
RMCF0603JT1M00 | RMCF0603JT1M00CT-ND | 1 | 0.02 | 0.017 | RES 1M OHM 1/10W 5% 0603 | 0.02 | 0.17
RMCF0603JT1K00 | RMCF0603JT1K00CT-ND | 1 | 0.02 | 0.017 | RES 1K OHM 1/10W 5% 0603 | 0.02 | 0.17
ECH-U1C102JX5 | PCF1471CT-ND | 1 | 0.61 | 0.513 | CAP FILM 1000PF 16VDC 0603 | 0.61 | 5.13
C0402C121J5GACTU | 399-7769-1-ND | 3 | 0.1 | 0.0216 | CAP CER 120PF 50V 5% NP0 0402 | 0.3 | 0.648
CL10F105ZP8NNNC | 1276-1041-1-ND | 30 | 0.0288 | 0.0152 | CAP CER 1UF 10V Y5V 0603 | 0.864 | 4.56
RMCF0402FT2K20 | RMCF0402FT2K20CT-ND | 1 | 0.04 | 0.025 | RES 2.2K OHM 1/16W 1% 0402 | 0.04 | 0.25
T491A475M010AT | 399-3698-1-ND | 4 | 0.34 | 0.294 | CAP TANT 4.7UF 10V 20% 1206 | 1.36 | 11.76
RMCF0603JT4K70 | RMCF0603JT4K70CT-ND | 2 | 0.02 | 0.017 | RES 4.7K OHM 1/10W 5% 0603 | 0.04 | 0.34
RMCF0402JT6K80 | RMCF0402JT6K80CT-ND | 1 | 0.02 | 0.017 | RES 6.8K OHM 1/16W 5% 0402 | 0.02 | 0.17
MCR03ERTF10R0 | RHM10.0CFCT-ND | 16 | 0.011 | 0.0047 | RES 10 OHM 1/10W 1% 0603 SMD | 0.176 | 0.752
RMCF0402JT10K0 | MCF0402JT10K0CT-ND | 6 | 0.02 | 0.0092 | RES 10K OHM 1/16W 5% 0402 | 0.12 | 0.552
RMCF0603JT10K0 | RMCF0603JT10K0CT-ND | 3 | 0.02 | 0.017 | RES 10K OHM 1/10W 5% 0603 | 0.06 | 0.51
CC0402KRX7R9BB102 | 311-1036-1-ND | 3 | 0.1 | 0.0088 | CAP CER 1000PF 50V 10% X7R 0402 | 0.3 | 0.264
C0603C102K5RACTU | 399-1082-1-ND | 3 | 0.1 | 0.0172 | CAP CER 1000PF 50V 10% X7R 0603 | 0.3 | 0.516
C0402C100J5GACTU | 399-1011-1-ND | 1 | 0.1 | 0.027 | CAP CER 10PF 50V 5% NP0 0402 | 0.1 | 0.27
9B-12.000MEEJ-B | 887-1238-ND | 1 | 0.48 | 0.4 | CRYSTAL 12MHZ 18PF THRU | 0.48 | 4
RMCF0603JT22R0 | RMCF0603JT22R0CT-ND | 1 | 0.02 | 0.017 | RES 22 OHM 1/10W 5% 0603 | 0.02 | 0.17
C1608C0G1H220J080AA | 445-1273-1-ND | 2 | 0.1 | 0.03 | CAP CER 22PF 50V 5% NP0 0603 | 0.2 | 0.6
RC0402JR-0733RL | 311-33JRCT-ND | 23 | 0.013 | 0.0053 | RES 33 OHM 1/16W 5% 0402 SMD | 0.299 | 1.219
RMCF0603FT33R0 | RMCF0603FT33R0CT-ND | 2 | 0.04 | 0.025 | RES 33 OHM 1/10W 1% 0603 | 0.08 | 0.5
MLZ2012M330WT000 | 445-6399-1-ND | 4 | 0.14 | 0.125 | INDUCTOR MULTILAYER 33UH 0805 | 0.56 | 5
RMCF0603JT39R0 | RMCF0603JT39R0CT-ND | 2 | 0.02 | 0.017 | RES 39 OHM 1/10W 5% 0603 | 0.04 | 0.34
RMCF0402JT47R0 | RMCF0402JT47R0CT-ND | 4 | 0.02 | 0.017 | RES 47 OHM 1/16W 5% 0402 | 0.08 | 0.68
RMCF0603JT47R0 | RMCF0603JT47R0CT-ND | 1 | 0.02 | 0.017 | RES 47 OHM 1/10W 5% 0603 | 0.02 | 0.17
RMCF0402FT47K0 | RMCF0402FT47K0CT-ND | 5 | 0.04 | 0.0138 | RES 47K OHM 1/16W 1% 0402 | 0.2 | 0.69
MCR03ERTJ473 | RHM47KCGCT-ND | 12 | 0.01 | 0.0042 | RES 47K OHM 1/10W 5% 0603 SMD | 0.12 | 0.504
RMCF0402JT100R | RMCF0402JT100RCT-ND | 2 | 0.02 | 0.017 | RES 100 OHM 1/16W 5% 0402 | 0.04 | 0.34
CL05A104MP5NNNC | 1276-1443-1-ND | 46 | 0.0084 | 0.00452 | CAP CER 0.1UF 10V 20% X5R 0402 | 0.3864 | 2.0792
RMCF0603JT220R | RMCF0603JT220RCT-ND | 1 | 0.02 | 0.017 | RES 220 OHM 1/10W 5% 0603 | 0.02 | 0.17
CL05F224ZO5NNNC | 1276-1060-1-ND | 2 | 0.1 | 0.041 | CAP CER 0.22UF 16V Y5V 0402 | 0.2 | 0.82
UUQ1E221MCL1GS | 493-3204-1-ND | 2 | 1.54 | 1.262 | CAP ALUM 220UF 25V 20% SMD | 3.08 | 25.24
RMCF0603JT270R | RMCF0603JT270RCT-ND | 6 | 0.02 | 0.0092 | RES 270 OHM 1/10W 5% 0603 | 0.12 | 0.552
RMCF0603FT330R | RMCF0603FT330RCT-ND | 6 | 0.04 | 0.025 | RES 330 OHM 1/10W 1% 0603 | 0.24 | 1.5
RMCF0603JT390R | RMCF0603JT390RCT-ND | 2 | 0.02 | 0.017 | RES 390 OHM 1/10W 5% 0603 | 0.04 | 0.34
RC0402JR-07470RL | 311-470JRCT-ND | 10 | 0.013 | 0.0053 | RES 470 OHM 1/16W 5% 0402 SMD | 0.13 | 0.53
AT32UC3A3256-ALUT | AT32UC3A3256-ALUT-ND | 1 | 16.5 | 15.002 | IC MCU 32BIT 256KB FLASH 144LQFP | 16.5 | 150.02
CS2200CP-CZZ | 598-1752-ND | 1 | 6.46 | 5.771 | IC CLK MULT FRACTIONAL N 10MSOP | 6.46 | 57.71
LD39300DT18-R | 497-6873-1-ND | 1 | 1.57 | 1.388 | IC REG LDO 1.8V 3A DPAK | 1.57 | 13.88
LF33ABDT-TR | 497-5225-1-ND | 2 | 0.95 | 0.83 | IC REG LDO 3.3V 0.5A DPAK | 1.9 | 16.6
LTV-816S | 160-1361-5-ND | 1 | 0.39 | 0.278 | OPTOISOLATR 5KV TRANSISTOR 4-SMD | 0.39 | 2.78
690-005-299-043 | 151-1206-1-ND | 1 | 0.41 | 0.385 | CONN MINI USB RCPT RA TYPE B SMD | 0.41 | 3.85
SI8642BA-B-IU | 336-2091-5-ND | 6 | 2.41 | 2.3168 | IC ISOLATOR 4CH 1KV 16QSOP | 14.46 | 139.008
SI8645BA-B-IU | 336-2096-5-ND | 2 | 2.41 | 2.41 | IC ISOLATOR 4CH 1KV 16QSOP | 4.82 | 48.2
TLV320AIC33IRGZR | 296-19789-1-ND | 1 | 8.01 | 7.204 | IC STEREO AUDIO CODEC 48-VQFN | 8.01 | 72.04
TPD2E009DBZR | 296-24657-1-ND | 1 | 0.63 | 0.527 | TVS DIODE 5.5VWM 8VC SOT23-3 | 0.63 | 5.27
SJ-3523-SMT-TR | CP-3523SJCT-ND | 1 | 1.34 | 1.043 | CONN AUDIO JACK 3.5MM STEREO SMD | 1.34 | 10.43
 |  |  |  |  |  | 0 | 0
 |  |  |  |  |  | 0 | 0
 |  |  |  |  |  | 0 | 0
 |  |  |  |  |  | 0 | 0
 |  |  |  |  |  | 0 | 0
 |  |  |  |  |  | 0 | 0
 |  |  |  |  |  | 0 | 0
 |  |  |  |  |  | 0 | 0
 |  |  |  |  |  | 70.1654 | 616.0442

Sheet: ebay
 |  |  | Měna | USD
Item | Cena za 1 ks | Cena za 10 ks
Nokia 5110 LCD | 3 | 30
Tact switch | 2 | 2
 | 5 | 5

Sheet: SUM
 |  | kč/€ | kč/USD
 | Kurz | 24.63 | 20
 |  | Cena pro 1 kus |  |  | Cena pro 10 kusů
 | kč | € | USD | kč | € | USD
GME | 48.97 | 1.99 | 2.45 | 472.58 | 19.19 | 23.63
Farnell | 242.47 | 9.84 | 12.12 | 2424.70 | 98.44 | 121.23
Digikey | 1403.31 | 56.98 | 70.17 | 12320.88 | 500.24 | 616.04
ebay | 100.00 | 4.06 | 5.00 | 100.00 | 4.06 | 5.00
ALPS pot. | 40.00 | 1.62 | 2.00 | 400.00 | 16.24 | 20.00
PCB | 2000.00 | 81.20 | 100.00 | 10000.00 | 406.01 | 500.00
Case | 300.00 | 12.18 | 15.00 | 3000.00 | 121.80 | 150.00
SUMA | 4134.74 | 167.87 | 206.74 | 28718.16 | 1165.98 | 1435.91

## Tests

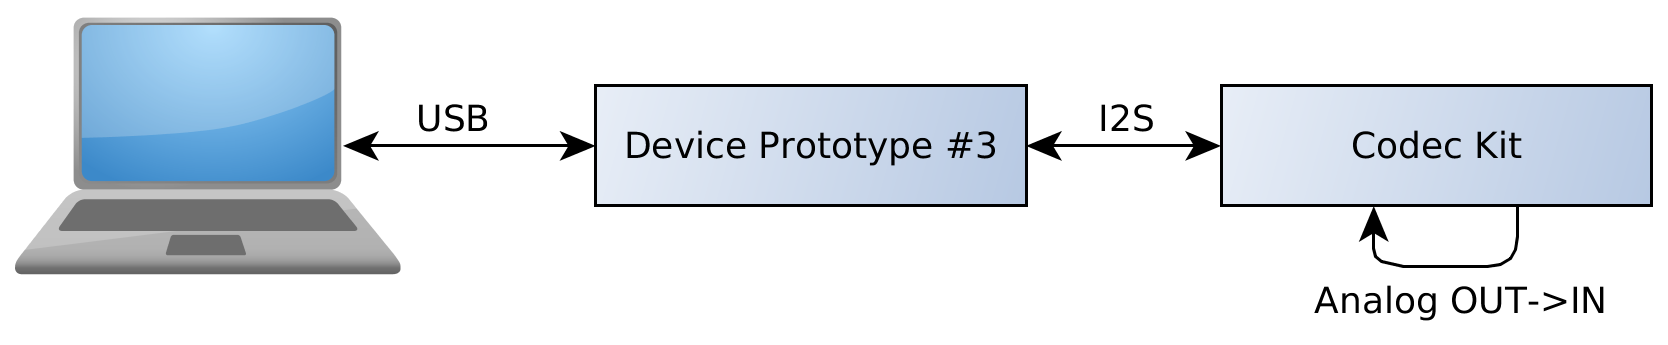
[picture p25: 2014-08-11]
DOC/thesis/thesis_doc_files/measure_codec_kit.png

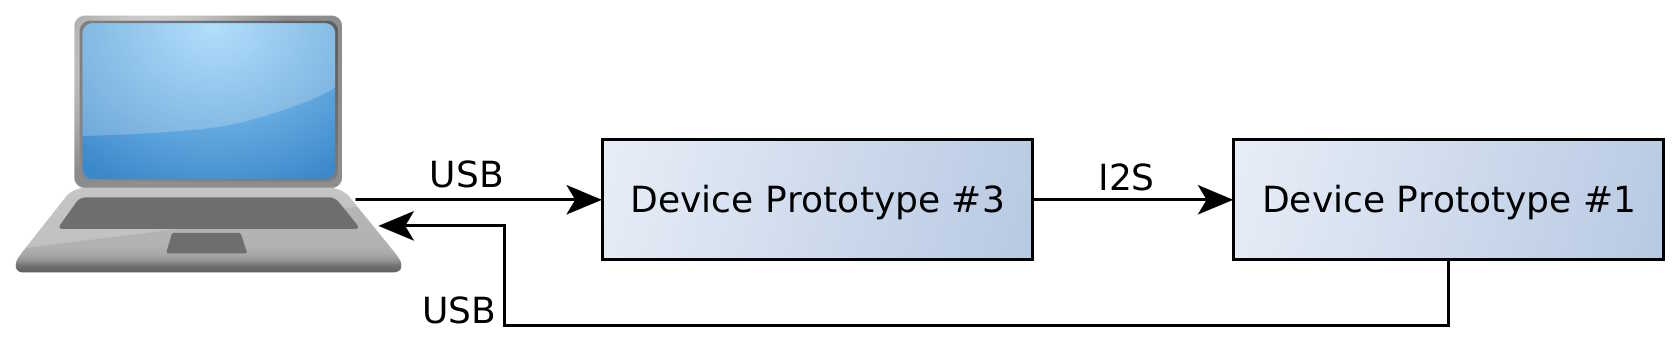
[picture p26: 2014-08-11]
DOC/thesis/thesis_doc_files/measure_sonochan_sonochan.jpg

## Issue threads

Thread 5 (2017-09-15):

Left and right channel is swapped

MartinStej, 2017-09-15:
Sometimes happens, that left and right channel gets swapped.

Possible root of problems:
 * desynchronization on PDCA due to clock/sample blackouts
 * desynchronization when handling incoming USB data
 * desynchronization on SSC module
 * desynchronization somewhere else in code

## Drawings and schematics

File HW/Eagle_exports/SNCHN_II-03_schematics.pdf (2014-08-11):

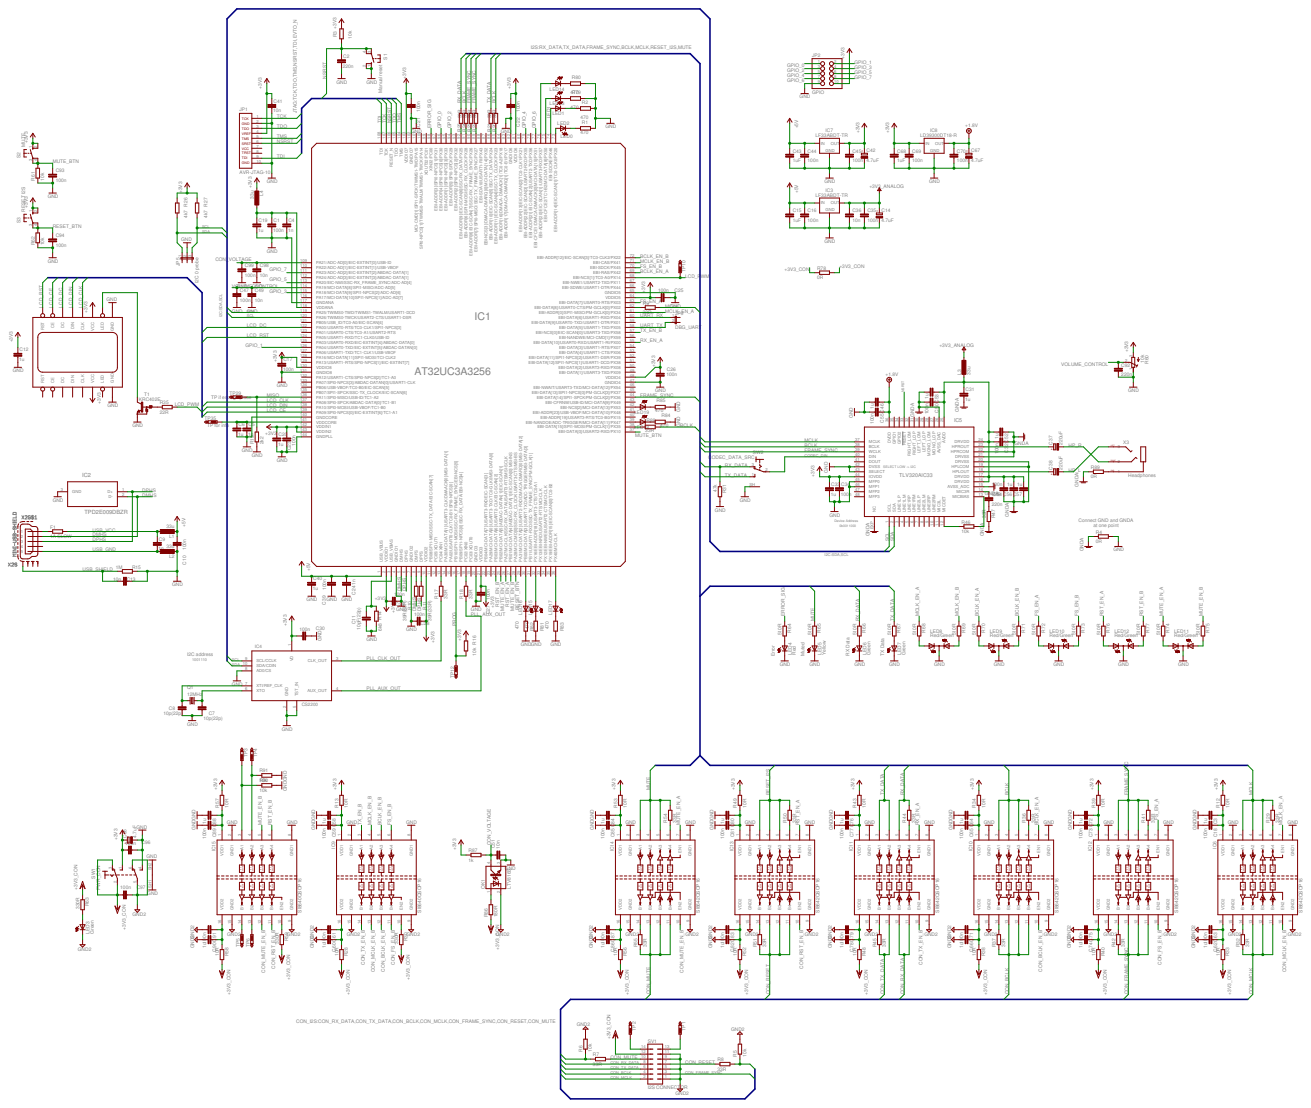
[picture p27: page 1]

JTAG:TCK,TDO,TMS,NSRST,TDI,EVTO_N

100 MCI-CMD[1]/SPI1-SPCK/TWIMS1-TWD/PA15

92 EBI-ADDR[8]/EIC-SCAN[7]/SSC-RX_FRAME_SYNC/PX26

EBI-ADDR[9]/EIC-SCAN[6]/SSC-RX_DATA/PX25

89 EBI-ADDR[6]/SPI0-MOSI/SSC-RX_CLOCK/PX28

90 EBI-ADDR[7]/SPI0-MISO/SSC-TX_FRAME_SYNC/PX27

EBI-NCS[3]/DMACA-DMARQ[0]/MCI-DATA[14]/PX52

85 EBI-ADDR[10]/EIC-SCAN[5]/SSC-TX_DATA/PX24

72 EBI-ADDR[11]/EIC-SCAN[4]/SSC-TX_CLOCK/PX23

83 EBI-ADDR[16]/DMACA-DMAACK[1]/TC0-A2/PX18

EBI-ADDR[17]/DMACA-DMARQ[1]/TC0-B1/PX17

80 EBI-ADDR[12]/EIC-SCAN[3]/TC0-CLK2/PX22

EBI-ADDR[13]/EIC-SCAN[2]/TC0-CLK1/PX21

79 EBI-ADDR[21]/EIC-SCAN[2]/USART2-TXD/PX56

EBI-ADDR[22]/EIC-SCAN[3]/USART2-RXD/PX55

78 EBI-ADDR[20]/EIC-SCAN[1]/USART3-RXD/PX57

75 EBI-CFCE1/DMACA-DMAACK[0]/MCI-DATA[15]/PX51

76 EBI-NCS[0]/EIC-SCAN[0]/USART3-TXD/PX58

35 EBI-ADDR[14]/EIC-SCAN[1]/TC0-CLK0/PX20

55 EBI-DATA[9]/USART0-TXD/USART1-DTR/PX01

59 EBI-DATA[8]/USART0-CTS/PM-GCLK[0]/PX02
EBI-ADDR[0]/SPI1-MISO/PM-GCLK[0]/PX34

58 EBI-DATA[4]/USART1-CTS/PX06
57 EBI-NANDWE/MCI-CMD[1]/PX59

EBI-DATA[10]/USART0-RXD/USART1-RI/PX00

PA16/MCI-DATA[11]/SPI1-MOSI/TCI-CLK2

51 EBI-DATA[11]/SPI1-NPCS[2]/USART1-DSR/PX39
EBI-DATA[12]/SPI1-NPCS[1]/USART1-DCD/PX38

TP if enough place

42 EBI-NWAIT/USART3-TXD/MCI-DATA[12]/PX54
44 EBI-DATA[13]/SPI1-NPCS[0]/PM-GCLK[3]/PX37
EBI-DATA[14]/SPI1-SPCK/PM-GCLK[2]/PX36
41 EBI-CFRNW/USB-ID/MCI-DATA[9]/PX49

39 EBI-ADDR[23]/USB-VBOF/MCI-DATA[10]/PX48
EBI-ADDR[19]/USART3-RTS/TC0-B0/PX15

EBI-NCS[2]/MCI-DATA[13]/PX53

PA31/MCI-DATA[2]/USART2-RXD/DMACA-DMARO[0]/MSI-DATA[2] 29 PB00/MCI-DATA[3]/USART-TXD/ADC-TRIGGER/MSI-DATA[3] 30 PB01/MCI-DATA[4]/ABDAC-DATA[1]/EIC-SCAN[0]/MSI-INS

EBI-NANDOE/ADC-TRIGGER/MCI-DATA[11]/PX47
EBI-DATA[15]/SPI1-MOSI/PM-GCLK[1]/PX35

PA30/MCI-DATA[1]/USART3-CLK/DMAACK[0]/MSI-DATA[1] 14

28 PA29/MCI-DATA[0]/USART3-TXD/TC0-GLK0/MSI-DATA[0] 23

26 PA28/MCI-CMD[0]/SSC-RX_CLOCK/USART3-CTS/MSI-BS

PA27/MCI-CLK/SSC-RX_DATA/USART3-RTS/MSI-SCLK

PB11/USART1-RXD/SSC-TX_FRAME_SYNC/PM-GCLK[1] 31

PB08/SPI1-MISO/SSC-TX_DATA/EIC-SCAN[7] 11 PB09/SPI1-NPCS[0]/SSC-RX_DATA/EBI-NCS[4] 17 PB10/SPI1-MOSI/SSC-RX_FRAME_SYNC/EBI-NCS[5] 16

27 PB02/MCI-DATA[5]/ABDAC-DATAN[1]/EIC-SCAN[1] 25 PB03/MCI-DATA[6]/USART2-CLK/EIC-SCAN[2] 24 PB04/MCI-DATA[7]/USART3-RXD/EIC-SCAN[3] 22

34 PX13/EBI-NRD/USART2-RTS/MCI-CLK

PX12/EBI-NWE0/USART2-CTS/MCI-CLK

PX19/EBI-ADDR[15]/EIC-SCAN[0]/TC0-B2

Connect GND and GNDA
at one point

RX Data TX Data

1u 100n GND GND GND GND

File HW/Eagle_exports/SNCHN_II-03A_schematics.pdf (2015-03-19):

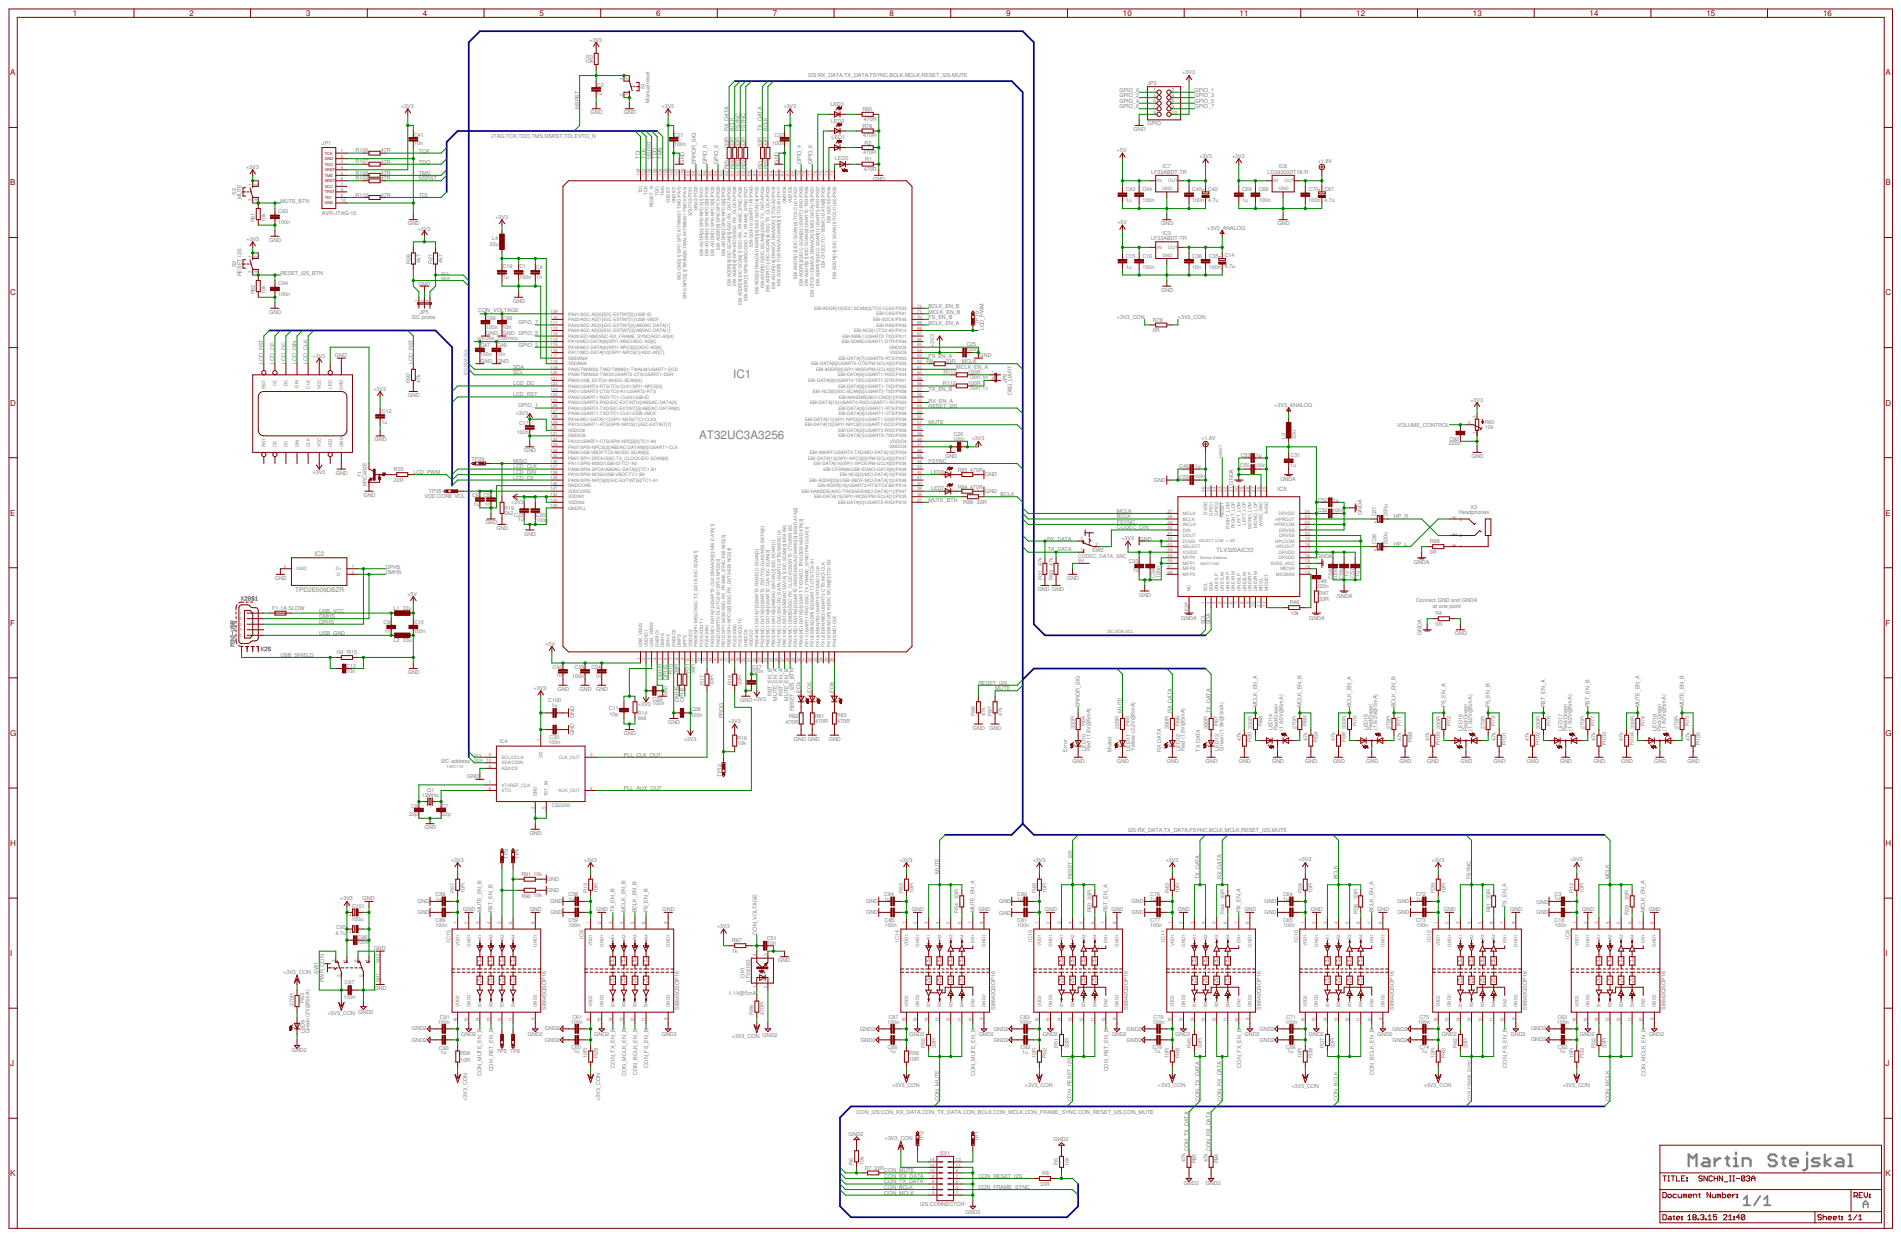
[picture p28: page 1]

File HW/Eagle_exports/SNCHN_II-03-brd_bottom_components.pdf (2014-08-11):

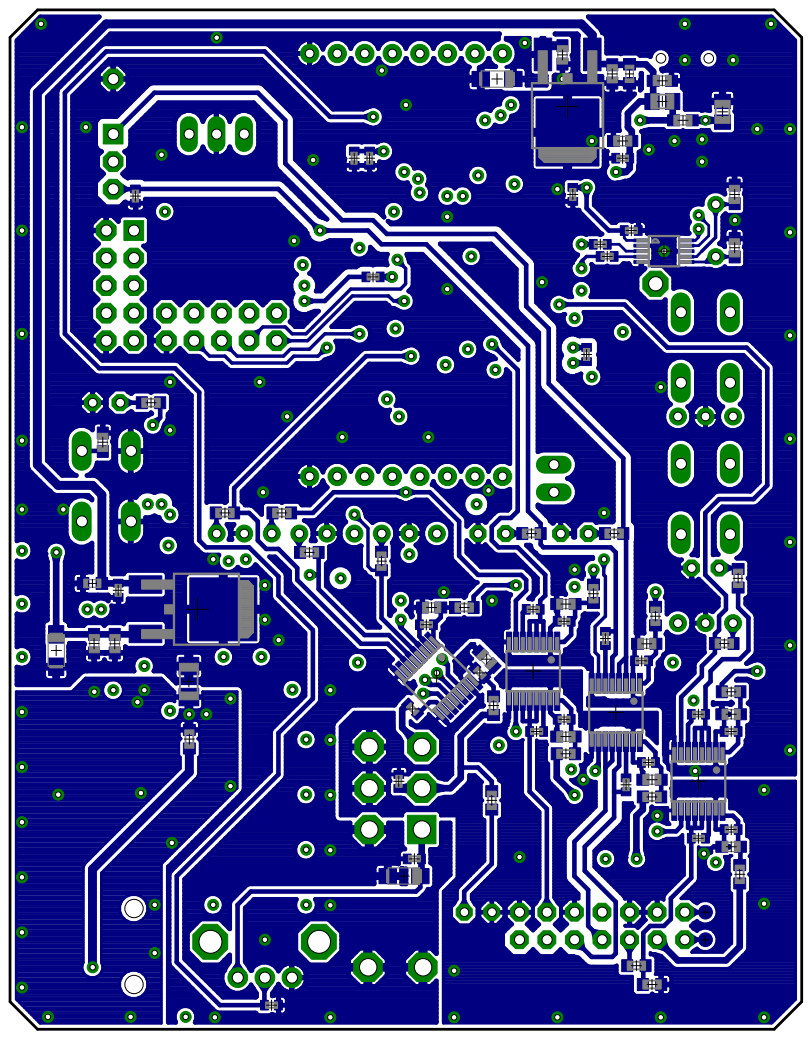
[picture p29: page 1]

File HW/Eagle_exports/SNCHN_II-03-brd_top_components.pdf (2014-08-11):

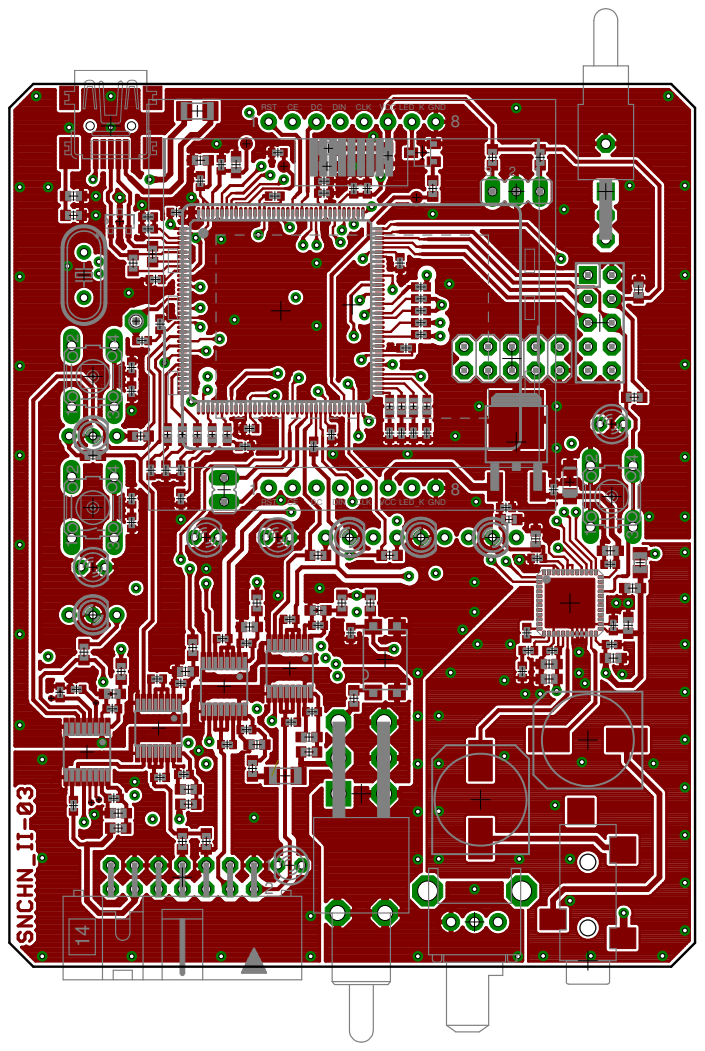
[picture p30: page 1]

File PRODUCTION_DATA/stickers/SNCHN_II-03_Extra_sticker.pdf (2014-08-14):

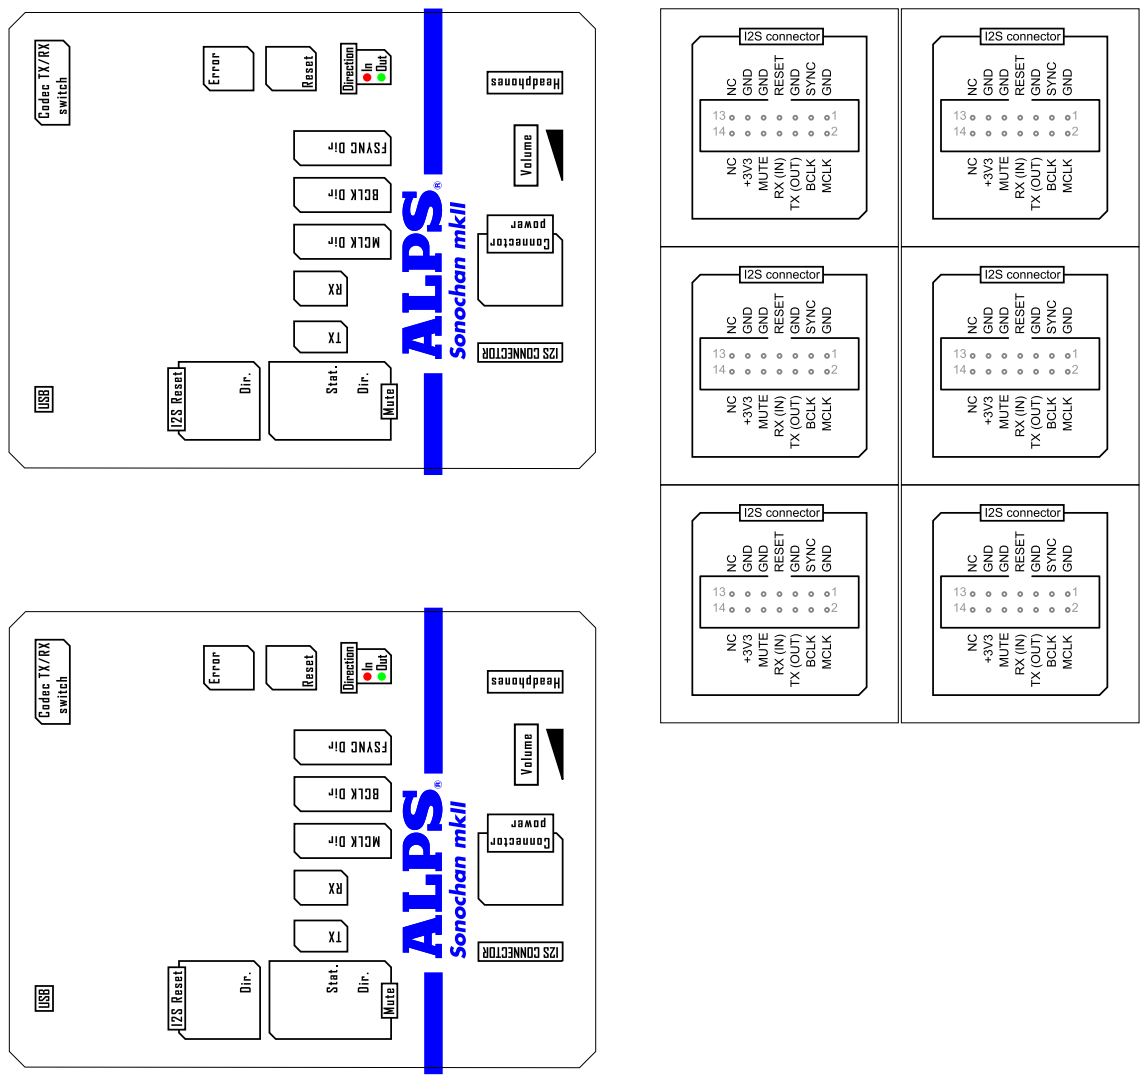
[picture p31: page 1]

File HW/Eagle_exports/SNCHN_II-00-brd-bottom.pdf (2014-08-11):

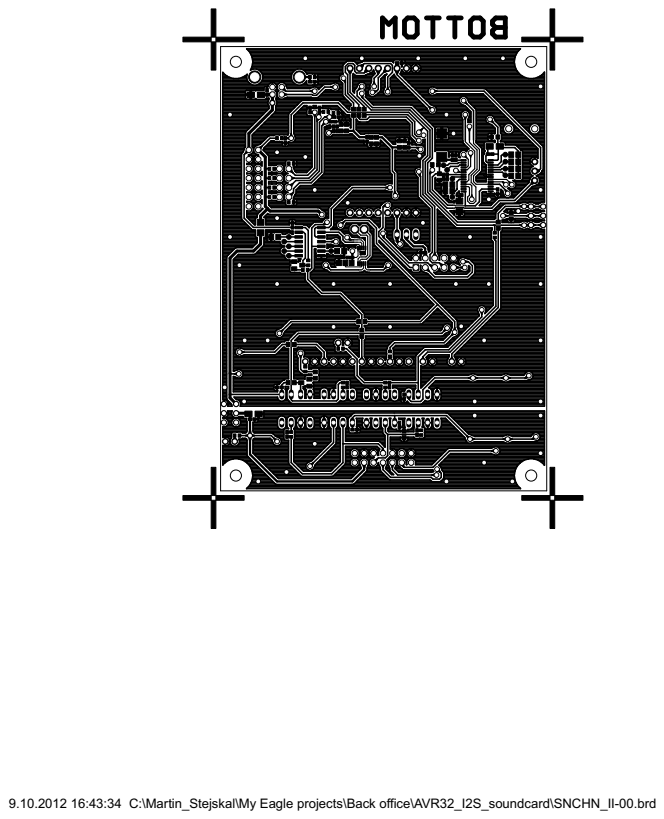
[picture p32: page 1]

9.10.2012 16:43:34 C:\Martin_Stejskal\My Eagle projects\Back office\AVR32_I2S_soundcard\SNCHN_II-00.brd

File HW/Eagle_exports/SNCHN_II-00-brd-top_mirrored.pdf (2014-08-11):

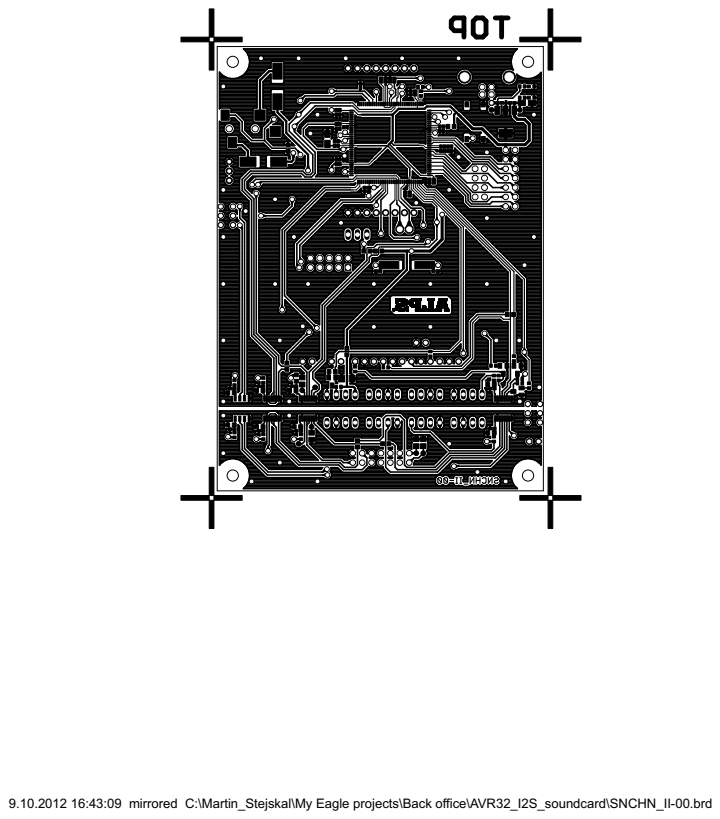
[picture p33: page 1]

9.10.2012 16:43:09 mirrored C:\Martin_Stejskal\My Eagle projects\Back office\AVR32_I2S_soundcard\SNCHN_II-00.brd

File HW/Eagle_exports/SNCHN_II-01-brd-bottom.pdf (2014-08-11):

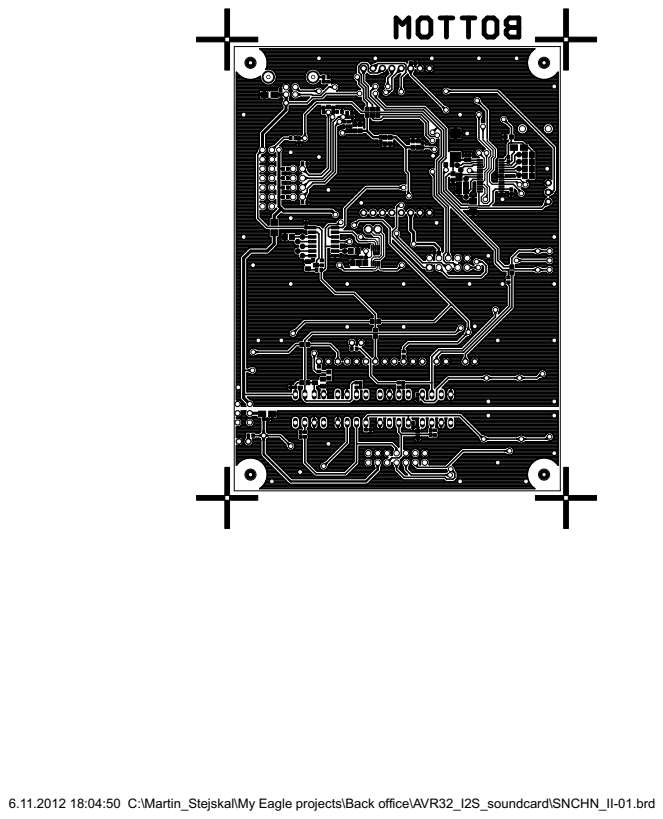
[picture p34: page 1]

6.11.2012 18:04:50 C:\Martin_Stejskal\My Eagle projects\Back office\AVR32_I2S_soundcard\SNCHN_II-01.brd

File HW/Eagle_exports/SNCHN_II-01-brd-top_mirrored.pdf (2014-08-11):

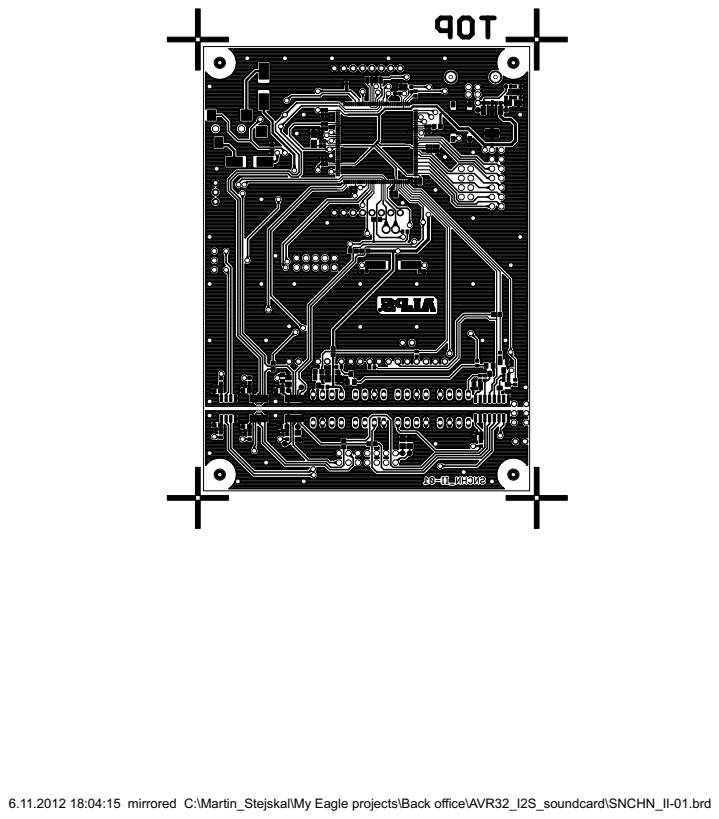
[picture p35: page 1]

6.11.2012 18:04:15 mirrored C:\Martin_Stejskal\My Eagle projects\Back office\AVR32_I2S_soundcard\SNCHN_II-01.brd

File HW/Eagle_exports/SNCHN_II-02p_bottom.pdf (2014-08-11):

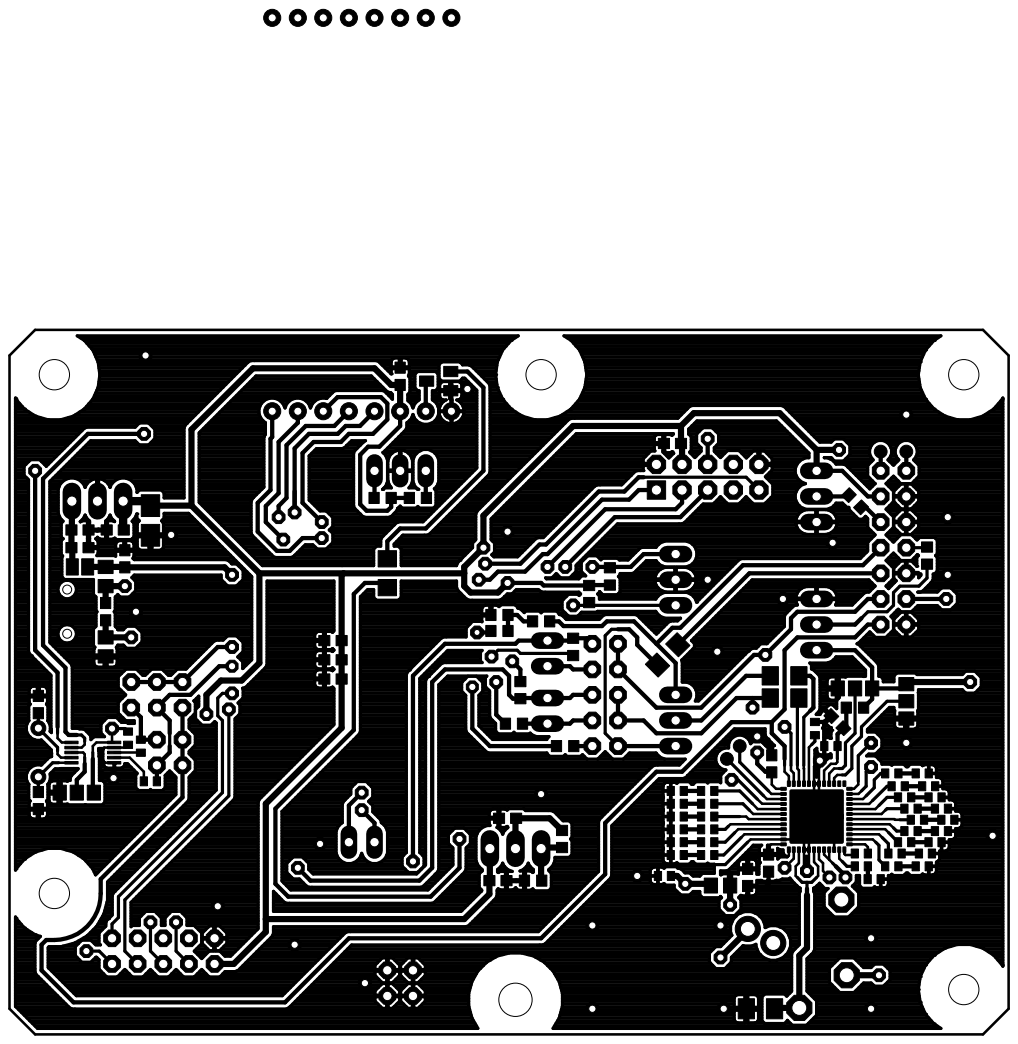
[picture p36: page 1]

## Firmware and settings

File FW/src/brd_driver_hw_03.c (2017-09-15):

/*
Sonochan Mk.II Firmware.
Copyright (C) 2013-2015 Martin Stejskal,
ALPS Electric Czech, s.r.o.,
ALPS Electric Co., Ltd.

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
Contact information:
Martin Stejskal <martin.stejskal@jp.alps.com>,
Josef Nevrly <jnevrly@alps.cz>
ALPS Electric Czech, s.r.o., Sebranice 240, 679 31 Sebranice u Boskovic
Czech Republic
*/
/**
 * \file
 *
 * \brief Board driver for "Sonochan mkII" HW version 03
 *
 * Allow set basic settings on board. Also support "generic driver".
 * Written only for AVR32 UC3A3.
 *
 * Created:  2014/04/23\n
 * Modified: 2017/09/15
 *
 * \version 0.7
 * \author  Martin Stejskal
 */

#include "brd_driver_hw_03.h"
//============================| Global variables |=============================
/**
 * \brief Mute structure
 *
 * Contains mute direction and mute value
 */
static s_brd_drv_mute_dai_t s_brd_drv_mute;

/**
 * \brief Reset DAI structure
 *
 * Contains reset DAI direction and value
 */
static s_brd_drv_rst_dai_t s_brd_drv_rst_i2s;

/**
 * \brief Store directions for MCLK, BCLK, FSYNC, TX_DATA, RX_DATA
 */
static s_brd_drv_pure_dai_dir_t s_brd_drv_pure_dai_dir;

static s_brd_drv_FSYNC_freq_req_t s_brd_drv_FSYNC_freq_req;

/**
 * \brief Store fine settings of SSC module
 */
static s_brd_drv_ssc_fine_setting_t s_brd_drv_ssc_fine_settings;

/**
 * \brief Store auto tune PLL value
 */
static uint8_t i_auto_tune_pll;

/**
 * \brief Copied value from USB descriptors. Number added behind device name
 *
 * This value should be copied, else optimizer set it as constant and this is\n
 * something that we do not want.
 */
static uint8_t i_product_name_number;

//===========================| "EEPROM" variables |============================
// Set up NVRAM (EEPROM) storage
#if defined (__GNUC__)
__attribute__((__section__(".userpage")))
#endif
/**
 * \brief Structure for saving and restoring settings
 */
static s_brd_drv_user_settings_t s_brd_drv_user_settings;

/**
 * \brief Variable that allow detect correct or incorrect settings in user\n
 * flash
 */
#if defined (__GNUC__)
__attribute__((__section__(".userpage")))
#endif
static uint8_t i_brd_drv_settings_check;

//=========================| Generic driver support |==========================
#if BRD_DRV_SUPPORT_GENERIC_DRIVER == 1
/**
 * \brief Configure table for device
 */

// Do not test architecture. This is mainly for AVR32.
const gd_config_struct BRD_DRV_config_table[] =
  {
    {
#define BRD_DRV_CMD_INIT        0
      BRD_DRV_CMD_INIT,                         // Command ID
      "Initialize board hardware",              // Name
      "Initialize I/O and prepare codec",       // Descriptor
      void_type,              // Input data type
      {.data_uint32 = 0},     // Minimum input value
      {.data_uint32 = 0},     // Maximum input value
      void_type,              // Output data type
      {.data_uint32 = 0},     // Minimum output value
      {.data_uint32 = 0},     // Maximum output value
      (GD_DATA_VALUE*)&gd_void_value, // Output value
      brd_drv_init                    /* Function, that should be
                                       * called
                                       */
    },
    {
#define BRD_DRV_CMD_RESET_CON   BRD_DRV_CMD_INIT+1
      BRD_DRV_CMD_RESET_CON,
      "Reset connector I/O's",
      "Set all signals to Hi-Z. Codec on board will work.",
      void_type,
      {.data_uint32 = 0},
      {.data_uint32 = 0},
      void_type,
      {.data_uint32 = 0},
      {.data_uint32 = 0},
      (GD_DATA_VALUE*)&gd_void_value,
      brd_drv_reset_i2s
    },
    {
#define BRD_DRV_CMD_MCLK_DIR    BRD_DRV_CMD_RESET_CON+1
      BRD_DRV_CMD_MCLK_DIR,
      "MCLK direction",
      "0 - input ; 1 - output ; 2 - Hi-Z",
      uint32_type,      // Cause it is enum and 32 bit system
      {.data_uint32 = 0},
      {.data_uint32 = 2},
      uint32_type,
      {.data_uint32 = 0},
      {.data_uint32 = 2},
      (GD_DATA_VALUE*)&s_brd_drv_pure_dai_dir.e_mclk_dir,
      brd_drv_set_mclk_dir
    },
    {
#define BRD_DRV_CMD_BCLK_DIR    BRD_DRV_CMD_MCLK_DIR+1
      BRD_DRV_CMD_BCLK_DIR,
      "BCLK role and direction",
      "0 - slave, BCLK is input ; 1 - master, BCLK output ; 2 - Hi-z",
      uint32_type,      // Cause it is enum and 32 bit system
      {.data_uint32 = 0},
      {.data_uint32 = 2},
      uint32_type,
      {.data_uint32 = 0},
      {.data_uint32 = 2},
      (GD_DATA_VALUE*)&s_brd_drv_pure_dai_dir.e_bclk_dir,
      brd_drv_set_bclk_dir
    },
    {
#define BRD_DRV_CMD_FSYNC_DIR   BRD_DRV_CMD_BCLK_DIR+1
      BRD_DRV_CMD_FSYNC_DIR,
      "FSYNC role and direction",
      "0-slave, FSYNC (word clock) is input; 1-master, FSYNC is output; 2-hi-z",
      uint32_type,      // Cause it is enum and 32 bit system
      {.data_uint32 = 0},
      {.data_uint32 = 2},
      uint32_type,
      {.data_uint32 = 0},
      {.data_uint32 = 2},
      (GD_DATA_VALUE*)&s_brd_drv_pure_dai_dir.e_fsync_dir,
      brd_drv_set_fsync_dir
    },
    {
#define BRD_DRV_CMD_MUTE_DIR    BRD_DRV_CMD_FSYNC_DIR+1
      BRD_DRV_CMD_MUTE_DIR,
      "MUTE direction",
      "0 - input ; 1 - output ; 2 - Hi-Z",
      uint32_type,      // Cause it is enum and 32 bit system
      {.data_uint32 = 0},
      {.data_uint32 = 2},
      uint32_type,
      {.data_uint32 = 0},
      {.data_uint32 = 2},
      (GD_DATA_VALUE*)&s_brd_drv_mute.e_mute_dir,
      brd_drv_set_mute_dir
    },
    {
#define BRD_DRV_CMD_MUTE_FLAG   BRD_DRV_CMD_MUTE_DIR+1
      BRD_DRV_CMD_MUTE_FLAG,
      "Set mute flag",
      "0 - mute off ; 1 - mute on",
      uint8_type,
      {.data_uint8 = 0},
      {.data_uint8 = 1},
      uint8_type,
      {.data_uint8 = 0},
      {.data_uint8 = 1},
      (GD_DATA_VALUE*)&s_brd_drv_mute.i_mute_val,
      brd_drv_set_mute
    },
    {
#define BRD_DRV_CMD_RESET_DIR   BRD_DRV_CMD_MUTE_FLAG+1
      BRD_DRV_CMD_RESET_DIR,
      "Set RESET_I2S direction",
      "0 - input ; 1 - output ; 2 - Hi-Z",
      uint32_type,      // Cause it is enum and 32 bit system
      {.data_uint32 = 0},
      {.data_uint32 = 2},
      uint32_type,
      {.data_uint32 = 0},
      {.data_uint32 = 2},
      (GD_DATA_VALUE*)&s_brd_drv_rst_i2s.e_rst_dai_dir,
      brd_drv_set_rst_dai_dir
    },
    {
#define BRD_DRV_CMD_RESET_FLAG  BRD_DRV_CMD_RESET_DIR+1
      BRD_DRV_CMD_RESET_FLAG,
      "Set reset I2S flag",
      "0 - off ; 1 - on",
      uint8_type,
      {.data_uint8 = 0},
      {.data_uint8 = 1},
      uint8_type,
      {.data_uint8 = 0},
      {.data_uint8 = 1},
      (GD_DATA_VALUE*)&s_brd_drv_rst_i2s.i_rst_dai_val,
      brd_drv_set_rst_dai
    },
    {
#define BRD_DRV_CMD_TX_DATA_DIR BRD_DRV_CMD_RESET_FLAG+1
      BRD_DRV_CMD_TX_DATA_DIR,
      "Set TX_DATA direction",
      "1 - output ; 2 - HiZ",
      uint32_type,      // Cause it is enum and 32 bit system
      {.data_uint32 = 1},
      {.data_uint32 = 2},
      uint32_type,
      {.data_uint32 = 1},
      {.data_uint32 = 2},
      (GD_DATA_VALUE*)&s_brd_drv_pure_dai_dir.e_tx_data_dir,
      brd_drv_set_tx_data_dir
    },
    {
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

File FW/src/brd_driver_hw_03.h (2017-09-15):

/*
Sonochan Mk.II Firmware.
Copyright (C) 2013-2015 Martin Stejskal,
ALPS Electric Czech, s.r.o.,
ALPS Electric Co., Ltd.

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
Contact information:
Martin Stejskal <martin.stejskal@jp.alps.com>,
Josef Nevrly <jnevrly@alps.cz>
ALPS Electric Czech, s.r.o., Sebranice 240, 679 31 Sebranice u Boskovic
Czech Republic
*/
/**
 * \file
 *
 * \brief Board driver for "Sonochan mkII" HW version 03
 *
 * Allow set basic settings on board. Also support "generic driver".
 * Written only for AVR32 UC3A3.
 *
 * Created:  2014/04/23\n
 * Modified: 2017/09/15
 *
 * \version 0.7
 * \author  Martin Stejskal
 */

#ifndef _BRD_DRIVER_H_
#define _BRD_DRIVER_H_

//=================================| Options |=================================

/**
 * @brief Enable debug mode.
 *
 * In this mode non-standard settings can be used. This may decrease develop\n
 * time, but may confuse user. Beware!
 */
#define BRD_DRV_DEBUG                                   0
/**
 * \brief Set default headphones volume in dB
 *
 * Recommended value is about -40, but it is up to you if you want destroy \n
 * your ears or headphones...
 */
#define BRD_DRV_DEFAULT_HEADPHONES_VOLUME_IN_DB         -45

/**
 * \brief Option for generic driver support
 *
 * Options: 0 (support disabled) or 1 (support enabled)
 */
#define BRD_DRV_SUPPORT_GENERIC_DRIVER          1


/**
 * \brief Option for FreeRTOS support
 *
 * Options: 0 (support disabled) or 1 (support enabled)
 */
#define BRD_DRV_SUPPORT_RTOS                    1


/**
 * \name Digital audio interface - default parameters
 *
 * @{
 */

/**
 * @brief Default Digital Audio Interface mode
 *
 * Options: SSC_I2S/SSC_DSP/SSC_LEFT_JUSTIFIED/SSC_RIGHT_JUSTIFIED
 */
#define BRD_DRV_DEFAULT_DAI_MODE                SSC_I2S

/**
 * \brief Default MCLK oversampling relative to FSYNC singal
 */
#define BRD_DRV_DEFAULT_MCLK_OVERSAMPLING       256

/**
 * \brief Default BCLK oversampling relative to FSYNC singal
 */
#define BRD_DRV_DEFAULT_BCLK_OVERSAMPLING       64

/**
 * @brief Default data word length
 */
#define BRD_DRV_DEFAULT_DATA_WORD_LENGTH        24

/**
 * \brief This is only for reference.
 *
 * After connection audio driver change frequency anyway. This is only \n
 * "start up" value
 */
#define BRD_DRV_DEFAULT_FSYNC_FREQ              48000UL

/**
 * @brief By default, enable auto tune?
 *
 * 0 - Auto tune disabled (MCLK Fix) ; 1 - Auto tune enabled
 */
#define BRD_DRV_DEFAULT_AUTO_TUNE               1
/// @}


/**
 * @name Digital audio interface - default signal direction settings
 *
 * Options: brd_drv_dir_out, brd_drv_dir_in and brd_drv_dir_hiz
 *
 * @{
 */

#define BRD_DRV_DEFAULT_MUTE_DIR                brd_drv_dir_hiz
#define BRD_DRV_DEFAULT_RESET_DAI_DIR           brd_drv_dir_hiz
#define BRD_DRV_DEFAULT_MCLK_DIR                brd_drv_dir_hiz
#define BRD_DRV_DEFAULT_BCLK_DIR                brd_drv_dir_hiz
#define BRD_DRV_DEFAULT_FSYNC_DIR               brd_drv_dir_hiz
#define BRD_DRV_DEFAULT_DATA_TX_DIR             brd_drv_dir_hiz
#define BRD_DRV_DEFAULT_DATA_RX_DIR             brd_drv_dir_hiz
/// @}

/**
 * \brief Option allow create ADCmutex when brd_drv_init() is called
 *
 * Mutexes is needed when in RTOS two functions share same hardware. This\n
 * option allow create mutex mutexADC, so any other functions just can use\n
 * xSemaphoreTake and xSemaphoreGive functions.\n
 * Options: 0 (disabled) or 1 (enabled).\n
 *
 * \note This option is valid only if RTOS support is enabled.
 */
#define BRD_DRV_RTOS_CREATE_MUTEX               1



/**
 * \brief Address to memory where are ADC registers
 *
 * Example: AVR32_ADC_ADDRESS or (&AVR32_ADC) - it is the same
 */
#define BDR_DRV_ADC_ADDRESS                     AVR32_ADC_ADDRESS


/**
 * \brief Address to memory where are PM registers
 *
 * Example: AVR32_PM_ADDRESS or (&AVR32_PM) - it is the same
 */
#define BRD_DRV_PM_ADDRESS                      AVR32_PM_ADDRESS

/**
 * \brief Clock speed for ADC module in Hz
 *
 * User should define at least approximately speed of clock on which is ADC\n
 * module connected. This value is used to calculate correct values in\n
 * registers. After reset, MCU use slow oscillator, which in case UC3A3256\n
 * runs at 115 kHz. If your clock source is variable, then is recommended\n
 * set this constant to maximum used frequency.\n
 * Example:\n
 * \code
 * #define BRD_DRV_ADC_CLK_SOURCE 115000UL
 * \endcode
 */
#define BRD_DRV_ADC_CLK_SOURCE     33000000UL



/**
 * \brief Wanted clock speed for ADC module in Hz
 *
 * Because ADC module have own prescaller, it is possible set lower frequency\n
 * for ADC and other components can run on high speed bus. Also for 10 bit\n
 * resolution prescalled CLK should not exceed 5 MHz and for 8 bit resolution\n
 * should not exceed 8 MHz.\n
 * If you unsure, just set this value to 0 and preprocessor do the rest.\n
 * Example:\n
 * \code
 * #define BRD_DRV_ADC_PRESCALLED_CLK 0UL
 * \endcode
 */
#define BRD_DRV_ADC_PRESCALLED_CLK      0UL



/**
 * \name ADC pin mapping for board
 * @{
 */
///\brief ADC volume signal pin
#define BRD_DRV_ADC_VOLUME_CONTROL_PIN          AVR32_ADC_AD_5_PIN

///\brief ADC volume signal pin function
#define BRD_DRV_ADC_VOLUME_CONTROL_FUNCTION     AVR32_ADC_AD_5_FUNCTION

///\brief Used ADC channel by volume signal
#define BRD_DRV_ADC_VOLUME_CONTROL_CHANNEL      5

///\brief ADC con voltage signal pin
#define BRD_DRV_ADC_CON_VOLTAGE_PIN             AVR32_ADC_AD_0_PIN

///\brief ADC con voltage signal pin function
#define BRD_DRV_ADC_CON_VOLTAGE_FUNCTION        AVR32_ADC_AD_0_FUNCTION

///\brief Used ADC channel by con voltage signal
#define BRD_DRV_ADC_CON_VOLTAGE_CHANNEL         0
/// @}



/**
 * \name Other pin mapping for Sonochan mkII boards
 * @{
 */
///\brief Mute enable on MCU side
#define BRD_DRV_MUTE_EN_A_PIN                   AVR32_PIN_PB02

///\brief Reset enable on MCU side
#define BRD_DRV_RST_EN_A_PIN                    AVR32_PIN_PA27

///\brief Bit clock enable on MCU side
#define BRD_DRV_BCLK_EN_A_PIN                   AVR32_PIN_PX42

///brief Frame sync enable on MCU side
#define BRD_DRV_FS_EN_A_PIN                     AVR32_PIN_PX03

///\brief Master clock enable on MCU side
#define BRD_DRV_MCLK_EN_A_PIN                   AVR32_PIN_PX34

///\brief Mute enable on CON side
#define BRD_DRV_MUTE_EN_B_PIN                   AVR32_PIN_PB01

///\brief Reset enable on CON side
#define BRD_DRV_RST_EN_B_PIN                    AVR32_PIN_PB03

///\brief TX enable on CON side
#define BRD_DRV_TX_EN_B_PIN                     AVR32_PIN_PX58

///\brief RX enable on MCU side
#define BRD_DRV_RX_EN_B_PIN                     AVR32_PIN_PX00

///\brief Master clock enable on CON side
#define BRD_DRV_MCLK_EN_B_PIN                   AVR32_PIN_PX41

///\brief Bit clock enable on CON side
#define BRD_DRV_BCLK_EN_B_PIN                   AVR32_PIN_PX22

///\brief Frame sync enable on CON side
#define BRD_DRV_FS_EN_B_PIN                     AVR32_PIN_PX45
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

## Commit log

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2014-03-17 cs2200.* Added support for RTOS. Also added new functions. Seems function.
    Most of files have been restored due to problems with SSC and USB
    enumeration.
    print_functions.h USART RX and TX are linked with board pins, so it is
    easy to send debug info thru this interface.
    2DO: Solve problem with playing (time to time there are glitches) and
    recording (completly wrong)
    [cs2200.c]
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2014-03-22 SDR-Widget.h Turned off components which are not present. Note: when disable LCD_DISPLAY then USB enumeration not even start.
    print_funcs.h Changed USART baudrate (57600 to 115200) to inprove
    preformance
    uac1_device_audio_task.c Switch which set num_samples according to
    actual frequency. This was key to remove
    glitches on 44.1 kHz.
    usb_descriptors.h Changed USB_MANUFACTER_NAME to "Sonochan mkII".
    Also changed version number.
    [SDR-Widget.h]
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2014-03-22 SDR-Widget.h Removed unused features except LCD. When LCD support is off, then USB enumeraton fail.
    uac1_device_audio_task.c When current frequency is unknown (for example
    not initialized yet) then num_samples is set to
    48, so in default settings everything should
    work as expected (worked anyway, but just for
    case).
    2DO: Try find out why LCD support depend on USB enumeration. Remove
    unused libraries.
    [SDR-Widget.h]
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2014-03-24 SDRwdgt.h Changed used GCLK0 pin.
    taskAK5394.c GCLK0 is now source of MCLK. This allow generate low
    frequencies, that PLL can not.
    uac1_usb_specific_request.c According to actual frequency set correct
    GCLK0 and GCLK1 to get MCLK and BCLK.
    Due to usage of GCLK device now operate as master. However all supported
    frequencies are functional.
    2DO: Remove unused libraries, code and so on.
    [SDRwdgt.h]
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2014-04-03 tlv320aic33* Support for TLV320AIC33 codec (just I2C driver for now). Codec on board work (response to I2C)
    FreeRTOSConfig.h Added configuration for HW bridge uniprot.
    compocite_widget.c Added array for initialize TLV320AIC33 codec. Will be
    removed.
    cs2200.* Version 0.4.1 Added new generic driver functions. Removed
    unused defines.
    device_generic_hid.* Now compatible with uniprot.
    generic_driver.* Updated to version 1.4. FIxed some bugs.
    uac1_device_audio_task.c Removed debug message when frequency is not
    known. On windows it makes UART too chatty.
    uac1_image.c Removed HID task. Added bridge task (in init function)
    Added support for uniprot, HW, HW bridge uniprot and TLV320aic3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
    [SDRwdgt.h, cs2200.c]
2014-04-28 brd_driver.* Board driver. For now just initialize TLV codec to sonochan needs. Seems functional.
    FreeRTOSConfig.h Removed unused definitions, Chagned USB_HID stack size
    and period (lower values).
    conf_usb.h Removed unused defines.
    HW.* Updated to version 1.2.2. Added board driver (TLV and cs2200 driver
    already included)
    HW_bridge_uniprot.* Updated to version 0.4 (fixed negative value issue)
    composite_widget.c TLV initialization is now in board driver which is in
    image_task_init().
    cs2200.* Updated to version 0.5.1 (Fixed some bugs in generic driver
    table)
    generic_driver.* Updated to version 1.3 (Added support for Big endian
    systems, support for 8 bit, 16 bit and 32 bit poi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
    [brd_driver_hw_03.c, brd_driver_hw_03.h]
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2014-05-07 dragon_load_to_flash.bat Added erase command
    LCD_5110.* Version 1.1, but still in testing. However seems functional
    on Big and Little endian systems.
    LCD_5110_HAL_AVR32_UC3A3_HW_interface.* Version 0.1 HAL for UC3A3. Tested on UC3A3256.
    SDRWdgt.h Removed unused defines to make code more clean.
    brd_driver_03.* Added functions "brd_drv_draw_logo",
    "brd_drv_set_isolators_to_HiZ", "brd_drv_pre_init" (which should be
    called before main program set clock source),fixed FreeRTOS support bugs,
    composite_widget.c All necessary stuff is now in brd_drv_pre_init()
    function.
    cs2200.* Version 0.7 Added option for PLL output when changing ratio
    just by 1. Setting freeze bit is now possible al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
    [LCD_5110.c, LCD_5110_HAL_AVR32_UC3A3_HW_interface.c, LCD_5110_HAL_AVR32_UC3A3_HW_interface.h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]
2014-05-08 FreeRTOSConfig.h brd_drv_STACK_SIZE changed to 1024 (if lower, then RTOS failed). Period set up to 600 (60ms, but it can be higher)
    LCD_5110.* Fixed buf in LCD_5110_write_xy() function. Added function
    that re-write one line on display with defined pattern. Added option
    that clear screen when writing again from line 0.
    brd_driver_hw_03.* New functions. Analog input VOLUME_CONTROL now
    control headphone value in dB. Added functions, that allow write
    easily to LCD and debug output.
    composite_widget.c Removed #include "cs2200", now part of brd_driver*
    tlv320aic33.* Added function tlv320aic33_get_headphones_volume_db()
    uac1_device_audio_task.c Fixed bus with "time" variables
    2DO: Co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
    [LCD_5110.c, brd_driver_hw_03.c, brd_driver_hw_03.h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]
2014-05-08 FreeRTOSConfig.h brd_drv_PERIOD set to 1000 (100ms), works fine.
    LCD_5110.* Added function LCD_5110_clear_line(). Fixed bug in
    LCD_5110_set_line() functions (always returned SUCCESS).
    brd_drivder_hw_03.* Support for watching voltage on connector side. When
    voltage is too low or in save range send info through debug output. If
    voltage is too high, then write warning to LCD and debug output.
    Warning disappear when voltage on connector side goes under +5.0 V.
    Added function that clear warning message and write logo.
    2DO: Complete board driver
    Complete tlv320aic33 driver
    Functions to read and write to user flash memory
    [LCD_5110.c, brd_driver_hw_03.c, brd_driver_hw_03.h]
2014-05-08 LCD_5110.* Added option, that clear line every time before wite.
    brd_driver_hw_03.* Mute option now works (button and signal). Reset I2S
    not yet. When initialize configure LCD module. Added functions that
    set MUTE and RESET_I2S direction. Checking connector voltage.
    uac1_device_audio_task.c Modified PLL_CHANGE_TIME_DIFF to 1000 (tested,
    better).
    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
    [LCD_5110.c, SDRwdgt.h, brd_driver_hw_03.c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]
2014-05-13 brd_driver_hw_03.* Completed functions for MUTE signal.
    device_generic_hid.* Renamed task to device_generic_hid_task(...)
    generic_driver.* Changed comment about recommended value
    GD_MAX_STRING_SIZE
    uac1_device_audio_task.c PLL_CHANGE_DIFF decreased to 500 to avoid
    buffer underflow/owerflow. Need more testing
    usb_descriptors.h Changed device PID to 0x0763 to make some difference
    between SDR-Widget and Sonochan mk II.
    MM2E_Stejskal_Martin.odt New revision for Josef Nevrly.
    [brd_driver_hw_03.c, brd_driver_hw_03.h]
2014-05-14 brd_driver_hw_03.* Added functions for generic driver. Now is possible set direction and value of MUTE and RESET_I2S through generic driver. Button RESET_I2S_BTN have 2 modes. When is pressed shortly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
    2DO: Board driver
    TLV driver
    Read/wtite to user flash
    [brd_driver_hw_03.c, brd_driver_hw_03.h]
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2014-05-20 MM2E_Stejskal_Martin.odt New revision (measure informations)
    LCD_5110_HAL_AVR32_UC3A3_HW_interface.h Fixed value of CLK source
    Read/Write to user flash
    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
    [LCD_5110_HAL_AVR32_UC3A3_HW_interface.h]
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2014-08-06 Minor changes (.gitignore, some .bat files and so on)
    tlv320aic33.h Modified condition to resolve architecture
    uac1_device_audio_task.c New algorythm when buffer is close to underflow
    or overflow.
    [tlv320aic33.h]
2014-08-07 brd_driver_hw_03.* Added support for saving settings on user flash. So far support work only for BOARD DRIVER.
    2DO: Git DOC, HW and so on
    Persistent changes for TLV (through board driver or HAL layer?)
    Fix bug: reset I2S button - not work when RESET_I2S is set as output
    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
    [brd_driver_hw_03.c, brd_driver_hw_03.h]
2014-08-08 brd_driver_hw_03.h Fixed bug: RESET I2S now work even if RESET_I2S signal is set as output. If button is pressed, then signal RESET_I2S generate about 1 ms long pulse and then reset I2S connector on 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
    Persistant changes for TLV (probably will do board driver)
    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
    [brd_driver_hw_03.c, brd_driver_hw_03.h]
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2014-08-13 Makefile Removed. Now "bat" and "sh" scripts due to different OS logic. Also simplify portability of code.
    compile_on_* Scripts that allow compilation on Linux and Windows
    README.txt Simple howto compile under windows and linux.
    *_load_to_flash.bat More fixed to AVR Studio 6 on 64 bit or 32 bit
    Windows. All tested.
    makefile (FW/Release) Changed binary name from Widget.elf to
    Sonochan_mkII.elf
    tlv320aic33.* Updated from CodecKit project (support big and little
    endian)
    BOM_Sonochan_mkII_03A.* Updated some parts
    2DO: Optimizations and debug level as variable in main makefile
    Modifi board driver functions and descriptions for generic driver
    Persistant changes for board dr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
    [20140516_Sonochan_mkII_03A.ods, 20140516_Sonochan_mkII_03A.xls, 20140516_Sonochan_mkII_03A.xlsx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]
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2014-08-21 subdir.mk Added ssc.*
    brd_driver_hw_03.* Added test function just for debug. Fixed bug when
    saving settings to flash memory (TX_direction)
    ssc.* Initial version of SSC driver
    tlv320aic33.* Updated to version 0.2a (just alpha version), but fixed a
    lot bugs (mainly because of endianity macro switch). This is still alpha
    version and it is not even complete.
    2DO: Write SSC driver
    Persistant changes (handle board driver)
    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
    [brd_driver_hw_03.c, brd_driver_hw_03.h, ssc.c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]
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2014-08-29 FW/Release/src/*.mk Removed directiry with reference to old ssc_i2s.* driver
    FreeRTOSConfig.h brd_drv task stack size changed to 2048, but may me too
    much. In new versions try to reduce this size
    brd_driver_hw_03.* Fixed bug in generic driver table (function "Mute
    direction" and Set RESET_I2S direction). Changed generic driver table
    order.
    ssc.* Updated. Now work at least initialization.
    taskAK5394A.c Removed ssc_i2s.h dependency
    uac1_taskAK5394A.c ==||==
    uac2_taskAK5394A.c ==||==
    2DO: Function RX sync, TX sync (board driver)
    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
    [brd_driver_hw_03.c, brd_driver_hw_03.h, ssc.c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]
2014-09-01 FreeRTOSConfig.h brd_drv_STACK_SIZE set back to 1024
    brd_driver_hw_03.* Added support FSYNC edge (RX so far), BCLK edge.
    Functions tested, should be all right.
    composite_widget.c Minor changes in debug messages
    ssc.* Minor changes in debug messages. Fixed doxygen documentation
    uac1_device_audio_task.c Changed debug messages (auto tune PLL)
    2DO: Complete function brd_drv_set_FSYNC_TX_edge() - need also support
    in ssc.*
    Persistant changes (so far so good. Most work)
    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
    [brd_driver_hw_03.c, brd_driver_hw_03.h, ssc.c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]
2014-09-03 FreeRTOSConfig.h Size for board driver stack is set temporary to 2048 because of lot debug messages.
    brd_driver_hw_03.* Added new testing function (will be removed).
    ssc.* Fixed initialization (2x set FSYNC edge, now only 1x). When TX
    module set as master (generate FSYNC), then is set correct FSYNC
    condition (default).
    taskAK5394A.c Switching left and right channel for TX (output) stream
    is now possible through setting variable i_switch_LR.
    2DO: Implement FSYNC TX edge function
    Clean up code
    Continue on development SSC and board driver
    Persistant changes (OK so far)
    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
    [brd_driver_hw_03.c, brd_driver_hw_03.h, ssc.c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]
2014-09-05 .gitignore Added some more definitions due to Egit Eclipse extension
    SDRwdgt.h Removed unused definitions.
    brd_driver_hw_03.* Added doxygen comments. MCLK and BCLK is now
    initialized in brd_drv_init(). Added function, that set UACx variable to
    set correct initial settings (support for UAC2 is not compleatly tested
    so far).
    ssc.* Version 0.2. Error and info messages are now as simple macro, so
    when needed, they can be simply disabled in .h file (macro SSC_ERR_FUNC
    and SSC_INFO_FUNC). Default settings (.h file) now have more options.
    Added doxygen comments. SSC I/O pins are now defined in .h file.
    taskAK5394A.c Removed references to SSC I/O pins.
    uac1_device_audio_task.c JUst c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
    [SDRwdgt.h, brd_driver_hw_03.c, brd_driver_hw_03.h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]
2014-09-05 brd_driver_hw_03.* Version 0.3 Tested functions, that set FSYNC RX/TX edge. Added brd_drv_set_digital_audio_interface_mode() which set one of most used mode (I2S, DSP, ...). However support is not co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
    ssc.* Functions not changed, but just modev in code to make it more clear.
    taskAK5394A.* Added functions, that can swap left and right channel in RX
    and TX data stream.
    2DO: Add BCLK frequency function
    Board + SSC driver
    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
    [brd_driver_hw_03.c, brd_driver_hw_03.h, ssc.c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]
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2014-09-11 FreeRTOSConfih.h Changed "TOTAL_HEAP_SIZE" to "1024*40" instead of "1024*50". Reason was random behaviour, which is probalby caused by rewriting wrong memory in RAM. Also added comments, to saw defau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
    brd_driver_hw_03.* Added support for settings MCLK oversampling frequency.
    Tested, so it should work. Added function, which set easily FSYNC clock.
    Fixed function for setting BCLK oversampling.
    cs2200.* Updated to version 0.7.3 (minor changes)
    uac1_usb_specific_request.c Removed some unused comments. Updated function
    that set FSYNC frequency.
    2DO: Add support for different bit resolution
    Support for DSP, left and right justify
    Tidy error, warning a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
    [brd_driver_hw_03.c, brd_driver_hw_03.h, cs2200.c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]
2014-09-12 LCD_5110.* Updated to version 1.2. Fixed function write_xy().
    brd_driver_hw_03.* Version value is now generated as data and time when
    preprocessor is run. So it generate always unique number with date
    stamp, so now can be easily tracked which firmware is actual.
    Support DPS, left and right justify
    Tidy error, warning and info messages in brd_driver_hw_03.h
    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
    [LCD_5110.c, brd_driver_hw_03.c, brd_driver_hw_03.h]
2014-09-16 brd_driver_hw_03.c Minor changes.
    sync_control.h Commented definitions (also on other place). In future
    probably will be removed.
    taskAK5394.h Changed speaker buffer size downto 8 ms at 48 kHz
    uac1_device_audio_task.c Now support 1-24 bit sample length. However, on
    PC side it is still 24 bit device.
    TESTS/audio/* Added new testing wav files. Usefull for debugging.
    2DO: Function for change USB descriptor device name
    Messagess on LCD (FSYNC freq., MCLK freq, BCLK fs)
    Support for DSP, right and left justify
    Tidy error, warning and info messagess in brd_driver_hw_03.h
    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
    [brd_driver_hw_03.c, brd_driver_hw_03.h]
2014-09-16 brd_driver_hw_03.* Added functions, that show actual device settings on LCD. Minor changes in string macro names.
    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
    [brd_driver_hw_03.c, brd_driver_hw_03.h]
2014-09-18 subdir.mk Just changed compilation order (should not influence anything).
    FreeRTOSConfig.h Parametric change. "HID" and "bridge" period changed to
    50, so not communication with PC app is much faster and so far it does
    not look, that sound is affected in any way.
    brd_driver_hw_03.* Added support for setting custom device name (also this
    function change PID because OS Windows store device name and PID in
    registry). Fixed function, that remove error message (also set number of
    errors to 0). Changed button period.
    uac1_usb_descriptors.* Added function, that allow set custom PID.
    usb_descriptors.* Added function that allow set custom name for device.
    2DO: Try to figure out why feedb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
    [brd_driver_hw_03.c, brd_driver_hw_03.h, uac1_usb_descriptors.h]
2014-09-19 brd_driver_hw_03.* Fixed loading settings from flash. Updated Sonochan logo (now show also device number).
    uac1_usb_descriptors.h Just added comment.
    uac1_usb_specific_request.c In function "audio_get_cur()" fixed current
    frequency value (now calculated, not hard defined).
    usb_descriptors.c Macro "Usb_unicode" changed to more low level macro.
    Note: Now feedback EP should work also on Windows 7, but not tested,
    because of windows registry memory :/
    2DO: Tidy error, warning and info messages in board driver
    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
    [brd_driver_hw_03.c, brd_driver_hw_03.h, uac1_usb_descriptors.h]
2014-09-19 brd_driver_hw_03.c Updated according to new tlv320aic33 driver.
    tlv320aic33driver.* New version by Tomas Bajus.
    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
    [brd_driver_hw_03.c, tlv320aic33.c, tlv320aic33.h]
2014-09-25 brd_driver_hw_03.* Changed command order. Updated table metadata. When connector side is not powered, or supply voltage on connector is too low, error message is shown. Also removed some bugs, when s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
    tlv320aic33.h Support for RTOS enabled again :)
    usb_descriptors.h Changed VID to 0x0433 (ALPS)! Please not that when using
    application for PC.
    2DO: When booting, try to remove "freeze" bug, when BCLK and FSYNC is set
    as input (slave, no clock).
    Support for DSP, left and right justify (mainly SSC driver)
    Setting word offset (how many BCLK pulses)
    FSYNC pulse length (in DSP mode)
    delete ssc_i2s.* files when no longer needed (now just re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
    [brd_driver_hw_03.c, brd_driver_hw_03.h, tlv320aic33.h]
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2015-02-19 brd_driver_hw_03.* Just updated version value.
    generic_driver.* Update to version 1.4
    uac1_device_audio_task.c Fixed problem with variable name "index" which
    caused unpredictable errors.
    uac2_device_audio_task.c ==||==
    2DO: When booting, try to remove "freeze" bug, when BCLK and FSYNC is
    set as input and there is no clock
    delete ssc_i2s.* files when no longer needed (now just reference)
    Remove all references to GPIO PX34 (LED indication)
    Symbolic names for GCLK0 and GCLK1 (MCLK and BCLK)
    Functions, that allow set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
    [brd_driver_hw_03.c, brd_driver_hw_03.h]
2015-03-19 ssc_i2s.* brd_driver_hw_03.* ssc.* SNCHN_II-03A* All "FRAME_SYNC" changed to "FSYNC". So now, in whole project is used only "FSYNC". That means same signal name for code and hardware schematics. No m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
    Functions, that allow set precise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
    [SNCHN_II-03A.brd, SNCHN_II-03A.sch]
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2015-05-04 Update because of bootloader (some issues with user flash memory and USB descriptors). Now fixed. Updated scripts for firmware update. Tested on Linux and Windows. Added library for simple configurin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
    Symbolic names for GCLK0 and G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
    [bootloader_cfg.c]
2015-07-06 For first time tested DSP support. Works, but for now most of procedures are just hardcoded. Setting bootloader pin is not magic number anymore (actually in last commit fixed)
    Complete support for DSP, left and right justify (mainly SSC driver)
    Tidy err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
    [brd_driver_hw_03.c, brd_driver_hw_03.h, ssc.c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]
2015-07-07 Added "word offset" option. Tested switching between I2S and DSP (no problem now) As default is still I2S, but to DSP can be switched. Removed ugly tabs and replaced by spaces. Added some "get" funct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
    Complete support for left and right justify (mainly SSC driver)
    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
    [brd_driver_hw_03.c, brd_driver_hw_03.h, ssc.c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]
2015-07-10 In makefile added information about memory usage. Totally removed old ssc_i2s.* driver. Rest in peace. In board driver instead of I2S interface is used Digital Audio Interface (DAI). Setting word off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
    [FSYNC_BCLK_MCLK_freq_overview.ods]
2015-07-16 Added support for MCLK stepping in PPM. However auto tuning PLL have to be disabled to avoid confusion of user. When auto tune is enabled MCLK PPM offset is set back to 0. When auto tune is disabled,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
    [brd_driver_hw_03.c, brd_driver_hw_03.h, cs2200.c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]
2015-07-27 Added udev rules for lazy users + changed manual for setting udev rules. Slightly modified makefile (some parameters were twice) At FreeRTOS configuration file change configMINIMAL_STACK_SIZE. Maybe 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
    At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
    [bootloader_cfg.c, brd_driver_hw_03.c, brd_driver_hw_03.h]
2015-07-27 Changed order in board driver (hopefully it will work)
    At print_dbg() add some resource blocking to avoid messed messages
    at UART output. Really annoying (actual does not work at all).
    Add warning, when word size is smaller than 16 and in actual mode
    codec can not play it properly/at all (DSP for example).
    At SSC driver when changing mode set RX module according to TX module.
    This is way how to avoid problems when changing parameters.
    Remove "MCLK PPM drift" bug when enable/disable auto tune
    Test pr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
    [brd_driver_hw_03.c]
2015-08-02 Bypassed problem with RAM overwriting by removing sprintf(). The sprintf() allocated own memory out of actual task memory. And because there is another task which is created and deleted these RAM mem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
    2DO: Functions that replace sprintf() and shown info to LCD/debug output
    When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
    [brd_driver_hw_03.c, brd_driver_hw_03.h]
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2015-08-25 Probably solved FREEZE problem -> caused by calling function brd_drv_set_FSYNC_freq(), which included "too much" operations and USB task stack probably overflow (or timeout). Because this can not be 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
    [bootloader_cfg.c, brd_driver_hw_03.c, brd_driver_hw_03.h]
2015-08-25 Sorted INFO/ERR messages in board driver. Switching between modes (I2S, DSP, LJF, RJF) should be without word offset issues. Warning messages added to board driver to tell user, that in some cases co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
    2DO: When booting, try to remove "freeze" bug, when BCLK and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
    [brd_driver_hw_03.c, brd_driver_hw_03.h, ssc.c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]
2015-09-02 Build 0.0.1
    Created library for display. Now separated board_driver and display. However
    they are cross dependent (display need to get data from board driver).
    Tested I2S reset (DAI reset) button. Fixed bugs, now work as expected. Problem
    was in setting's loading sequence.
    Slightly modified script for compiling under Windows. Now jump back to actual
    directory.
    Small changes in board driver (mainly removed all functions related to display).
    Added functions "get", which display driver use.
    Added automatic count build number. Tested at Linux and Windows with
    Atmel Studio 6.1 and MinGW. Can be simply configured by build_counter.mak
    Also it is possible to change build numbers manually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
    [brd_driver_hw_03.c, brd_driver_hw_03.h]
2015-09-03 Build 0.0.4
    Updated README (in root and FW folder).
    Added licence terms to header files.
    Removed sync_control.* files which did not do anything at all.
    Added support for DFU programmer at Windows. So for now it is possible update
    FW at Windows by Flip and DFU programmer.
    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
    [LCD_5110.c, LCD_5110_HAL_AVR32_UC3A3_HW_interface.c, LCD_5110_HAL_AVR32_UC3A3_HW_interface.h]
2015-11-22 Build 0.0.39
    Finally solved problem with BCLK/FSYNC freeze bug when setting them as
    input and there is no CLK.
    Automatically removed src/display.o file when building again -> update
    build number also in display.c
    To generic driver added GD_TIMEOUT for signaling timeouts (thanks
    captain obvious).
    2DO: Verify BRD_DRV_MIN_DET_FREQ setting
    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
    [brd_driver_hw_03.c, brd_driver_hw_03.h, ssc.c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]
2015-11-25 Looks like BRD_DRV_MIN_DET_FREQ settings does not work as expected. Anyway device stop freezing, so this is only minor detail.
    2DO: FSYNC pulse length (in DSP mode)
    [brd_driver_hw_03.h]
2017-03-30 Build 0.0.42
    Hopefully fixed issue in slave mode (FSYNC and BCLK in). Problem caused
    data de-synchronization on FSYNC signal. Reason was that function
    brd_drv_set_digital_audio_interface_mode() simply reseted SSC module and
    did not set BCLK and FSYNC direction again. This is fixed in this version
    TLV320AIC use internal PLL to generate MCLK derived from BCLK.
    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
    [brd_driver_hw_03.c]
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2017-09-15 Fixed DSP support. Now default settings should be according to standard.
    [brd_driver_hw_03.c, brd_driver_hw_03.h, ssc.c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]

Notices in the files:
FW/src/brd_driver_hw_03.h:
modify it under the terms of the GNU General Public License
